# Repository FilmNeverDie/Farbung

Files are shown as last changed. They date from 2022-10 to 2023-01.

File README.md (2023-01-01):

# Farbung

Färbung means colouring in German, and all these effor are infact a way of colouring, thus Färbung. 
A open source project based on FilmNeverDie's CP800 film processing machine.

Project: CP800 

This project is initialized and managed by FIlmeNeverDie. Here, we introduce a rotating drum film developer. Film developing machines are getting outdated and they have run out of support, so the project aims to introduce a series of products that could replace old equipment that has no support and is hard to get replacement/maintenance services. This project provides the resources available for on-going maintenance and product support for film processing within an open-source community, so that anyone can pick up the role as a supplier and maker. We also welcome users to make their own adaptation since the need for each user might be different and the existing variation may not be ideal for each application. Please see CONTIRBUTION for how you can contribute to an existing project, or branch off to your own variant of the machine.  

## Project structure 
 
The project is separated into sections: hardware, firmware, and software 

Hardware includes a list of parts, the relevant CAD files, schematics, and respective documentation such as part lists (BOM), datasheet, user manual, maintenance manual, production manual, and certificates. 

Firmware includes the codes for programming the microcontroller, and its respective documentation such as change log, license, dependency. 

Software includes any software that enhance any parts of either the machines or film processing such as simulation, check system integrity and firmware auto-update, the processing programs generators, photo scanning and processing software and their respective documentation such as change log, license, dependency. 

Contributors will be expected writing and updating the manuals for their own variation.  

There will be a list of verified models and compatibility table that shows the combination of hardware/firmware/software compatible in the front page of each project.  

## Getting Started 

Installations 

### Firmware: 

Arduino IDE with libraries: 

- USB Host shield Library 2.0  

- DallasTemperautre + OneWire 

Get the newest stable version of source code and upload to the arduino, please check the hardware version of your machine if you purchased from FND, and download the respective firmware. 

### Hardware: 
Mechanical:
Fusion 360 
Electronics:
KiCAD5

### Software:

N/A 

## Getting Involved 

The following are areas where we are currently working on: 

Chemical tanks system: float sensors, heating 

Mechanically stronger developing tank (either stainless steel, or better printing) 

Firmware optimization to use dynamics memory less than 5kbB. 

Optional joystick modules (Arduino joystick shield), and USB/BT controller (see USB Host shield Library for the list) 

Onboard low noise low dropout voltage regulation instead of relying solely on the switching mode convertors with various quality depending on the source (see the BOM in hardware section) 

Areas that could be potential development: 

Miniature solenoid valves and poly manifolds fitting.  

Compatible microcontroller other than Arduino such as beaglebone, Rpi, Psoc, others 

Processing program generators (web base or standalone) 

A bigger and high-resolution screen, also new UI/UX, don't mind if you can fit a few “extra functions” in for bored operators to do while processing 

A computer application that searches for the newest firmware to download from GitHub for any verified hardware 

Any other suggestions 

## Documentation

This repo uses [mkdocs](https://www.mkdocs.org) to host online documentation. `mkdocs.yml` is its configuration file, and `docs/` is the directory containing the documentation pages.

## LICENSE: 

This work is licensed under a Creative Commons Attribution-ShareAlike 4.0 International License, except for source code which is licensed under the 3-Clause BSD License.

see LICENSE.md and LICENSE_CC-BY-SA.md for details

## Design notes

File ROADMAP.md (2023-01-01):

# CP800 issues:

1.	flow sensors are too troublesome to adjust, 
    -	need better models?
2.	Tanks need to be more rigid:
    -	Stainless steel casing with 
        -	non-conductive surface for sensor
        -	or a fuse in sensor
    -	Strong design of print 
3.	Solenoid valves rust even when expose to moisture. 
    -	Get a model that has no direction contact between the spring and the fluid
4.	New model of CP800
    -	New chassis design
    -	Smaller volume
5.	Photo flow, and demonetized water final wash. 
    -	Last step of the process

# Future project:
1.	CP800 features:
    -	Temperature control
    -	Full error reporting 
    -	Data logging for error
    -	Deep cycle
2.	Patterson auto-loader
3.	Processing movie films
    -	A list of requirements
4.	Roller transport / pull-thru
    -	Brand new model: (include this in github)
5.	Scanner (include this in github)
    -	Graphic card fails often
    -	AI assisted processing
6.	Dip and dunk (include this in github)
    -	Advantage: Minimal physical contact with film
    -	Challenges:
        -	Large clearance if the film is long
            1.	Could dip and dunk side way, so have a long machine instead of a tall machine
        -	Auto film loader in the machine (dark). 
            1.	Clip at one end
            2.	Pull the film out
            3.	Stop when sensed the end
            4.	Clip the canister end
            5.	Load the film carrier to a hanger for transport
            6.	Start dip and dunking
        -	Manually loading to a hanger
        -	Multiple film roll process
            1.	Allow new film to be auto loaded
            2.	Only engage the loader to hanger when film loading is ready
        -	Auto transfer to scanner via a belt drive system
            1.	Unload the film carrier from the dip and dunk’s transport
            2.	Roll into the scanner 
            3.	Warm air blower will dry the film as it roll into the scanner
            4.	Feed the scanned film into storage

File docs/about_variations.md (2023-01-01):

# Variations

> Note: this section is currently empty, but will contain variation-specific documentation.

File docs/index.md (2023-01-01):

# Welcome to the FilmNeverDie CP800 wiki

## Sample photos: C41 on ECN2

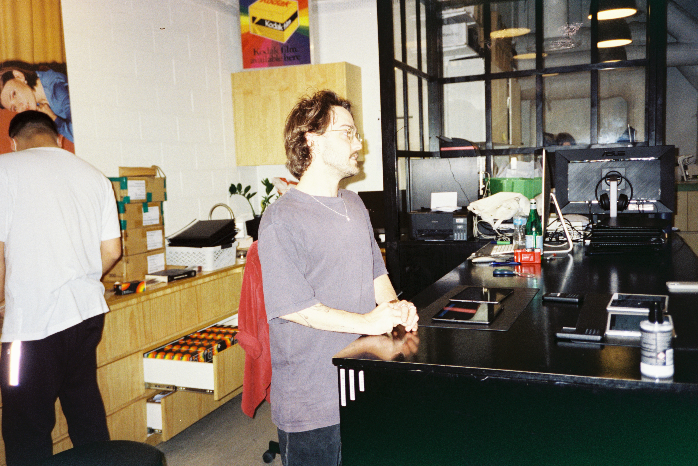
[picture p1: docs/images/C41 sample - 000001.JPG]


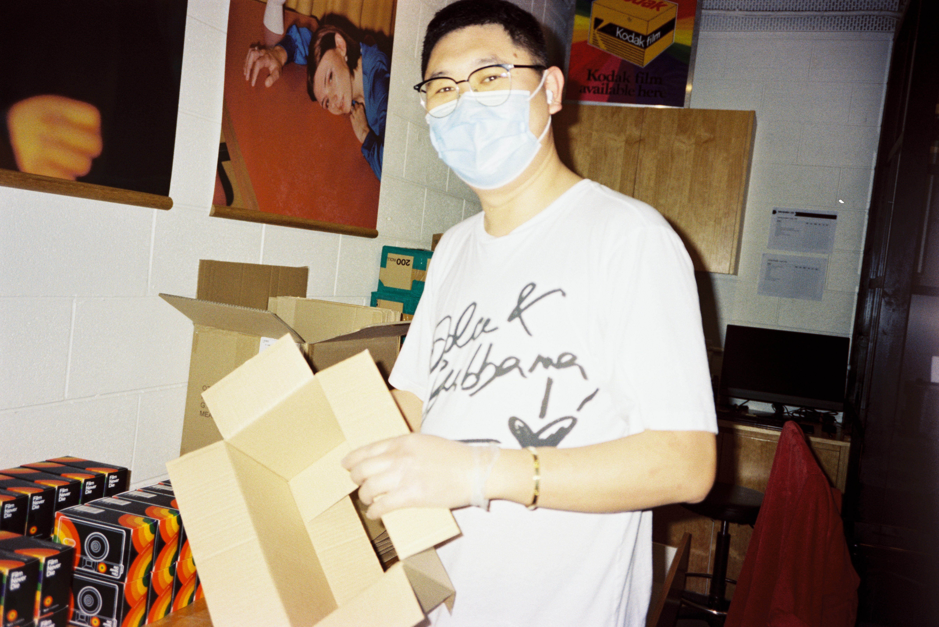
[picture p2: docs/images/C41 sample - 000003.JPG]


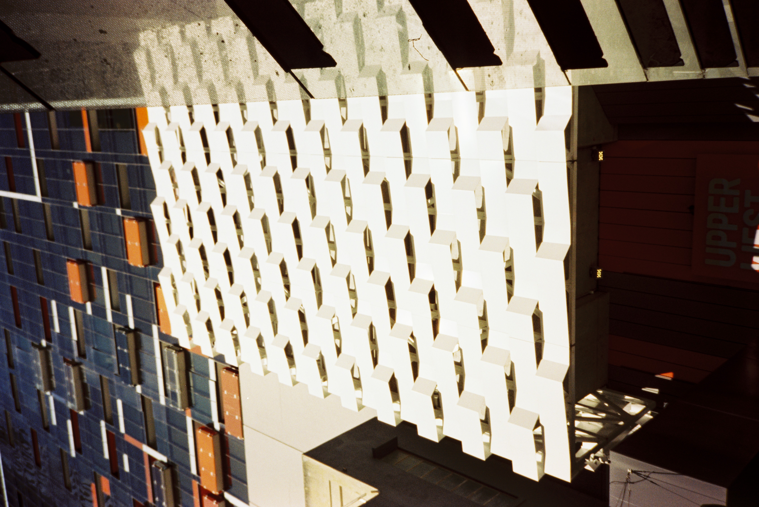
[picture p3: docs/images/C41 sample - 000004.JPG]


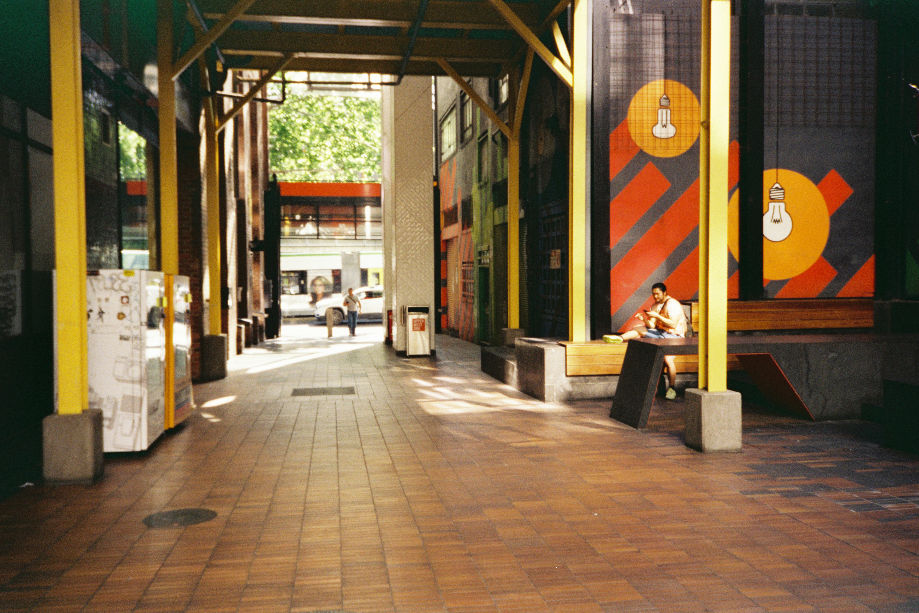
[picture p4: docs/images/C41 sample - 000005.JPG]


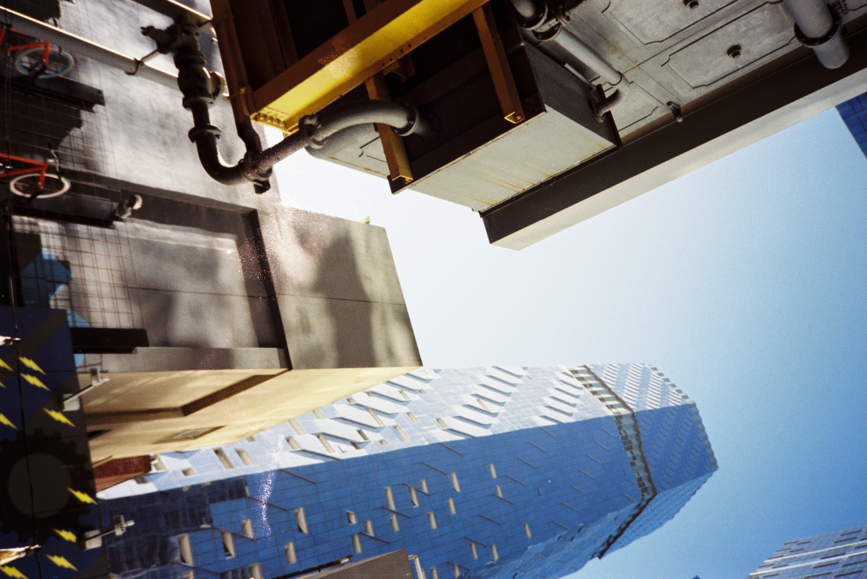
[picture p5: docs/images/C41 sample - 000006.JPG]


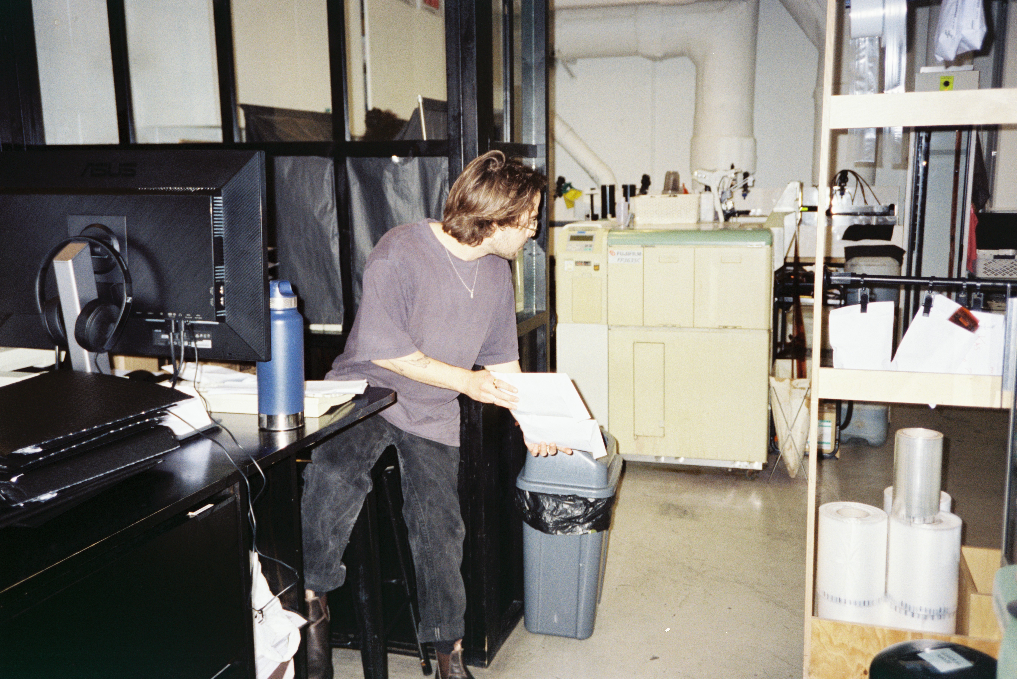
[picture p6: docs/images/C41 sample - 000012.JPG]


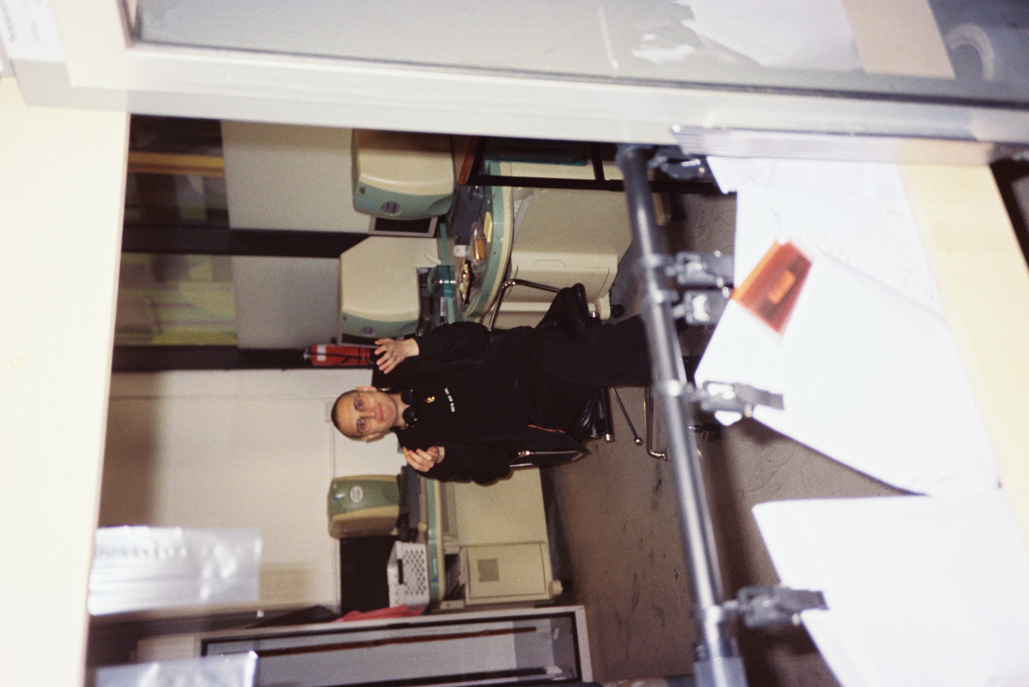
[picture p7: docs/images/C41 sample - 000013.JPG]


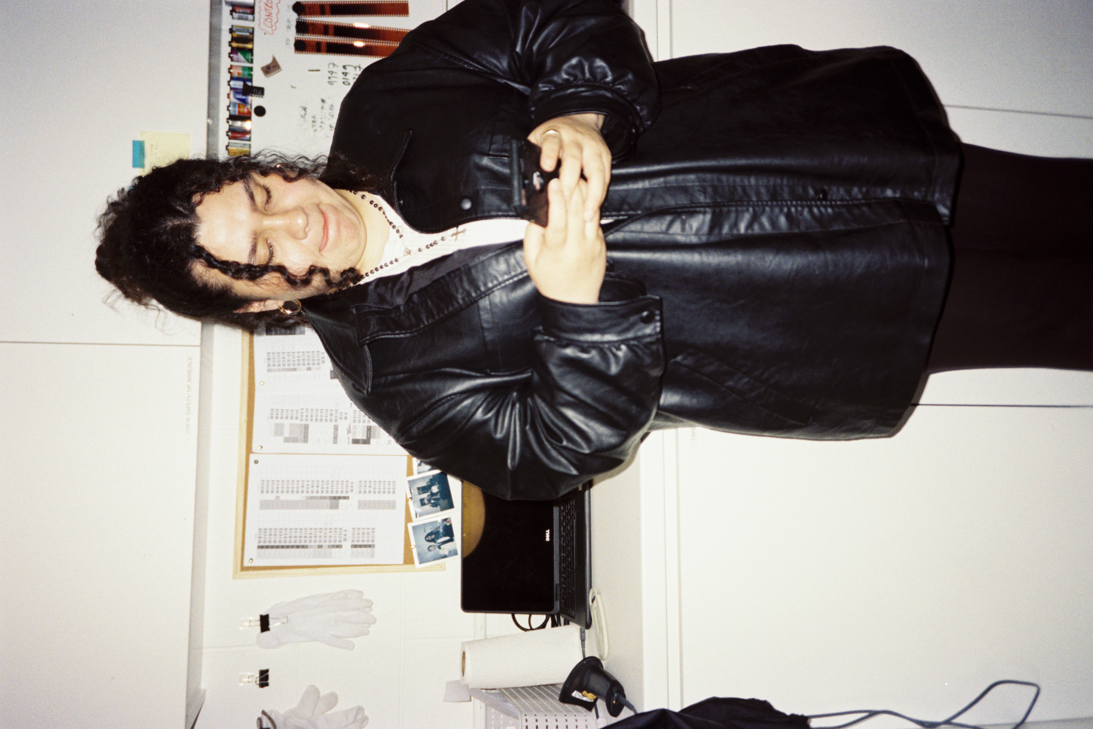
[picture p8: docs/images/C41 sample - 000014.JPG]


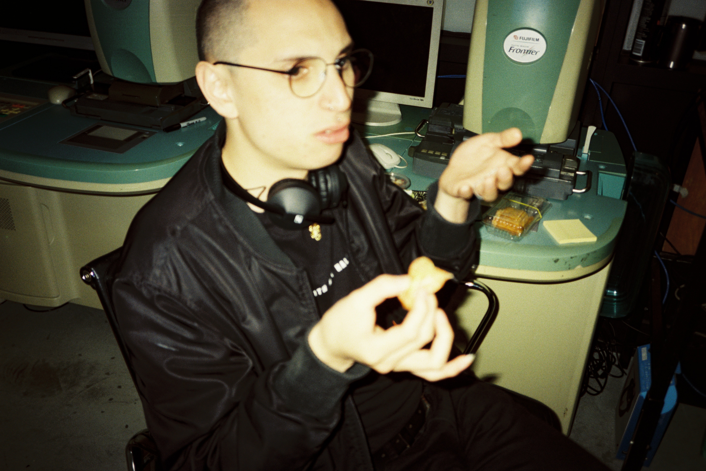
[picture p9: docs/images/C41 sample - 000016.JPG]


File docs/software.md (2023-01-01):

# Software
> NOTE: this section needs a major overhaul, to make it more developer friendly

The user manual has information regarding how to operate the machine. This document is for developers by explaining how the code functions and is structured.

There are a lot of iterations of firmware that are applicable to the microcontroller in CP800. Much of the code is shared between all iteration of the firmware. This document will break the firmware by its function and explain each part of it. There is a log of changes written inside the beginning of the main code so developers track when a feature/function was implemented. Of course, that is not the most comprehensive log, so there might be changes that happened between the recorded date. For the sake of documentation, we assume all data recorded on the log is the date of a committed version of the firmware and all changes to between the commits happen on the latest commit.

# Main Headers

```c
#define model "CP-806"
#define version "1.16.2"
#define PCBver 9
// sense =0 for NO sensor, and =1 for NC sensor
#define OUTsense 0// change this to 1 when use the new flow sensor with the metal band and cable tie
#define INsense 0
```

At the beginning of the code there is a section before the log. This section contains `#define` for the machine. “model” and “version” are not used functionally as of 8th June 2022. However, PCBver is used to define the pinout for the Dpad and user interface inputs. Since there are two functional PCB being used by CP800 as of 8th June 2022. OUTsense and INsense, is used to defined whether the tank level sensor and flow out sensor are normally open (NO), or normally closed (NC) signal. In the future, more metadata could be defined here so other supporting software could identify the machine and hardware associated with that specific model and version of machine.

```c
//#define DEBUG //enable/disable serial debug output
#ifdef DEBUG
#define DEBUG_PRINT(x) Serial.print(x)
#define DEBUG_PRINTDEC(x) Serial.print(x, DEC)
#define DEBUG_PRINTbin(x,y) Serial.print(x, y)
#define DEBUG_PRINTbinln(x,y) Serial.println(x, y)
#define DEBUG_PRINTln(x) Serial.println(x)
#else
#define DEBUG_PRINT(x)
#define DEBUG_PRINTDEC(x)
#define DEBUG_PRINTbin(x,y)
#define DEBUG_PRINTbinln(x,y)
#define DEBUG_PRINTln(x)
#endif
```

`#define DEBUG` serial print via Arduino COM. This allows a global disable on all serial print functions when we don’t want to be debugging. Note that there are still some `serial.print` functions not controlled by this declaration.

```c
void EditsParameters(int editIndex,int arrayIndex,int * Para,int push);
```

There is one function declaration before the main. This function is used to edit existing processing in the ROM. This function required the following dependencies:

- The data type of ROMProgram `struct`
- And Arduino basic library.

> :information_source: NOTE: it is planned to modularize the ROM processing code to have a separate file and header.

The section below the comment:

```c
// button assignment
```

is for the position of each button on the Dpad to the R-2R DAC.
Then the libraries are included below the line:

```c
// includes library
```

Four libraries are active as of 8th June 2022

```c
#include "classes.h"
#include "CP800.h"
#include <OneWire.h>
#include <DallasTemperature.h>
```

`CP800.h` and `classes.h` are defined within the Arduino script folder. LiquidCrystal , `OneWire.h` + `DallasTemperature.h` could be installed and updated with libraries manager on Arduino IDE.

Following the comment:

```c
//pin assignment
```

Are the pin assignments for most GPIO for joystick shield, SPI com, motor interface, valves interface, buzzer, fluid sensors.
For the button variables:

```c
byte UIcommend; // debounced byte commend to the system from UI inputs
byte UIinputs; // before debounced
int de_button;// debounced signal from the Dpad buttons
int editing = 0; // default program editing is off
int menu_skipupdate=0;
```

`UIcommned`, is the debounced 8 bits signal for the microcontroller, this includes the buttons digital inputs with the 6 MSBs. The 2nd LSB indicated whether the cursor can travel through the columns, whereas the LSB indicated whether the cursor can travel through the rows.

`UIinputs` are the raw signal from the 6 inputs from Dpad

`de_button` is the debounced signal for UIinputs

Editing is a flag to indicate whether the user is in editing mode or not, see “editing processing” in the user manual.

`menu_skipupdate` is a flag to control whether the menu is being updated or skipped. Might use a better name

These variables are mainly interfacing with the `UIcursor` and `UImap` classes which contain the information where the cursor is on the menu, and where in the mapping of the menu. The final inputs are input to the `buttonAction` subroutine, where the microcontroller reacts to the new inputs every program cycle.

```c
//LCD
#include <LiquidCrystal.h>
#define rs 42
#define ee 43
#define d4 44
#define d5 45
#define d6 46
#define d7 47 //LCD Pin
#define bl 36
LiquidCrystal lcd(rs, ee, d4, d5, d6, d7);
```

For the LCD, a new library is included, `LiquidCrystal.h`, and a set of pin assignment is `#define` correspondingly to the object imitation of the LCD, see LiquidCrystal object constructor for how to initiate a LCD object with the library.

```c
char lcdBuff0[21];
char lcdBuff1[21];
char lcdBuff2[21];
char lcdBuff3[21];
char lcdBuffPrevious0[21];
char lcdBuffPrevious1[21];
char lcdBuffPrevious2[21];
char lcdBuffPrevious3[21];
```

The LCD screen used has 4 rows of 20 characters. Four `lcdbuffer` are made to store each position of the LCD. Four more are made to store the previous screen which are currently not used.

```c
//menu
//menu structure see attached document
int menuRow = 0;
int menuColumn = 0;
int infopage = 0; //there will be multiple info page as we expand the complexity
const String menuTop[] = { //top tier menu text
...}
const String menuSetting[] = { //declear settings menu
...}
```

`menuRow` is the row number that the cursor/mapping is currently in
`menuColumn` is the column number that the cursor/mapping is currently in
Infopage is the page number that the user is currently viewing
`menuTop` is a character array with words that are shown on the top menu
`menuSetting` is a character array with words that are shown on the setting menu

```c
//edit menu
int editIndex = 0;
int editPara[19]; // edipara is a array, mostly will be only using the first entry
int arrayIndex = 0;
bool editmenuEnd=0;
```

Three variables are declared under editing menu. These variables are used when the user is in editing ROM program mode.

`editIndex` is the index that indicates the current variable the user is editing. Please see EditsParameters function to see how the entire processing program is flattened and how each data is indexed

`editPara` is the value which the index is referring to. There are several types of datatypes, depending on the indexing the data in the array interpreted as different data type, please refer to EditsParameters function for future information

`arrayIndex` is the index for the character array, processName[].

`editmenuEnd` is a flag for rather the edit menu reached the end or not

```c
//I/O Check
bool outputCheckAction = 0;
//Input/Output Check Mode
bool IOCheckMode = 0;
int IOIndex = 0;

```

Three variables are declared to be used when the user is in the IO check mode in the setting menu, see user manual for how to navigate to the IOcheck menu

`outputCheckAction` toggles the action state of each active element of the machine from the menu, typically the component is switched on when this value is 1, such as motor, pump, valve ...etc

`IOCheckMode` indicates if the program is in the IO check menu. This enables the IOIndex to be changed, because the program has entered IO check mode

`IOIndex` is the index that shows which input or output the user is currently checking. Refer to inputCheck() and outputCheck() to see how all inputs and outputs are arranged into an array.

```c
//declear process matrix
String processPara[8][20] = { //6 process + 2 clean process
  {}, {}, {}, {}, {}, {}, {}, {}
};
int processTemp[8] = {0, 0, 0, 0, 0, 0, 0, 0};
uint16_t processTime[8] = {0, 0, 0, 0, 0, 0, 0, 0};
uint8_t processTotalSteps[8] = {0, 0, 0, 0, 0, 0, 0, 0};
bool processParaSet[8] = {0, 0, 0, 0, 0, 0, 0, 0};
//process name
String processName[6] = {"---", "---", "---", "---", "---", "---"};
```

`processPara` is an array of 8 with 20 strings each. String is used here because it is made using the old data format where all parameters are compiled into a String datatype

`processTemp` is the temperature value for each process

`processTime` is the duration of each process

`processTotalSteps` is the number of steps in each process

`processParaSet` is the flag that say whether the process has be set (loaded from storage)

`processName` is the name of the process

```c
//processing data
//timer
unsigned long timer = 0; //system timer (mS)
long timeJump = 0; //jump forward time for testing (mS)
#define iniDelay 200 //delay in setup (mS)
```

Then we will introduce all the data use in processing

For timers:
Long timer is a system timer where it will update every loop

`timeJump` is an accumulated varaibles that will increase or decrease the timer values (currently unused)

`iniDelay` is the delay amount in ms introduce in the for several component when machine is booting up. These include loading processes from ROM, initiating LED, initiating motor.

```c
//refresh timer for lcd etc.
unsigned long refreshTimerA = 0; //timer for less frequent refresh (ms)
unsigned long refreshTimerB = 0; //timer for frequent refresh (ms)
#define refreshInterval 500 //time for lcd refresh (ms)
```

`refreshTimerA` regulate what get update, currently it is at 4 times of `refreshInterval` which is 2s. These processes are LED, LCD, read temperature
`refreshTimerB` regulates what get updated, currently it is at refresh interval rate which is 0.5s. These processes are controlling the motor, controlling the processing, or the cleaning process.

```c
//agitation
byte agitationSpeed = 0; //0: ~20RMP 1: ~18RMP 2: ~16RPM
unsigned long agitationTimer = 0; // S
const int agitationTime1 = 10; // S
const int agitationTime2 = 2; // S
```

`agitationSpeed` determines the speed setting of the motor, this could be expanded to the values of a byte

`agitationTimer` is not used

`agitationTime1` and `agitationTime2` are used to create the pattern of motion during processing. The pattern is forward, stop, backward and stop, then repeat.

```c
//parameter of process
bool processState; //process runing state (0:not running 1:running)
int processNo; //runing process (0-7)
bool steppingmode=0; //default =0 : sensor mode, 1= fixed timer
unsigned long processStartTime = 0; //start time of current process
```

`processState` is the flag showing whether the machine is running a processing or not

`processNo` shows which process from the menu is selected to be processing

`steppingmode` shows how the steps in a process are going to progress. Sensor mode means the step progress to the next step depending on the feedback sensor, fixed timer means the step progress to the next only depending on a fixed amount of time.

`processStartTime` marks the timer instance where a new processing has begun.

```c
//parameter of clean process
byte processStateClean; //process runing state for clean process (0: not runing 1: clean 1 process 2: clean 2 process)
byte processCleanCycles;
```

There are supposed to be two cleaning processes, they are both currently not programmed. From the order of adding and removing fluid. Clean 1 is having the both add and remove are active depending on a processing array.

```c
//parameters for current step
bool stepState = 0; //step state (0: processing of this step is not done 1: processing of this step is done, ready to drain tank)
String stepName[20] = {"----"};
uint8_t stepNo = 0;
uint8_t stepIn[20]; //which port to add chem
uint16_t stepTime[20]; //time for processing (S)
uint8_t stepOut[20]; //which port to dump chem
bool stepPush[20]; //if this step is subject to push/pull 0:no 1:yes
bool flowin=0;
bool flowout=0;
int stepout = 0; // use to record what stepOut[stepNo] is, unused
unsigned int stepTimer1 = 0; // begining of adding chem
unsigned int stepTimer2 = 0; // beigning of process the drum, stopped adding chem
unsigned int stepTimer3 = 0; // begining of removing chem, stpped the drum
bool stepParaSet=0; //flag of step paratmeter are set, and ready to go
//push/pull
int push = 0; // the value of push/pull selected on the menu (this is loaded into the processing later)
```

Within the processing, each step has timing and parameters that define their actions.

`stepState` shows whether the processing of the film in this step is done, if done start draining tank fluid and prepare for the next step

`stepNo` shows sequential order the step is in the processing

StepName shows the name for a step

`stepIn` and `stepOut` shows which valve port which are used in the step

`stepTime` is the duration of the step

`stepPush` enable/disable the step to be pushed/pulled. Push: increase time of processing of this step, pull: reduce time of processing of this step

`flowin` is a flag made to force the chemical to flow in by the user at any time during the step which the processing is currently in

`flowout` is a flag to force the chemical to flow out of port 6 during the process, this is used for emergency flow out in case the other valves are somehow blocked during the processing. Please refer to the user manual.

Stepout is supposed to record the value of stepOut the processing was, so that an interrupted operation could be done and yet the processing could continue by pushing this variable back into stepOut (currently unused)

`stepTimer1` is use to time the adding chemical stage of the step

`stepTimer2` is use to time the rolling processing stage of the step

`stepTimer3` is use to time the removing chemical stage of the step

`stepParaSet` shows whether the step parameters are loaded and ready to go

`push` is the value of how much time are increase/decrease (push or pull) for all the pushable steps in the current processing

```c
//error Message
String errorMessage = "";
unsigned long int popuptimer=0;
```

`errorMessage` is a String for displaying the message when an error incurred

`popuptimer` is a time variable for displaying a message on LCD, this is updated to the newest time, so the popup message will display for a duration of time after this variable is updated

```c
#include <EEPROM.h>
int strByteLen = 200; //String Length limit in bytes
int addrShift = 0; //to shift byte for wear leveling
```

EEPROM is one of the options to store and recall processing, all parameters are stored as a byte array.

`strByteLen` is currently defined as 200 bytes. Detailed structure of the stored array is in the comment section of the CP800.h tab.

`addrShift` is supposed to be a random 8 bits value that shifts the ROM address, in order to achieve wear leveling. The array will have a wrapping order from 256 back to 0. However, the wrapping is not yet programmed. Currently not use.

```c
#include <SD.h>
#include <SPI.h>
#include <stdlib.h>
int SD_err =0; // 0: no err, 1: SD.begin error, 2: file load err, 3: step data load err
int program_no = 0; // count the number of program stored in the SD card file
int loadtype=0; // 1 is SD, and 0 is ROM, default from ROM
int validROMprogram[6] = {1,1,1,1,1,1}; //0: invalid, 1:valid
```

Load all libraries required to use SD module on Arduino

`SD_err` is the value that returns from attempt to initiate the SD module

`program_no` is the number of processing program stored on the SD card; the program indicator is located at the beginning of each processing program. More details for the data structured store on SD card are described in “process_data” tab

`loadtype` determines how processing program is loaded, either from SD card or EEPROM

`validROMprogram` is an array of flags to indicate which programs stored in the EEMPROM have a valid data structure. If there is no legit program header found in each memory slot, the function will change this array of the corresponding index to 0, so loading on those program entries will be skipped.

```c
//digital Temperature Sensor
#define tempPin 27 //DS18B20 signal bus
OneWire oneWire(tempPin); //Temperature chip i/o
DallasTemperature sensors(&oneWire);
//Temperature Control
float tempCurrent = -10.0;
float tempTarget = 22.0;
```

Currently temperature is not use in anyway. This is merely a template for future expansion for now.

#define pin 27 to be the onewire bus

Instantiation of the onewire object to be the define above

Instantiation of the dallas temperature sensor to be the one wire bus device

`tempCurrent` and `tempTarget` are the current and target temperature of the sensor. `tempCurrent` actually doesn’t need initialization.

```c
//instanstation of object
Led Led(LED_woke);
Buzzer buzz(buzz_pin,volume_pin);
SixWay_valve addChem(add_s0,add_s1,add_s2,add_pump);
SixWay_valve removeChem(remove_s0,remove_s1,remove_s2,remove_pump);
agitationMotor agitationMotor(motor_on, motor_dir, motor_PWM);
bathPump bathPump(soak_pump);
//tankLevel tankLevel;
//soakLevel soakLevel;
digilevel drumHI(drum_high,LEVEL_SAMPLE_SIZE, INsense );
digilevel drumempty(drum_empty,LEVEL_SAMPLE_SIZE, OUTsense);
//analoglevel chemtanks_full();
//analoglevel chemtanks_half();
//analoglevel chemtanks_low();
analoglevel soakLevel(tanks_full,LEVEL_SAMPLE_SIZE);
AC_heater heater(heat_PWM);
joystick joystick(KEYA,KEYB,KEYC,KEYD, KEYK, JOYX, JOYY);
Dpad_analog panel_UI(Dpad_in_pin, Dpad_refH_pin, Dpad_refL_pin);
UIcursor user_navi(&UIcommend);
UImap menu_navi(&UIcommend);
```

Now we instantiate all objects needed to operate the machine with the variable we declared previously:

1. LED
2. Buzzer
3. 6ways valve for both inlet and outlet
4. Motor
5. Bathpump, currently no corresponding hardware
6. Digital level sensor for inside the tank and along the outlet tube
7. Analog level sensors are not used
8. The heating element using AC power
9. Joystick shield
10. Dpad interface as the UI
11. The cursor location on the screen is the user
12. The location displayed on the screen is the menu

# CP800.h

This header tab is made to contains classes and global variable for those classes in the CP800 series

```c
#include "pitches.h"
#define arrayLength(array) (sizeof((array))/sizeof((array)[0]))
#include <LiquidCrystal.h>
#include <EEPROM.h>
```

Libraries used in the classes : `pitches.h`, `EEPROM.h`, `LiquidCrystal.h`

`pitches.h`: has the buzzer value to make different notes and function to generate pre-defined tune

LiquidCrystal is the library for display on the LCD

EEPROM is the library for accessing the EEPROM on Arduino

`arrayLength` is to calculate the size of an array using sizeof()

```c
bool zero_crossed=0;
int maxcol=3; //maximum number of col to be display (shift colume by left and right)
int rowstack[8][2];//a matrix that stored the row value for both the user cursor and the menu map
int colstack[8][2]; //a matrix that stored the col value for both the user cursor and the menu map
int actionstack; // the variable to restore which action the menu is selected
String lcdStr[4] = {"", "", "", ""};
int ispageEnd = 0; //flag indicaitng the end of the menu page
int pagerow = 4; //default is four
```

`zero_crossed` is the flag to indicate whether the AC input of the heating has crossed zero. This allows a fixed energy cycle for the PWM cycle within a certain time error

`maxcol` is the variable that allows users to shift left and right in the menu to see different information

`rowstack` is the data matrix that stored the row coordinate of both the user cursor and menu map

`colstack` is the data matrix that stored the column coordinate of both the user cursor and menu map

`actionstack` is the value for the action that the machine is taking, this is normally on the last page in the menu, where the user has to pick a function or run a program. The previously two stacks are for the location of the menu through each layer of the selection on the menu.

`lcdStr` is the array of 4 strings to be displayed on the LCD

`ispageEnd` is the flag for indicating the menu had reached an end page, a page where you have to select an action and no more option to be select after that

`pagerow` is the number of rows on the current menu page. Usually 4 rows, given the screen has 4 rows, but main menu and program selection has more, and allow scrolling down

```c
//this is the view in which the LCD is looking at
struct camera{
  int col;
  int row;
  int row_size;
  int col_size;
};
```

The `camera` struct contain the coordinate of the camera and the size in each dimension to be seen by the camera. Imagine it to be the view range of a person on the map.

# Class UIcursor

```c
class UIcursor {
  private:
    byte* _inputsRef;
    byte _inputs;
    byte _Previnputs;
    int _rowlimit=3;
```

Private variables include:

`_inputsRef` is the pointer to the input variable

`_inputs` is the variable that take the new inputs

`_previnputs` is the variable that stored the previous inputs

`_rowlimit` is restricted to row 3 (4th row) , because cursor cannot move out of the screen

```c
    void limit(int *row, int *col){
      if (*row>_rowlimit) *row=_rowlimit;
      if (*row<0) *row=0;
      if (*col<0) *col=0;
    }
```

The private function `limit()` restricts the value of row and column between 0 to the `upperlimit`, so far only row has an upper limit for the cursor

```c
public:
    int row=0;
    int col=0;
    int layer=0;
```

`row`, `col`, `layer` fully describe the location of the cursor on the map

```c
    //pass the input pointer to the private variable
    UIcursor (byte* inputs){
      _inputsRef = inputs;
    }
```

Instantiate the class by passing a pointer of a byte

```c
    void begin(){
      //initiate inputs
      _inputs = *_inputsRef; //when begin, load the value of the input pointer to _inputs
      _Previnputs = _inputs; // initailise the previous as current inputs
```

Initialize the class by taking the input from the pointer and make previous input the same

```c
// can overwrite the current location of the cursor to any positon on the map
    void wrappoint (int wraprow, int wrapcol, int wraplayer){
      row=wraprow;
      col=wrapcol;
      layer=wraplayer;
    }
```

Public function to edit the current location of the cursor to any value

```c
// update cursor from the inputs given the number of row to be displayed and wehter it is a end page
    void Update(int isEnd, int displayrow){
      _inputs = *_inputsRef;
      _rowlimit = displayrow-1;
      // shift between menu layr with A and B
      // ULRDAB
      bool A = (_Previnputs>>A_shift & 1) & ~(_inputs>>A_shift & 1);
      bool B = (_Previnputs>>B_shift & 1) & ~(_inputs>>B_shift & 1);
      if (A){
        rowstack[layer][2] =row;
        colstack[layer][2] =col;
        //stop incrementing if page is an end page
        if (isEnd!=1){
          rowstack[layer][2] =row;
          layer +=1;
          // new coordinate for new layer
        }else{
          actionstack = row; // which row is pressed on the action page/end page
        }
        // return row and col anyway after pressing A, too hard to see respawn without changes, updated 202011130
        row = 0;
        col = 0;
        if(layer>3)layer=3;
      }else if (B){
        //use 0 to destroy the layer for returning operation
        rowstack[layer][2] = 0;
        colstack[layer][2] = 0;
        layer -=1;
        if(layer<0)layer=0;
        row = rowstack[layer][2];
        col = colstack[layer][2];
        //clear after unloading into the cursor positoin
        rowstack[layer][2] = 0;
        colstack[layer][2] = 0;
      }else{
```

The update function is the core function of the class. It updates the position of the cursor by reading and interpreting the buttons inputs, when the update is called.

The button shift defined in header will now be used to isolate the A and B button, these buttons confirm or cancel an action.

When press A:

1. Stored the current row and column position to the stack
2. If this is the end page, row value is the action option, if not, we increment the layer
3. Then reset row and column position to 0 as we are either doing a new action,
4. Since no page is beyond layer 3, restrict layer increment when reached end, this could be redundant if mapping and tracking is done better
   When press B:
5. Reset current position to zero in stack
6. Decrement layer
7. Load previous layer position
8. Clear the previous location from stack

```c
 }else{
        /*
         * row increment when the down button signal transit from 1 to 0
         * row decrement when the up button signal transite from 1 to 0
         *
         * commend switch to col if the menu allow colum
         *
         * non blocking operation for all direction (could be using in game mode)
         * ULRDAB
         */
        row += (_Previnputs>>Down_shift & 1) & ~(_inputs>>Down_shift & 1) & _inputs& 1;
        row -= (_Previnputs>>Up_shift & 1) & ~(_inputs>>Up_shift & 1) & _inputs& 1;
        // we may not need col position for the cursor
        col += (_Previnputs>>Right_shift & 1) & ~(_inputs>>Right_shift & 1) & (_inputs>>1 & 1);
        col -= (_Previnputs>>Left_shift & 1) & ~(_inputs>>Left_shift & 1) & (_inputs>>1 & 1);
        limit(&row,&col);
      }
      // restore previous inputs
      _Previnputs = _inputs;
    }
};
```

When press other buttons

1. Increment or decrement row value if press up and down while row shift bit is enabled (`_inputs&1`)
2. Increment or decrement column value if press left and right while row shift bit is enabled (`_inputs>>1&1`)
3. Check and limit row and column according to the boundary of the menu page
   Always, update input to previous input at the end

# Class UImap

This class is very similar to `UIcursor`, in fact, it could be position to generalise both `UImap` and `UIcursor` class into one class.

```c
class UImap{
  private:
    //map has a camera datatype to contain the dispaly size and location of the menu
    camera _mapCam;

    byte* _inputsRef;
    byte _inputs;
    byte _Previnputs;
    int _rowlimit=3; //default typical 4 row, 0-3

    void limit(int *row, int *col){
      if (*row>_rowlimit) *row=_rowlimit;
      if (*row<0) *row=0;
      if (*col<0) *col=0;
```

All except the inclusion of camera struct is the same as `UIcursor`. Camera structs allow `UImap` not only the position but the range of location that is visible

```c
    void begin(){
      _mapCam.row=0; //start at the top
      _mapCam.col=0; //start at the left
      _mapCam.row_size = 4; //default dispalying 4 row of character
      _mapCam.col_size = 19;//default dispalying 19 character
      //initiate inputs
      _inputs = *_inputsRef;
      _Previnputs = _inputs;
    }
```

Initialize class with camera values, and camera sizes are fixed

```c
void wrappoint (int wraprow, int wrapcol, int wraplayer)
```

Exact same function as `UIcursor`

```c
    void Update(int isEnd, int displayrow){
      _inputs = *_inputsRef;
      _rowlimit = displayrow-1;
      // shift between menu layr with A and B
      bool A = (_Previnputs>>A_shift & 1) & ~(_inputs>>A_shift & 1);
      bool B = (_Previnputs>>B_shift & 1) & ~(_inputs>>B_shift & 1);
      if (A){
        colstack[layer][1] =col;
        if (isEnd!=1){
          rowstack[layer][1] =row;
          layer +=1;
          // new coordinate for new layer
          row = 0;
          col = 0;
        }else{
          actionstack = row;
        }
        if(layer>3)layer=3;
```

Update mirror the `UIcursor`

```c
      }else{
      /*
        row += (_Previnputs>>Down_shift & 1) & ~(_inputs>>Down_shift & 1) & _inputs& 1;
        row -= (_Previnputs>>Up_shift & 1) & ~(_inputs>>Up_shift & 1) & _inputs& 1;
        // we may not need col position for the cursor
        col += (_Previnputs>>Right_shift & 1) & ~(_inputs>>Right_shift & 1) & (_inputs>>1 & 1);
        col -= (_Previnputs>>Left_shift & 1) & ~(_inputs>>Left_shift & 1) & (_inputs>>1 & 1);
        limit(&row,&col);
      }
      _mapCam.row = row;
      _mapCam.col = col;
      // restore previous inputs
      _Previnputs = _inputs;
    }
};
```

The camera will also be updated.

# Class Buzzer

This class required the `pitches.h` header

```c
  private:
    uint8_t _in_pin,_rh_pin,_rl_pin;//inputs, reference high, reference low
    int _init_volt,_init_rh,_init_rl; //initial reading of each pin
    int _new_volt,_new_rh,_new_rl,_dVolt; // new input of each pin, and a change of voltage value
    int _old_volt=0; //old voltage value
    int _threshold = 15;//default threshold to ignore noise is 9 over 1024 volt
    float _shift_ratio=0; //the rati of voltage shift over the refrence voltage range as a linear scale from initial volts to new volts
    int _ref_range;// range of reference voltage , reference high - reference low
    bool _button_reg_set=0; //default assume release
    bool _edgetrigger=0; //edge trigger flag
    long _edgetiming=0; //edge trigger timing
```

`_in_pin`, `_rh_pin`, `_rl_pin`, are the Dpad input pin, high voltage reference pin, low voltage reference pin respectively

`_init_volt`, `_init_rh`, `_init_rl`, are the initialise reading, in `Begin()` from the input pin, high voltage reference pin, and low voltage reference pin respectively

`_new_volt`, `_new_rh`, `_new_rl` are the new reading from the input pin, high voltage reference pin, and low voltage reference pin respectively

`_dVolt` is a variable to calcualte the difference between two votlage reading

`_old_volt`, is the `_new_volt` in the previous update

`_threshold` define the deadband in which the program ignore the fluctuation of the voltage reading in the input pin

`_shift_ratio` is a ratio to represent relative voltage change, the full equation wil be defined in `Update()`

`_ref_range` is the variable used to store the value between the high and low reference voltage

`_button_reg_set` is a flag is indicate whether a button is pressed, 0 is pressed, given input are pulled up

`_edgetrigger` is the flag for an edge has been triggered

`_edgetiming` is the timing when the edge triggered.

> :information_source: NOTE: might be neater to compress these pin reading into a data array, and the update operate could iterate through the variable instead of calling each variable individually.

```c
class Buzzer {
  private:
    uint8_t _buzz_pin; //which pin is the buzzer
    uint8_t _vol_pin; //the voltage of the buzzer (1 of two preset value)
    uint8_t _welcomeMelody[2] = {NOTE_B5,NOTE_A5}; // welcome tones
    uint8_t _welcomeMelodyDuration[2] = {250,250}; //duration for welcome tones
```

Buzzer has 4 private variables;
`_buzz_pin` contain the pin number for the buzzer
`_vol_pin`, controls the MOSFET that boost the current to the buzzer
`_welcomeMelody` is a two notes array that make noise when bootup,
`_welcomeMelodyDuration` is the timer period for each note in the welcome tune

```c
  public:
  //Constructor
    //constructor without volume pin
    Buzzer(uint8_t buzz_pin){
      _buzz_pin = buzz_pin;
    }
    //constructor with both pin and volume
    Buzzer(uint8_t buzz_pin,uint8_t vol_pin){
      _buzz_pin = buzz_pin;
      _vol_pin = vol_pin;
    }
```

Two constructors

1. Without volume control
2. With volume control

```c
// play any single note
    void play_Note(int Note, int duration){
      tone(_buzz_pin,Note,duration);
    }
    // play an array of notes
    int play_array(uint8_t Note_ary[], int note_len,uint8_t duration_ary[], int dura_len){
      //check either of them are empty
      if(note_len==0||dura_len==0){
        return 2; //type 2 error: empty inputs
      }
      // check if the duration matches the Note in size
      if (note_len != dura_len){
        return 1; //type 1: error array doesn't matches
      }
      for (int playnote=0; playnote<note_len; playnote++){
        //cychle thru each note in array with cooresponding duration
        tone(_buzz_pin,Note_ary[playnote],duration_ary[playnote]);
      }
      return 0;
    }
```

Play note function only play one note with one duration

Play array function cycle thru all the note in array and match the duration

```c
// rountine to play welcome tune
    void welcome(){
      play_array(_welcomeMelody,2,_welcomeMelodyDuration,2);
    }
    // routine to play nothing
    void no_note(){
      noTone(_buzz_pin);
    }
```

The `welcome()` subroutine plays the welcome tune using `play_array()`

There is a subroutine that play nothing

```c
    // inistilising the buzzer pins
    void begin(){
      pinMode(_buzz_pin, OUTPUT);
      pinMode(_vol_pin, OUTPUT);
    }
```

Initialize class by setup buzz and volume pin as output in Arduino

```c
    //write high
    void vol_HI(){
      digitalWrite(_vol_pin, HIGH);
    }
    //write low
    void vol_LO(){
      digitalWrite(_vol_pin, LOW);
    }
};
```

`vol_hi` function connects the buzzer ground with a low resistor value using MOSFET, low resistor more current thus louder

`vol_lo` function cut off the buzzer ground with a low resistor value using MOSFET

# Class Dpad_analog

```c
class Dpad_analog{
  //digital Dpad would be separate to avoid excessive memory allocation
  public:
    byte status_reg = 0b11111100; //button inputs are pulled high
    //status reg that show which button is being pressed
    //NOTE: the full voltage of the DAC is about 82.6% of the uC HIGH output

    //constructor
    // 10 bits analog input version , CP-800 use this
    Dpad_analog(uint8_t input_pin, uint8_t ref_high_pin, uint8_t ref_low_pin){
      _in_pin = input_pin;
      _rh_pin = ref_high_pin;
      _rl_pin = ref_low_pin;
    }
```

Dpad `status_reg` records the status of the Dpad which are the 6 buttons inputs plus row and column shift enable bit at the end

Constructor with inputs to `_in_pins`, two analog pin for the high logics voltage and low logics voltage

```c
    void begin(){
      pinMode(_in_pin, INPUT);
      pinMode(_rh_pin, INPUT_PULLUP);
      pinMode(_rl_pin, INPUT);
      _init_volt = analogRead(_in_pin);
      _init_rh = analogRead(_rh_pin);
      _init_rl = analogRead(_rl_pin);
     // _old_volt = _init_volt; //record init voltage input as previous voltage input
    }
```

Initialisation routine define

1. `_in_pin` as input, output from DAC IC
2. `_rh_pin` as input pulled up, for high voltage
3. `_rl_pin` as input, externally pulled down, for low voltage
4. Read all inputs pin to initialize values

```c
    // check if there is a update on Dpad inputs
    int checkupdate(){
       return(_old_volt>_new_volt+_threshold || _old_volt<_new_volt-_threshold);
    }
    int Ispressed(){
      return 1-_button_reg_set; //return 0 if pressed
    }
```

The `checkupdate()` routine return 1 when new value is `_threshold` difference from the old values

`Ispressed()` returns 0 when a button is pressed

# Future development

- Optimization of RAM usage
  - Remove global variables that are not used
  - More modularized code and use local variable.
  - Better way to store tune and menu option (mainly const chr/int)
- More buttons and better structure button classes
  - Currently the respond is are only 6 buttons, directions + AB, this should be expanded to respond to a more complex controller and allow more action from the user
  - Allow a more efficient way to quick travel to another location or return to previous location, A systematic set of coordinates in the mapping might help.
  - The structure for the mapping on the menu and cursor should remain separated, imagine the cursor is the user’s character, and it is navigating the menu as if it is an RPG. Both the POV of the environment and the chr have to react to the user’s inputs.
- Better ROM read/write addressing. Currently the ROM programs are referring to a set of fixed addresses. This could result in an imbalance number of read/write for some memory unit, and thus worn out those units quicker than others.
  - New writing methods should consider the health of each ROM unit and maximize their life by using dynamic indexing, to avoid overwriting existing ROM units.
  - The new method should also repeat old information in a new region. It would be ideal to reuse a step from another processing cycle than write a new step, since many step between different processing can be shared, such as rinse with water.
  - maybe using wear leveling technique to use each ROM cell evenly. However, this might nullify the ROM.update() function where data is only update when there is a change to it
  - Better still, to use a data compressing method that maximised reusing existing variables and trimmed data to be stored.
- Better code organization
  - Tabs can be combined/separated according to their function/hardware/other arrangement
  - There could be a classification of different header for different purpose, to further modalized the codes, this might allow an entire feature to be reuse in another project.
- UI
  - Generise `UIcursor` and `UImap` with a navigation class that has position value

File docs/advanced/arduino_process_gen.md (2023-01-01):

# Instruction: writing program with Arduino script

This is for developers and makers only; the SD card should be programmed
with a more user-friendly method such as web apps. this Arduino script
used to program the SD card is for generating examples for testing the
functionality of loading programs from Sd card, as the name suggests, it
is made to test to store program on SD cards.

Please locate the arduino code: `test_storeProgams.ino`, and make a copy
for you to change the programs. Keep the original file, so it is a
backup.

Please follow the hookup guide to setup the hardware and Arduino before
you make a change to the script. We are using the big SD module, but
they all work in the same way as long as they are hooked up correctly
for the SPI communication.

<https://randomnerdtutorials.com/guide-to-sd-card-module-with-arduino/>

<https://create.arduino.cc/projecthub/electropeak/sd-card-module-with-arduino-how-to-read-write-data-37f390>

## Step 1: Setup the constants

There are three sections of constants you need to define just after the
headers



The first set is the pin assignment for the SD card port, please refer
to the Arduino board for the pin number of the SPI communication

The second section only has one constant that is the name of the file
where you stored the programs, on default it should be a misspelt
document called "progroms.txt", this file could also be renamed later
use a PC by editing the filename.



The last section is the file specific constant, these describe the
general configuration for all the programs hold in this file

The constant of numberofprogram indicates the number of programs you
wish to store in the fie. The constant array of stepName is a lookup
table for the stepCode to indicate what each step is in each process,
please expand the list of stepName with as many variations of step you
have on your machine.

## Step 2: filling in the parameters

There are two set of parameters that need to be filled out, one set is
for each processprogram on the programlist. These parameters describe
the processes of all programs in the files.

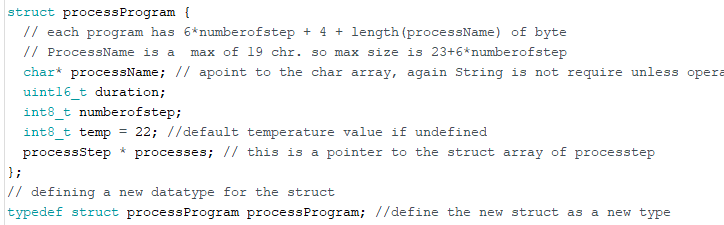
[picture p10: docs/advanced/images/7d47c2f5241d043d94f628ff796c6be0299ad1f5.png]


The structure of `processProgram` contain a
`processName`, the duration of the entire process, the number of steps in
the process, and the temperature of the entire process, following by the
pointer to an array of process steps that contain the parameters of each
step.

Change these parameter is the `setup()` section of the code.
`ProcessProgram` should be right after `Serial.begin(115200)`;

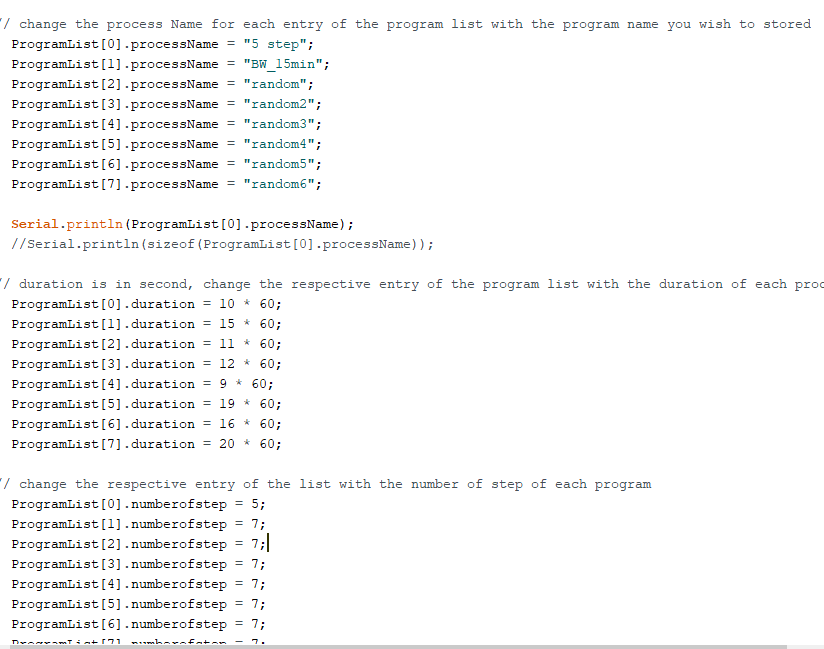
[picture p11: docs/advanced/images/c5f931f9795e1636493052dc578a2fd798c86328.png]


1.  Name your program within the ProgramList array for each processName
    variable. This could be any name as long as it is below 20
    characters long

    > NOTE: due to the constraint of the memory on the Arduino, it could only
    > load up to 6 different programs, so `ProgramList[6]` and
    > `ProgramList[7]` will never get use.

2.  for each program, type the duration in second to the duration
    variable in each `ProgramList`. Min value: 0, max value: 65,535

3.  type the number of step for each program on `ProgramList` array.
    Min value: 1, max value: 255

4.  type the temp for each program on `ProgramList` array. Min value:
    1, max value: 255

There is no need to define the processes now, we will do it in the next
section.

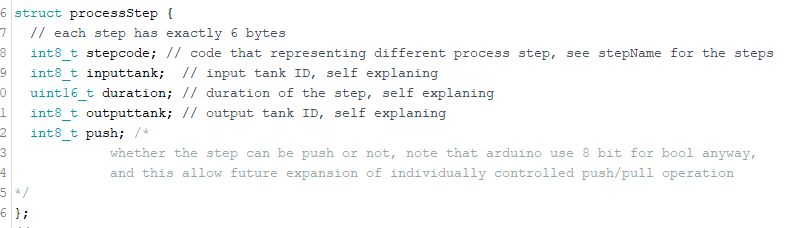
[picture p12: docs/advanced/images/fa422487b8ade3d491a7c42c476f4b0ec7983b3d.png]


The other set is for each step within each
program on the program list.

In each step of the process, the step contains the stepcode where
`stepName[stepcode]` return the name of the step, the input tank number,
the duration of the step where the film is bath in the chemical, and the
output tank number, and a flag to indicate whether the step can be
push/pull.

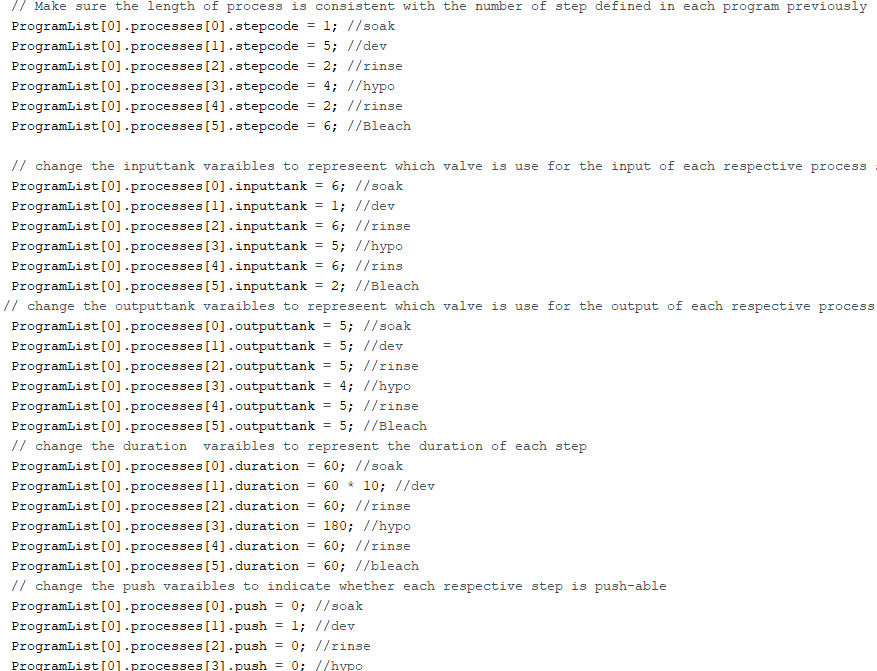
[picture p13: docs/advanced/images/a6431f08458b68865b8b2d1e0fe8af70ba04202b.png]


Please copy and paste each line for the variables: `stepcode`, `inputtank`,
`outputtank`, `duration`, `push` to the number of steps you define in the
program section. And then change the value of each variable within the
structure.

The default code contains 8 different programs and the value for the
parameters are placeholder values. Please add more by copy and pasting
the entire list of steps for each program to the number of programs you
defined in Step 1. Please remember to change the index of `ProgramList` so
you are writing a new program in the list not overwrite the old one you
copied the list of steps from.

For each step, the 5 variables of each step have to be filled within
each program. The index should be consistent with the number of steps
you defined in the respective index of program on the ProgramList. The
default should be a long list of placeholder values. Please edit the
code so that the index of process is consistent with the numberofstep
variable defined. None of the step should be skipped or left blank.
These steps should be repeated for each program on the ProgramList.

1)  Step code is the code representing the name of the step from the
    `stepName[]` array defined in Step 1. min value: 0, max value: 255

2)  `inputtank` is the solenoid valve you want your step to use for the
    input chemical, CP800 only has 6 input port, so the valid range of
    value is 1-6 inclusive, any other number will cause error. min
    value: 1, max value: 6

3)  `outputtank` is the solenoid valve you want your step to use for the
    output chemical, CP800 only has 6 input port, so the valid range of
    value is 1-6 inclusive, any other number will cause error. min
    value: 1, max value: 6

4)  Duration is the duration for the step, do not confuse it with the
    duration for the program you defined for the program. Min value: 0,
    max value: 65,535

5)  Push indicate whether the step is pushable, 0 mean no, and 1 is yes.
    If the step is pushable, the push and pull value given before the
    start of the processing will affect the duration of this step, only
    accept 0 or 1 value, anything bigger than 1 is equal to 1. min
    value:0, max value:1

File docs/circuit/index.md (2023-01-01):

# Description
The CP800 circuit is designed to fulfil the function of developing films
with drum rolling and it consists of the following requirements

1)  Control the fluid flow of developing film

2)  Control the temperature of the fluid

3)  Control the motor for the rolling action

4)  User interface

## List of features in planning

Please read this in conjunction with the software plan, since back-end
development of the software will be highly tied with the hardware
development.

-   Multiple heating element array control, if each storage chemical
    needs to be kept at a different temperature

-   Temperature PID controller (software)

-   Allow the use of 100VAC, there will be a transformer to step down
    higher AC voltage to 100VAC, this allows the machine to work in
    country with a different phase voltage, by converting them all to
    100VAC.

-   Program the microcontroller to control the backlight of the LCD
    screen if required. (software)

-   Program that allows a selection to read from the digital input of
    the Dpad via the serial output from the shift register. (software)

-   Implement an on and off software button using the LED button mounted
    on the Dpad. (software)

-   Earth all solenoid to a common point.

-   Overvoltage and undervoltage protection

-   Quick self-diagnosis button or additional debugging display (led on
    communication\...etc)

-   Float sensor feedback for each storage tank

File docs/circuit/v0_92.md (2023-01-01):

# V0.92 (in machine after )

Changes:

1)  Removed pull up resistor for direction pin of the motor

2)  Number of extra pins reduced

3)  One additional IDC socket for joystick shield

4)  Pin out header socket for USB host shield, required one additional
    stacking pins

5)  Removed the extra ICSP pins, it is now used by the USB host shield

6)  Use one 5V LDO (AMS1117) onboard required low voltage input of at
    least 6.5V

7)  Arduino mage gets power from Vin around 6.5V and signals powered
    from onboard 5V LDO (AMS1117)

8)  One PISO shift registers for Dpad buttons input are available
    instead of the R-2R ladder analog output to buttons

9)  Red onboard LED for reverse voltage input for both 12V and low
    voltage terminals

10) Green onboard LED for forward voltage input for both 12V and low
    voltage terminals

11) Mounting holes increase from M3 to M4, holes position remains the
    same

12) Size of board increase in the X-axis

## Power circuit

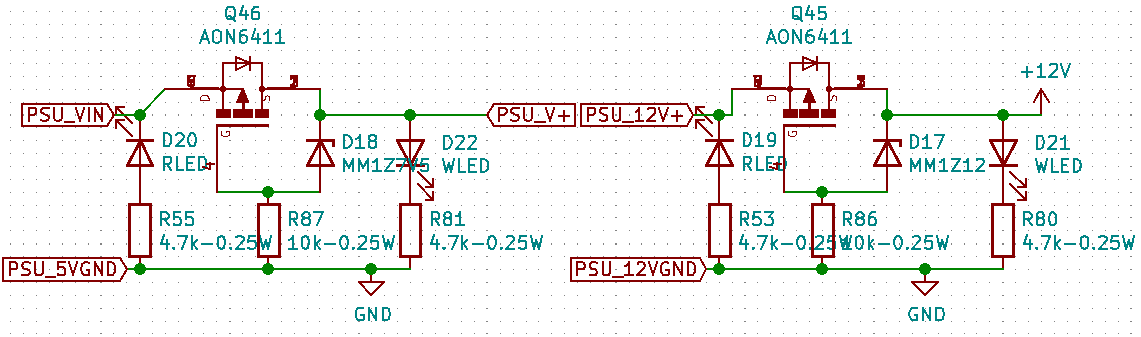
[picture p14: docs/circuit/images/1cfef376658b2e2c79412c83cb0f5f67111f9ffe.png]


Both 12V and low voltage (6.5V) from the external switch converter are
reverse polarity protected with low on resistance p-channel MOSFET and
Zener diode.

When reverse polarity occurred, the pMOSFET will shut down the main
circuit from the high voltage side, but the red SMD LED will turn on as
an indication for the user that they had reversed the input leads

When the correct polarity is inserted, the pMOSFET will shunt the high
voltage side leads, and activate the green SMD LED.

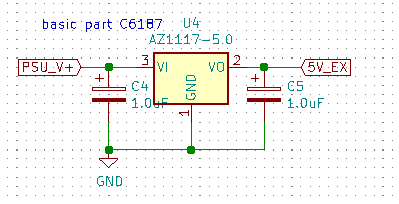
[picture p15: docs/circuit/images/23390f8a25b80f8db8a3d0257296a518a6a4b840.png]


One additional 5V regulator is implemented to share the loads required
by the 5V sources. This is the same chip as the 5V LDO on the Arduino
mega pro mini

In the schematics diagram, 5V is the one powered by the Arduino, while
all 5V_EX connection is powered by this additional chip.



There are four power connectors, one is the input from the 12V PSU, one
is the 12V output after the reverse polarity protection, one is low
voltage input from the buck converter, and the last one is an extra
header for a 5V reference.

## Pumps control

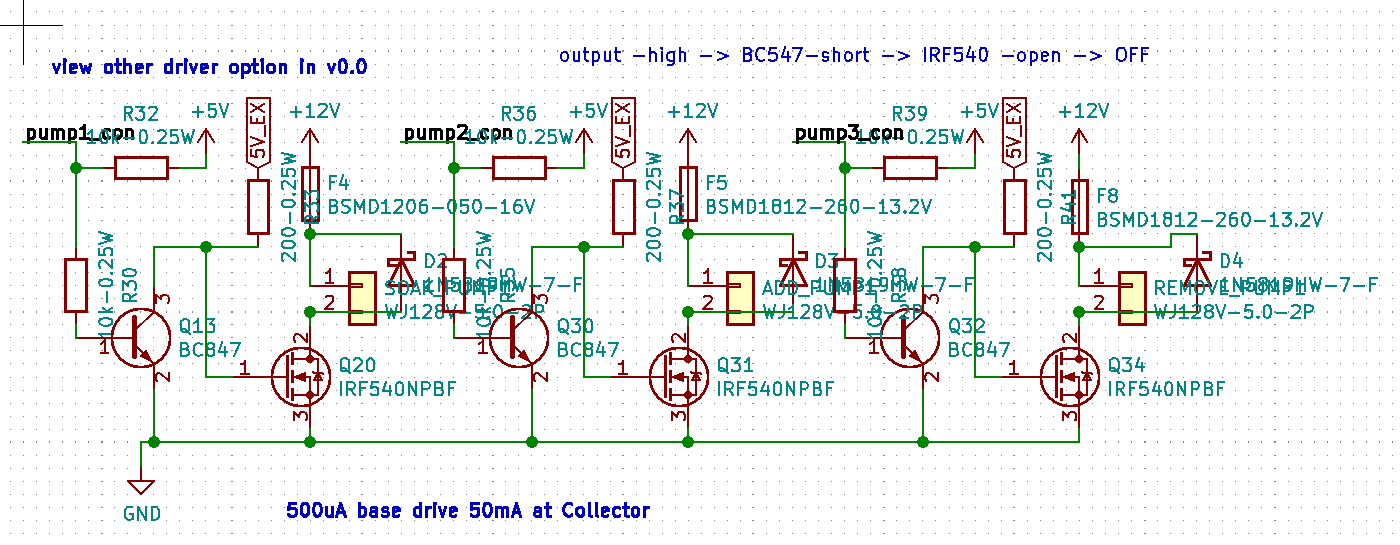
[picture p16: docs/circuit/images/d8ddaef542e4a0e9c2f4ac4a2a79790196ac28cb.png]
Remain unchanged

## Motor control

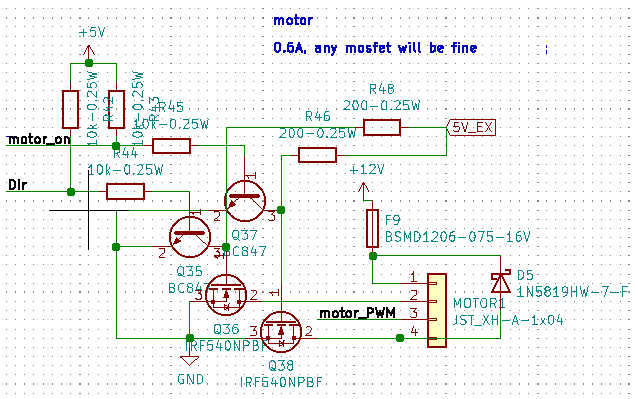
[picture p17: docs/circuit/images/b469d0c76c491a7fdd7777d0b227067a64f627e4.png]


The only changes made are the direction pin of the motor. Now the pin is
left floating/disconnected if it is not shorted to GND for backward
direction

The change is made because the motor we used is not a raw motor, it is a
DIR and PWM controlled motor. Therefore, there is a controller board
inside the motor assembly. Depending on the quality of the motor, if
there is a current path inside the motor assembly, the additional pull
up resistor outside the assembly will affect the voltage level on that
pin.

Also, according to the product datasheet, the DIR pin could be left
disconnected for forward direction, thus proving there is an internal
pull up inside the motor assembly.

The rest is the same as the previous version.

## Solenoid valves control

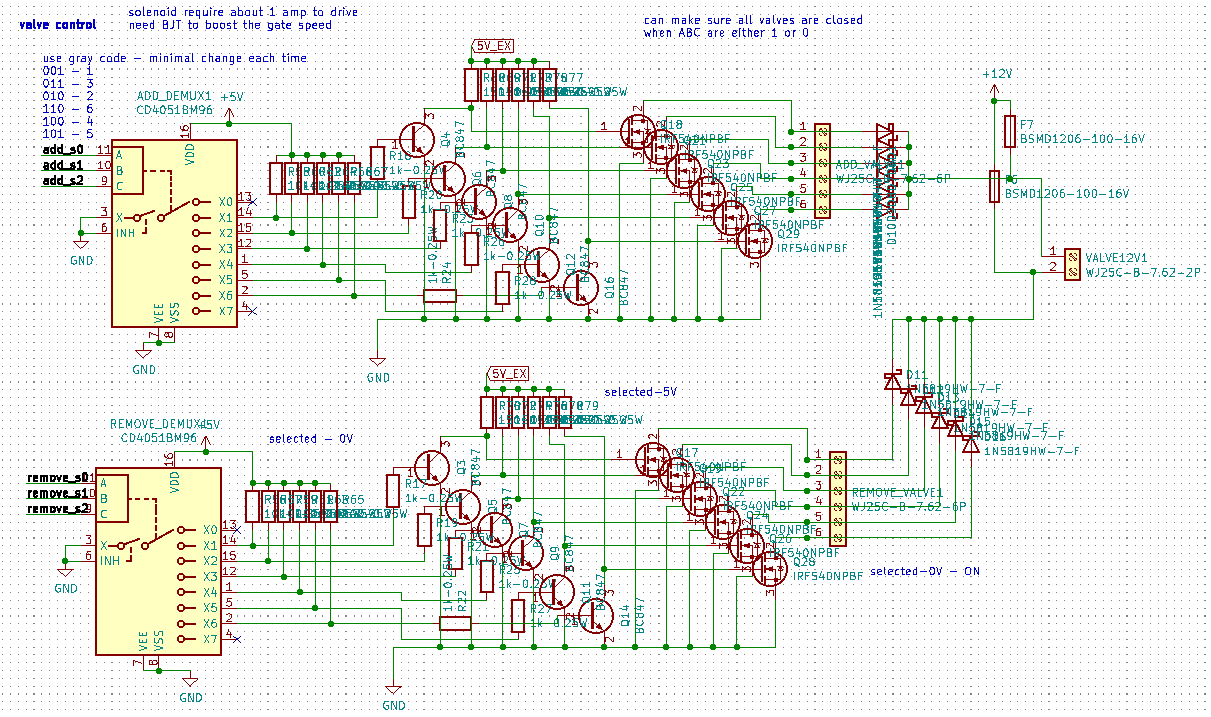
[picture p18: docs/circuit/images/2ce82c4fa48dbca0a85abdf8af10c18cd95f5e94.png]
Same as previously

## User interface

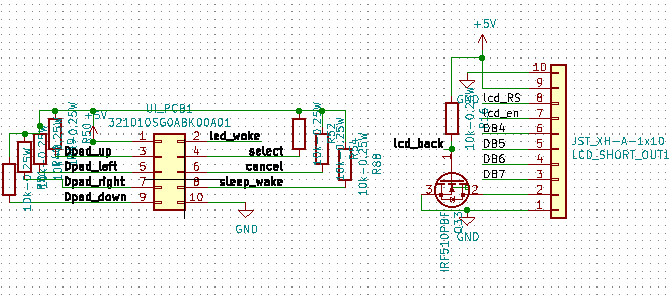
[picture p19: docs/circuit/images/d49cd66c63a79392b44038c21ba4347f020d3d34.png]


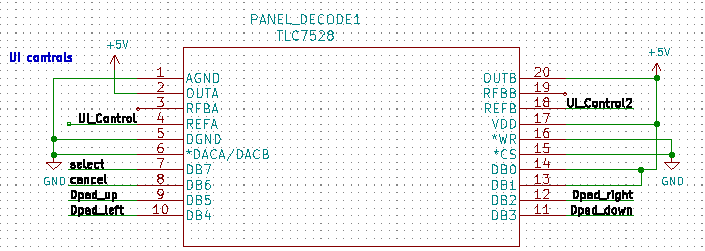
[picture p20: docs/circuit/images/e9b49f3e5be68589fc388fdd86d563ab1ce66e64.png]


The Dpad function works as previously

In v0.92, there are two additional components added for the user
interface

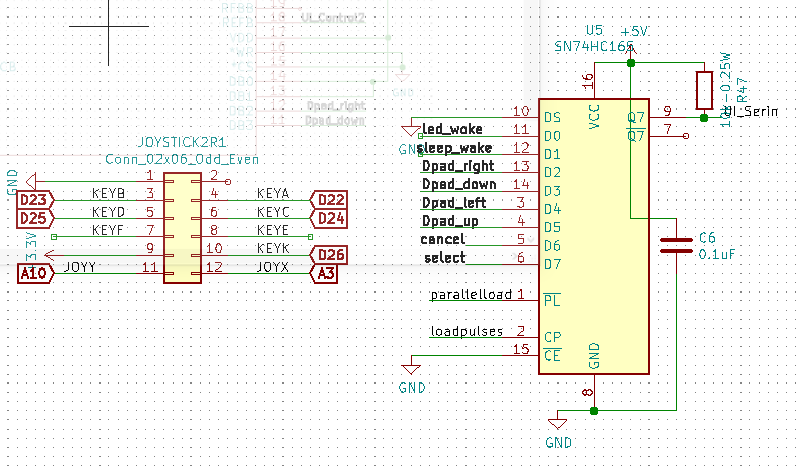
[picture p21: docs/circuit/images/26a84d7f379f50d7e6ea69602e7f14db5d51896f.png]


Firstly, the 12ways IDC connector allows the microcontroller to
interface with Arduino joystick shield. Since we don't plan to use key E
and F, they are left disconnected with the microcontroller here. This is
a optional addon, the Dpad functions as usual without the connection
with joystick shield, and the joystick shield will work simultaneously
with the Dpad.

The addition of a parallel in and series out shift register allows pure
digital signal to be transmitted to the microcontroller for all the Dpad
buttons. This required additional programming that allowed the signal to
be read via the UI_Serin input for all 8 buttons.

## Heating element

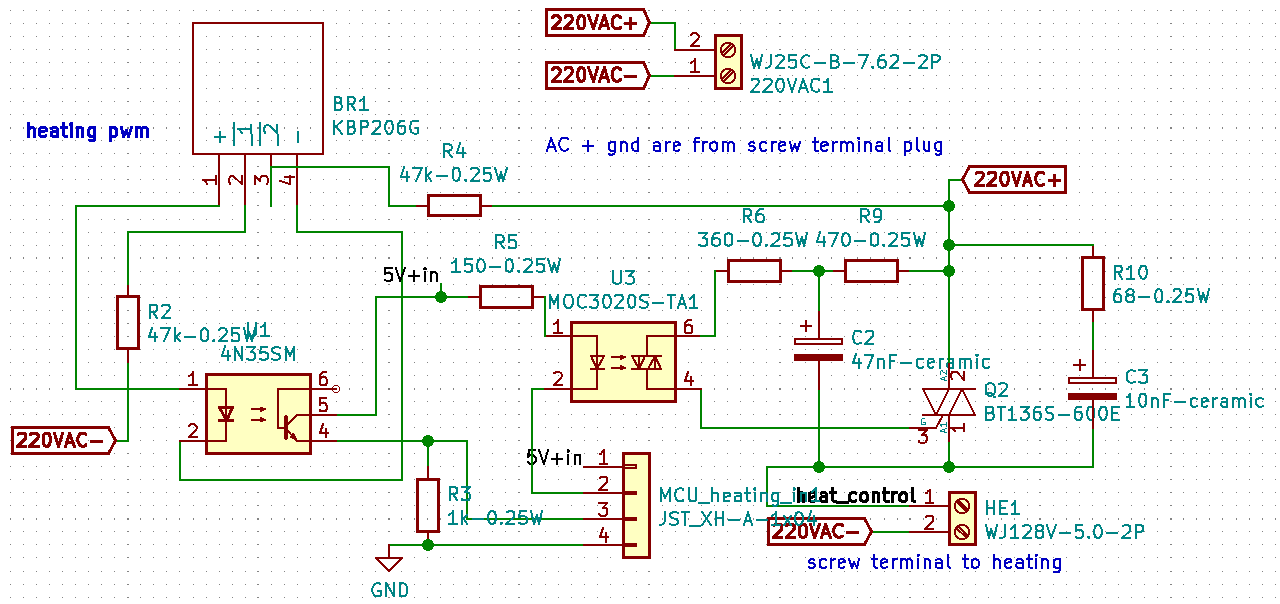
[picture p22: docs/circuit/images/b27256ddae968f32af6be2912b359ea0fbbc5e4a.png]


Same as previously

But, DO note that MOC3020, and 4Nm5 might need to be changed to other
equivalent components due to availability.

## Arduino USB Host shield dock

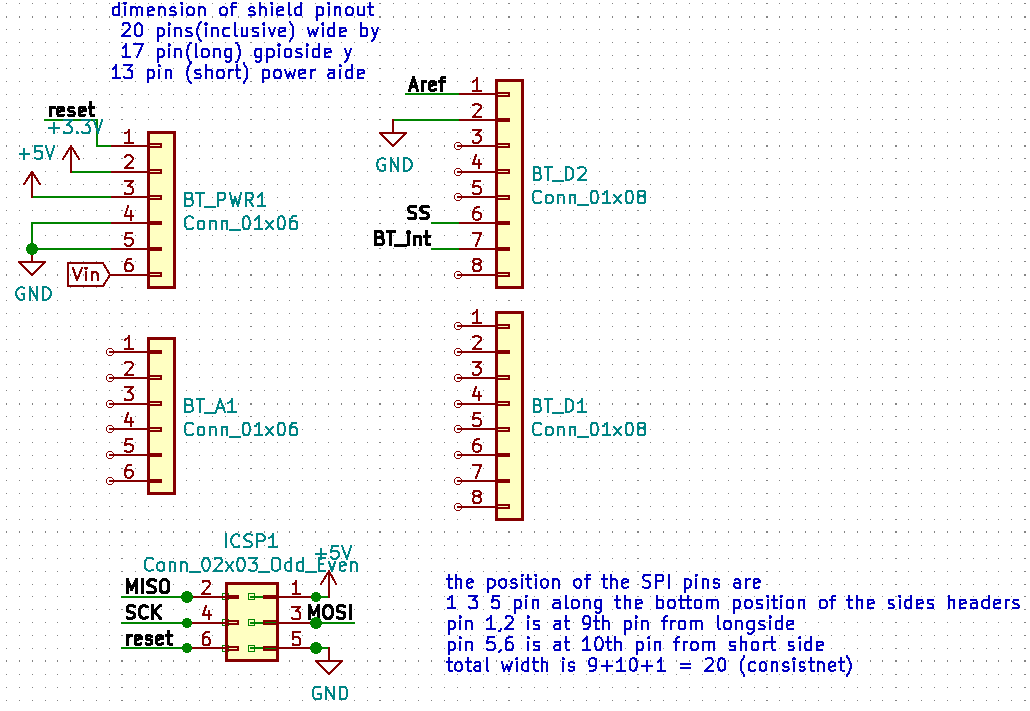
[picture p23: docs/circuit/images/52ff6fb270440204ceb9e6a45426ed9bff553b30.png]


This layout allows the Arduino USB Host shield to be connected simply by
docking it over these docking headers. Most of the bypassing digital and
analog pins from the shield are unuse. They are included for structural
reasons.

The USB host shield converts the USB signal into SPI interface to the
microcontroller.

This has been tested and used with a Bluetooth USB dongle, and
communicates with a PS5 controller to act as the user interface to
navigate the menu.

## Sensors

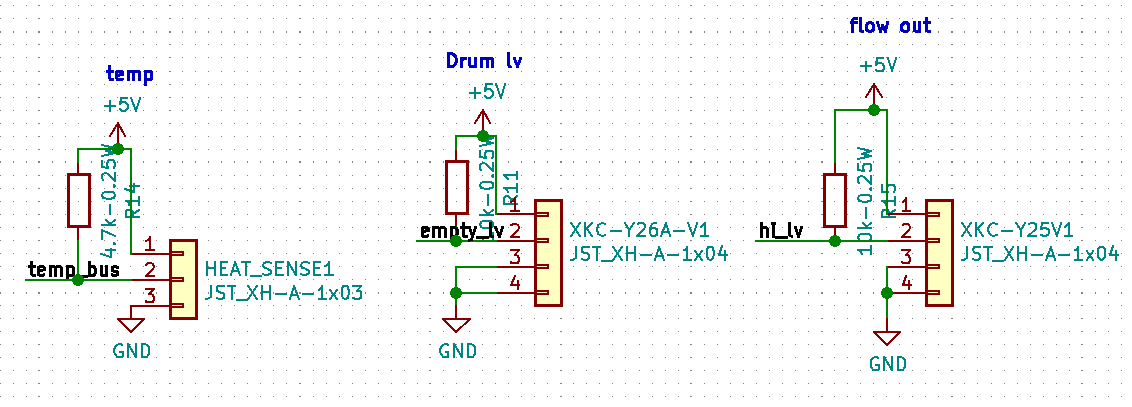
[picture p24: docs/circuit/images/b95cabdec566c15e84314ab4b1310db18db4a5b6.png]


Same as previously

## Buzzer



Same as previously

## Communication Ports



Same as previously

## Microcontroller pinout

The left side of the picture is the header arrangement
on the board for docking the arduino board. The right is the labeled
pinout of the Arduino.

A additional fuse is added to the Vin to the Arduino board, since in
v0.9, power is feed via the 5Vport of the Arduino bypassing the 5V LDO
onboard.



Extra pin unused pin is group to an extra IDC header for future
expansion. This has been significantly reduced due to the module
expansion and component compatibility from v0.9 to v0.92.

The firmware is made backward compatible, so the program being uploaded
to this board that processes all the added component to this iteration
of PCB can also be uploaded to v0.9 without causing a bug. However, all
new features in v0.92 will not reflect on v0.9 unless the corresponding
extra pins are wired externally.

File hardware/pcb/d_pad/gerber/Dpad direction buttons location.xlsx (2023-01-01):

 | nx | ny
up | 98.425 | 60.833
down | 98.425 | 85.979
lef | 85.852 | 73.406
right | 110.998 | 73.406
A | 138.938 | 68.453
B | 126.238 | 84.963

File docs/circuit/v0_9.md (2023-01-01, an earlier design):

# V0.9

The original working prototype for CP800

The function of the board is broken down into the following sections:

1)  The power transfer to each of the components below

2)  The pumps

3)  The motor

4)  The fluid sensors feedback

5)  The solenoid valves for flow control

6)  The user interface

7)  The heating element

## Power circuit



Both 12V and 5V comes from the external switch converter and are reverse
polarity protected with low on resistance p-channel MOSFET and Zener
diode.

The Arduino is powered via the 5V pin bypassing the LDO that required a
higher voltage to power. And all 12V and 5V components will be supplied
by these two voltage sources.



There are four power connectors, one is the input from the 12V PSU, one
is the 12V output after the reverse polarity protection, one is 5V
voltage input from the buck converter, and the last one is an extra
header for a 5V reference.

## Pumps control



There are three output ports for pumps. They are 2pin output.

Each pump is driven by a power MOSFET to switch them on and off with a
low side BJT transistor as the gate driver.

A high output in the microcontroller will allow gate to discharge thru
the BJT quickly, and achieve a faster turn off of the pumps. Meanwhile,
a low output on the microcontroller will turn the BJT off, and the
MOSFET gate is charged thru the low resistance pull up resistor, to
achieve a regulated turn on time.

The pull up resistor in the microcontroller signal pin is implemented in
the case where these pins are not programmed. The pull up resistors will
ensure the pump is off when these pins are not programmed.

Fuses are installed to prevent over current, and a flyback Schottky
diode is used to limit voltage surge by the induction load from the
pumps.

## Motor Control



The motor control is very similar to the pump control as they are both
inductions loading presumably.

The motor we are using has 5 pins control: PWR, DIR, PWN, FB, GND. We
don't use the current feedback wire, so it is left out of the port
output intentionally.

The motor is then connected to the 4 pins JST XH output on the board.

In order to turn on the motor, we need the PWE pin to be 12V, and the
GND pin to be 0V. There is a fuse of the appropriate current to limit
over current, and there is a flyback Schottky diode to limit voltage
surge.

Both DIR and GND pins are controlled by power MOSFETs to switch between
12V and 0V. A pulled up resistor of 12V is in place for the DIR pin, so
there is a default DIR of rotation for the motor, if the pin is left
hanging.

The low side BJT allows a quick discharge of gate, and the low
resistance pull up allows a fixed time fast charging up to the gate.

The pulled up in the microcontroller pins are to make sure the DIR and
0V pin are forced to 12V and keep the motor off, if these pins are not
programmed by the microcontroller.

## Solenoid valves control

Both add and remove valves are controlled in the same
way. Since solenoid is a highly inductive load, we have to apply a
voltage of 12V across each pair of contact on the solenoid block.
Similar to motor and pumps, a fuse to protect from over current and
flyback Schottky diode for voltage surge.

Each solenoid is switched on and off by a MOSFET with a low side BJT
driver for fast drain in gate and a pulled-up resistor in case of
unprogrammed microcontroller pins to the demultiplexer, CD4051.

## User interface



There are two connectors between the motherboard and the Dpad board.
These control the user interface. The 10ways IDC connector is the
connection with each button and LED on the Dpad. The 10ways JST XH
header is the signal going to the LCD screen.

The screen is turned on and off by MOSFET, the program is currently
locked to stay on. Future programming is required to control the
backlight.



The signal from the Dpad will be processed by a DAC with a R-2R
structure, to convert the 6 inputs from the Dpad to a binary coded 8bit
voltage. Note that only UIcontrol analog signal is used, the second
output is left connected. Now.

## Heating element



The heating element chosen is one that is powered by AC 240V input, at
the connector, HE1.

KBP206G is the rectifier to convert AD into DC voltage.

The 4N35SM photocoupler will convert the rectified wave and generate an
on and off 5V signal to the microcontroller to locate the zero-crossing
point of the input wave. This will allow the microcontroller to align
the output from this zero-crossing moment if necessary.

MOC3020 is the photocoupler, between DC to AC using a triac. This
component allows the microcontroller to sink the current at the cathode
(the negative, pin 2) of the MOC3020 diode. Allowing the microcontroller
to control the pulse powering the heating element by driving the BT1365
triac.

R6, R9 and C2, are there to protect the MOC3020 from load, and R10 and
C3 form the snubber to protect the triac.



Additional cutout on PCB to increase the effective isolation between the
240V on each contact of the rectifier.



The AC circuit is located at a different part of the PCB, and the pinout
for controlling the heating element is done by a 4ways connector as
shown above. A jumper cable will be required to connect this connector,
MUC_HEAT_OUT1, with the one input 4ways connector, MCU_heating_IN1,
connection the MOC3020 and 4N35 IC.

## Sensors



There are three main sensors: temperature, tank high level, and flow out
sensor

Temperature sensor is currently unuse, it is supposed to serve as the
feedback to control the heating element. It is using a one-wire bus to
transmit its digital data. The sensor used here is DS18B20.

The tank high level sensor is a 4 pins socket connecting to a
capacitance sensor mounted to the tank and will trigger a on signal when
the water level is raised.

The flow out sensor is a 4 pins socket connecting to two capacitance
sensors clipped to the outlet tubbing from the tank to the solenoid
valve, and will trigger a signal when they sense the tube has fluid
inside.

## Buzzer



A buzzer is integrated to the board, this allows the program to give out
audio clues to the user/operator when things happen. See software
documentation to see the list of audio clues.

## Communication Ports



There are two types of communication port accessible from the boards via
three ports:

There are two I2C ports, 4 ways, with one of the port has an extra set
of pulled up resistor for a new additional device

There is a 16way IDC SPI communication port. This is currently used for
the SD card module. The hardware is suitable for any SPI device. The
parallel pin socket allow another device to be piggy-back to the same
port.

## Microcontroller pinout



A pinout diagram of the microcontroller to all the other components on
the board. Some basic components such as transistor and resistor are
added depending on the signal the pin is interfacing with. This would
change depending on the programs being uploaded to the microcontroller.



All the extra pins are tentatively grouped to an IDC header for future
development and expansion.

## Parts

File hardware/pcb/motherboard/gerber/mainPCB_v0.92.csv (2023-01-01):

Comment | Designator | Footprint | LCSC
WJ25C-B-7.62-6P | REMOVE_VALVE1,ADD_VALVE1 | TerminalBlock:WJ25C-B-7.62-6P | C14864
321016SG0ABK00A01 | SD_LOGGER1 | Connector_IDC:IDC-Header_2x08_P2.54mm_Latch_Vertical | C429960
4N35SM | U1 | Package_DIP:DIP-6_W8.89mm_SMDSocket_LongPads | C433446
MOC3020S-TA1 | U3 | Package_DIP:DIP-6_W8.89mm_SMDSocket_LongPads | C115464
AZ1117-5.0 | U4 | Package_TO_SOT_SMD:SOT-223 | C92105
SN74HC165 | U5 | Package_SO:SOIC-16_3.9x9.9mm_P1.27mm | C61060
321010SG0ABK00A01 | UI_PCB1 | Connector_IDC:IDC-Header_2x05_P2.54mm_Vertical | C429962
WJ25C-B-7.62-2P | VALVE12V1,220VAC1 | TerminalBlock:WJ25C-B-7.62-2P | C8422
KBP206G | BR1 | footprints:KBP206G | C244328
Conn_01x08 | BT_D1,BT_D2 | Connector_PinHeader_2.54mm:PinHeader_1x08_P2.54mm_Vertical | C27438
Conn_01x06 | BT_PWR1,BT_A1 | Connector_PinHeader_2.54mm:PinHeader_1x06_P2.54mm_Vertical | C40877
SFN-1207PA7.6 | BZ1 | Buzzer_Beeper:Buzzer_12.6x7.0P7.5 | C360605
100nF-ceramics | C1 | Capacitor_SMD:C_0402_1005Metric | C1525
47nF-ceramic | C2 | Capacitor_SMD:C_1206_3216Metric | C106083
10nF-ceramic | C3 | Capacitor_SMD:C_1206_3216Metric | C107201
1.0uF | C4,C5 | Capacitor_SMD:C_0402_1005Metric | C52923
0.1uF | C6 | Capacitor_SMD:C_0402_1005Metric | C1525
MM1Z12 | D17 | Diode_SMD:D_SOD-123 | C86234
MM1Z7V5 | D18 | Diode_SMD:D_SOD-123 | C87634
RLED | D19,D20 | LED_SMD:LED_0603_1608Metric_Pad1.05x0.95mm_HandSolder | C2286
WLED | D21,D22 | LED_SMD:LED_0603_1608Metric_Pad1.05x0.95mm_HandSolder | C2290
1N5819HW-7-F | D1,D2,D3,D4,D5,D6,D7,D8,D9,D10,D11,D12,D13,D14,D15,D16 | Diode_SMD:D_SOD-123 | C2891704
321024RG0ABK00A06 | EXTRA1 | Connector_IDC:IDC-Header_2x12_P2.54mm_Horizontal | C601956
BSMD1206-050-13.2V | F3 | Fuse:Fuse_1206_3216Metric | C883123
BSMD1206-050-16V | F4 | Fuse:Fuse_1206_3216Metric | C883124
BSMD1206-100-16V | F6,F7 | Fuse:Fuse_1206_3216Metric | C883131
BSMD1812-260-13.2V | F5,F8 | Fuse:Fuse_1812_4532Metric | C883159
BSMD1206-075-16V | F9 | Fuse:Fuse_1206_3216Metric | C883128
WJ128V-5.0-2P | HE1,ADD_PUMP1,SOAK_PUMP1,REMOVE_PUMP1,7V-PSU-IN1,PSU_12VOUT1,PSU_12V1 | TerminalBlock_Phoenix:TerminalBlock_Phoenix_MKDS-1,5-2_1x02_P5.00mm_Horizontal | C8269
JST_XH-A-1x03 | HEAT_SENSE1 | Connector_JST:JST_XH_B3B-XH-A_1x03_P2.50mm_Vertical | C144394
Conn_01x04 | I2C_TANK1,I2C_CP8000 | Connector_PinSocket_2.54mm:PinSocket_1x04_P2.54mm_Vertical | C2718488
Conn_02x20_Odd_Even | J1 | Connector_PinSocket_2.54mm:PinSocket_2x20_P2.54mm_Vertical | C50982
Conn_02x03_Odd_Even | ICSP1,J2,J3 | Connector_PinSocket_2.54mm:PinSocket_2x03_P2.54mm_Vertical | C2897404
Conn_02x16_Odd_Even | J4 | Connector_PinSocket_2.54mm:PinSocket_2x16_P2.54mm_Vertical | C24778
Conn_02x06_Odd_Even | JOYSTICK2R1 | Connector_PinHeader_2.54mm:PinHeader_2x06_P2.54mm_Vertical | C36191
JST_XH-A-1x10 | LCD_SHORT_OUT1 | Connector_JST:JST_XH_B10B-XH-A_1x10_P2.50mm_Vertical | C144400
JST_XH-A-1x04 | MOTOR1,MCU_heating_in1,MCU_HEAT_OUT1,XKC-Y25V1,XKC-Y26A-V1 | Connector_JST:JST_XH_B4B-XH-AM_1x04_P2.50mm_Vertical | C144395
TLC7528 | PANEL_DECODE1 | footprints:TLC7528CDW | C11359
Conn_01x02 | MEGA22,MEGA25,PSU_5V1,PSU_5V2 | Connector_PinSocket_2.54mm:PinSocket_1x02_P2.54mm_Vertical | C49661
IRF510PBF | Q1,Q15,Q33 | Package_TO_SOT_THT:TO-220-3_Vertical | C727603
BT136S-600E | Q2 | Package_TO_SOT_SMD:TO-252-2 | C581425
BC847 | Q3,Q4,Q5,Q6,Q7,Q8,Q9,Q10,Q11,Q12,Q13,Q14,Q16,Q30,Q32,Q35,Q37 | Package_TO_SOT_SMD:SOT-23 | C391423
IRF540NPBF | Q17,Q18,Q19,Q20,Q21,Q22,Q23,Q24,Q25,Q26,Q27,Q28,Q29,Q31,Q34,Q36,Q38 | Package_TO_SOT_THT:TO-220-3_Vertical | C2566
AON6411 | Q45,Q46 | ALOM_DFN5X6_8L_EP1_P | C81007
68-0.25W | R10 | Resistor_SMD:R_1206_3216Metric | C17976
10k-0.25W | R1,R7,R8,R11,R12,R13,R15,R16,R29,R30,R32,R35,R36,R38,R39,R40,R42,R43,R44,R45,R47,R49,R50,R51,R52,R54,R56,R57,R58,R59,R60,R61,R62,R63,R64,R65,R66,R67,R86,R87,R88 | Resistor_SMD:R_1206_3216Metric | C17902
4.7k-0.25W | R14,R53,R55,R80,R81 | Resistor_SMD:R_1206_3216Metric | C17936
1k-0.25W | R3,R17,R18,R19,R20,R21,R22,R23,R24,R25,R26,R27,R28,R34 | Resistor_SMD:R_1206_3216Metric | C4410
220-0.25W | R31 | Resistor_SMD:R_1206_3216Metric | C17957
47k-0.25W | R2,R4 | Resistor_SMD:R_1206_3216Metric | C25833
200-0.25W | R33,R37,R41,R46,R48 | Resistor_SMD:R_1206_3216Metric | C18002
150-0.25W | R5,R68,R69,R70,R71,R72,R73,R74,R75,R76,R77,R78,R79 | Resistor_SMD:R_1206_3216Metric | C17917
360-0.25W | R6 | Resistor_SMD:R_1206_3216Metric | C17932
470-0.25W | R9 | Resistor_SMD:R_1206_3216Metric | C4502
CD4051BM96 | REMOVE_DEMUX1,ADD_DEMUX1 | Package_SO:SOIC-16_3.9x9.9mm_P1.27mm | C21379

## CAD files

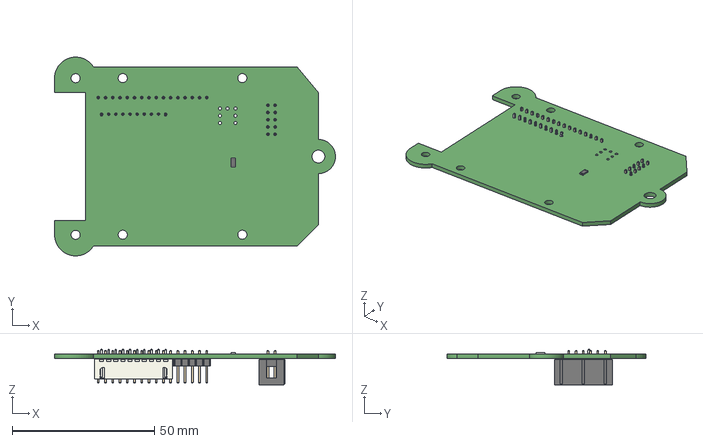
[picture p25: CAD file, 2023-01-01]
hardware/pcb/d_pad/circuit/mainPCB_v0.9-br2.step
98.7 x 69.8 x 12.5 mm

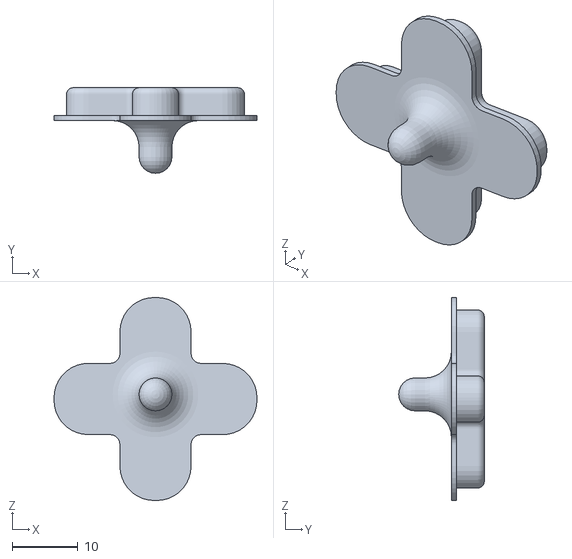
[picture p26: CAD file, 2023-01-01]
hardware/stls/joystick - Gary Wong.stl
30.8 x 13.0 x 30.8

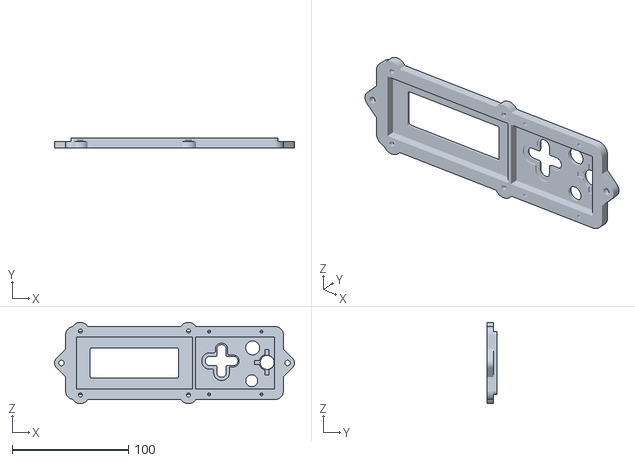
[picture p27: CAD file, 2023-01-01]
hardware/stls/Screen Panel D-Pad Version v33 - Gary Wong.stl
206.5 x 9.00 x 70.0

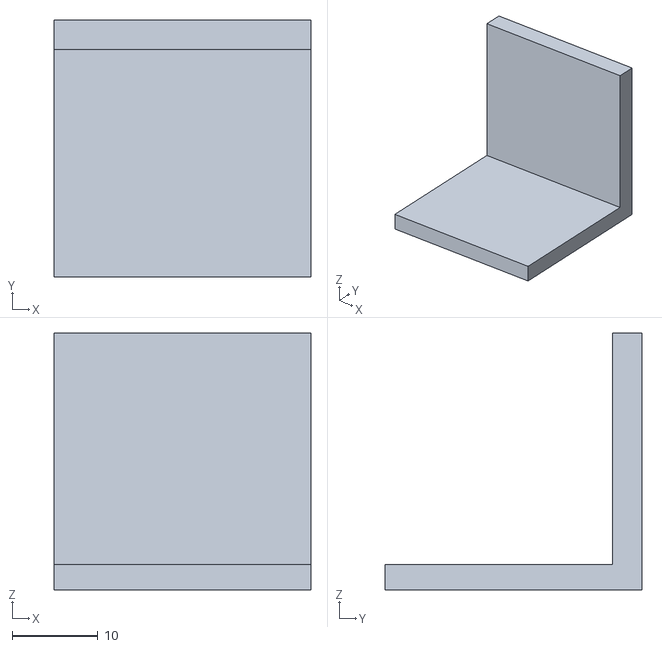
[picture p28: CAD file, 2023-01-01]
hardware/stls/sd card bracket v2 - Gary Wong.stl
30.0 x 30.0 x 30.0

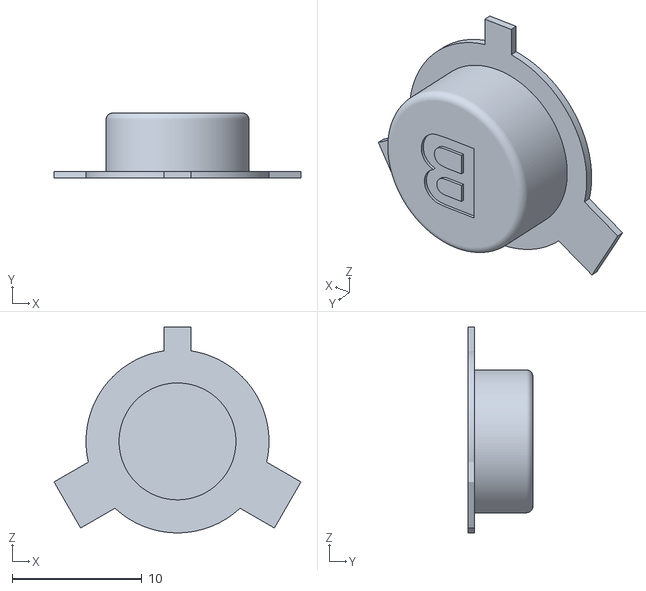
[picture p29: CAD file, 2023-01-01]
hardware/stls/D-Pad B Button - Gary Wong.stl
19.0 x 5.00 x 15.8

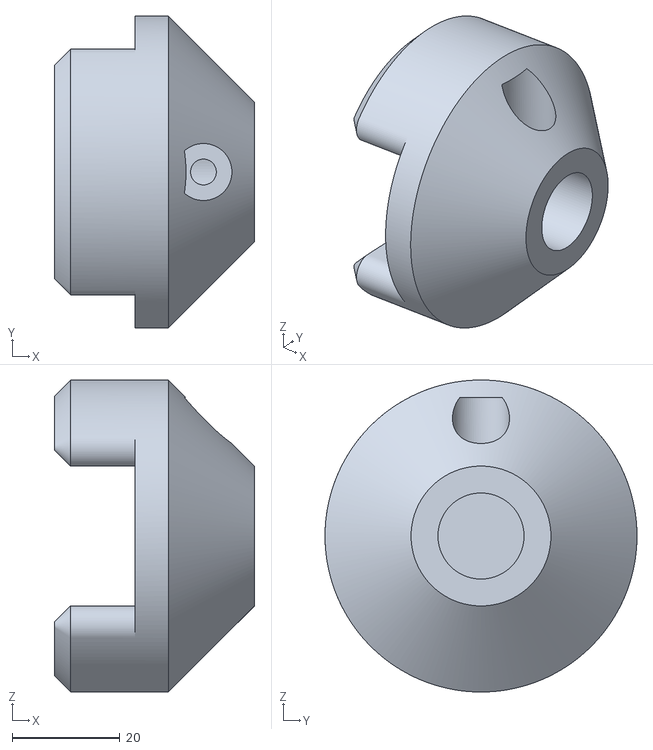
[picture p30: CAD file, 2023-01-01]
hardware/stls/ClutchHeadModified 220817.stl
37.2 x 58.0 x 58.0

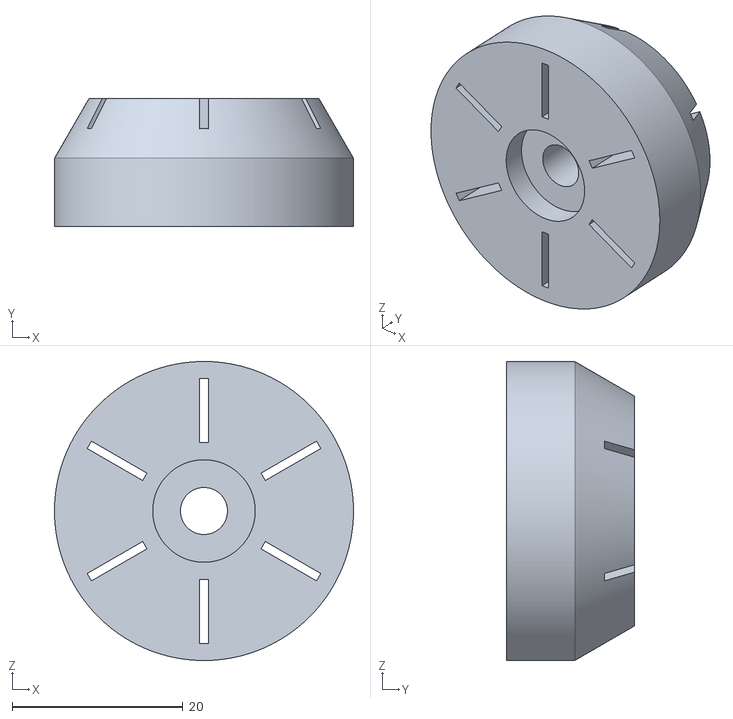
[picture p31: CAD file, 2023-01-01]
hardware/stls/Feet - Gary Wong (1).stl
35.0 x 15.0 x 35.0

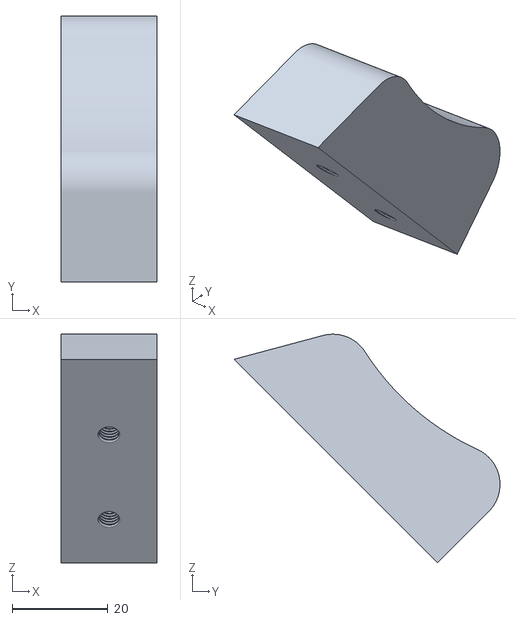
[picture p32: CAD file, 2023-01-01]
hardware/stls/Sleeper - Gary Wong.stl
20.0 x 55.5 x 47.7

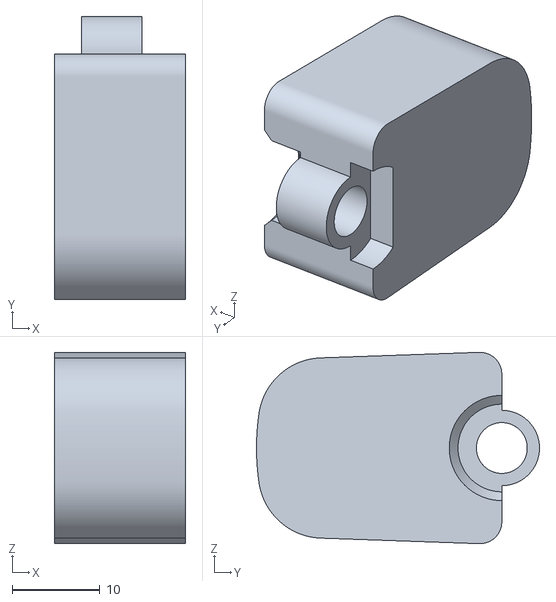
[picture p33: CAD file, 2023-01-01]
hardware/stls/knnob of deep cytcle.stl
15.0 x 32.3 x 21.8

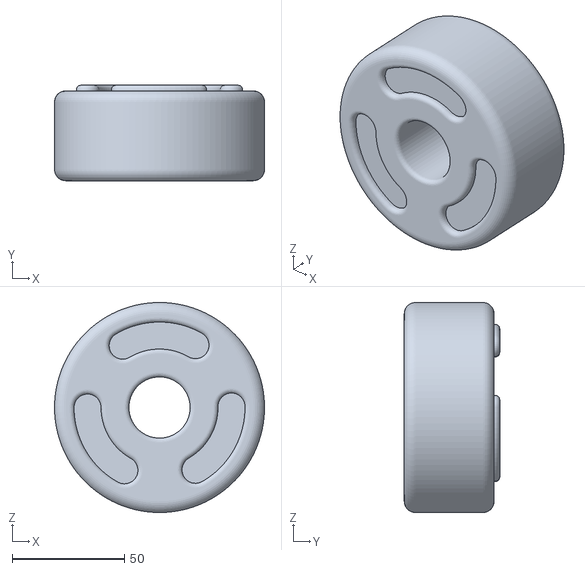
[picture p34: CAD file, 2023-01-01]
hardware/stls/Soaking Tank Spacer v1 - Gary Wong.stl
93.4 x 42.5 x 93.4

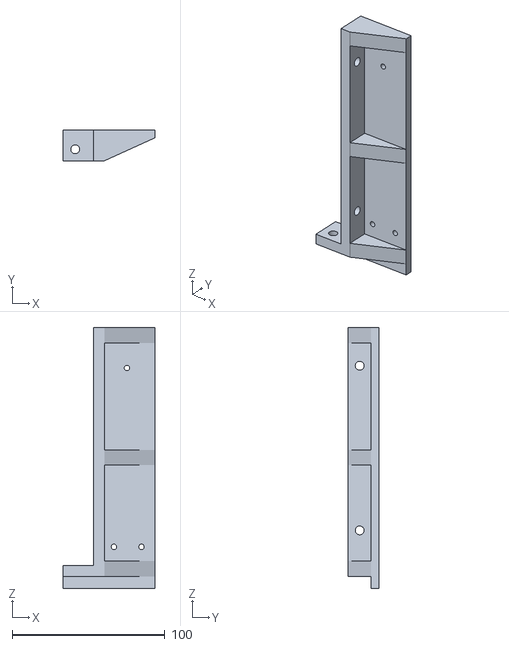
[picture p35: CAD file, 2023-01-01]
hardware/stls/PSU rack - Gary Wong.stl
60.0 x 20.0 x 170.8

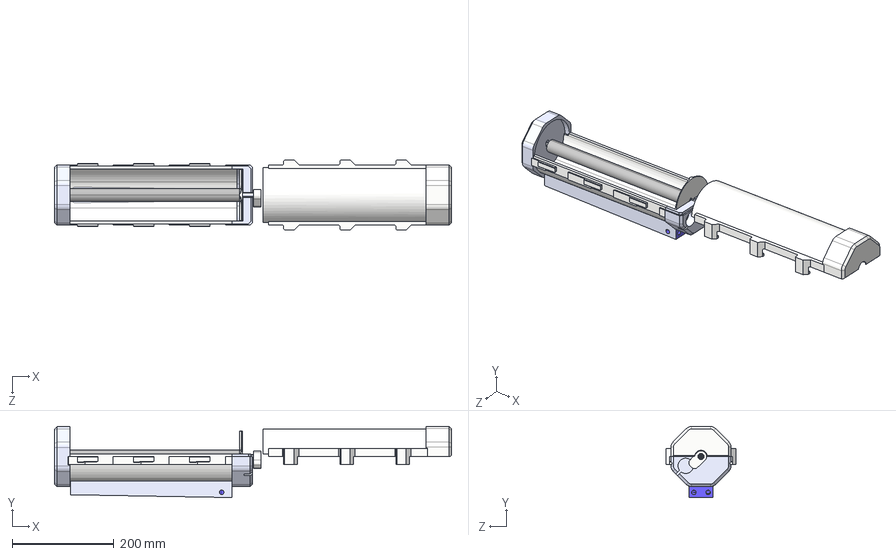
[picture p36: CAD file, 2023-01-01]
hardware/stls/DrumRoll 22019.STEP
778.6 x 139.5 x 137.9 mm
TankBaseMSF2
Tank Base Front Cap
DrumRod 221020
Light Guard
Light Shaft Shaft Connector
Rod Head
TankLid
TankLidTop
BackCap

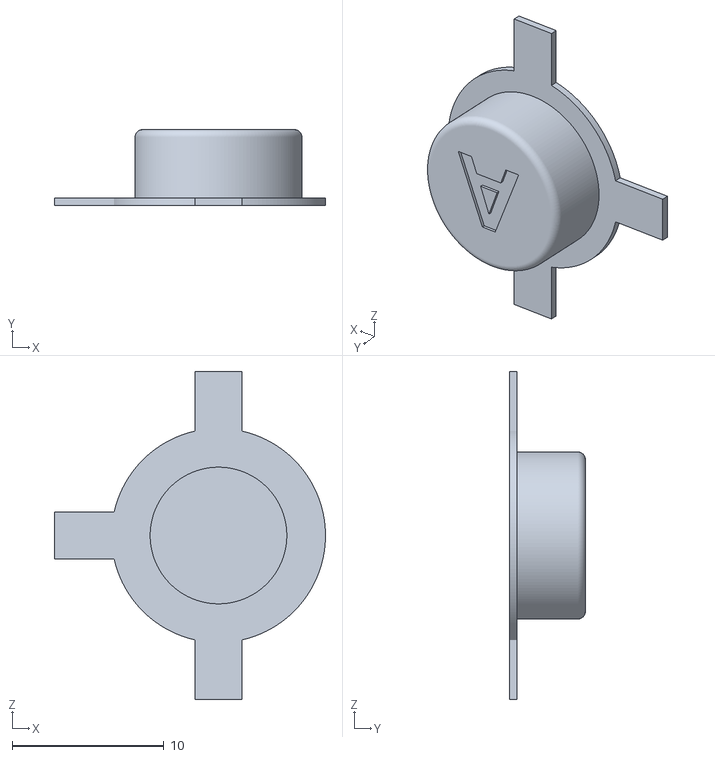
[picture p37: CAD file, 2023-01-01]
hardware/stls/D-Pad A Button - Gary Wong.stl
17.8 x 5.00 x 21.6

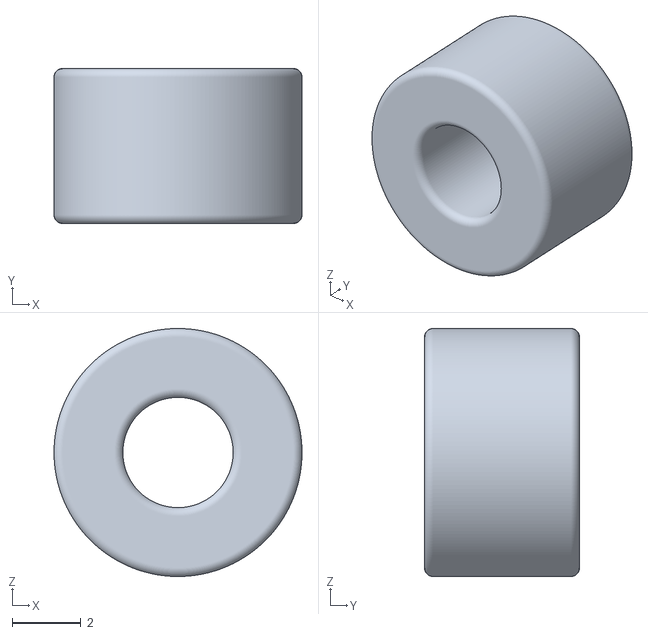
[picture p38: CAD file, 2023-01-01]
hardware/stls/PCB standoff m3x3 - Gary Wong.stl
7.20 x 4.50 x 7.20

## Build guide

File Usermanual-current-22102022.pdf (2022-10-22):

# CP800 User Manual

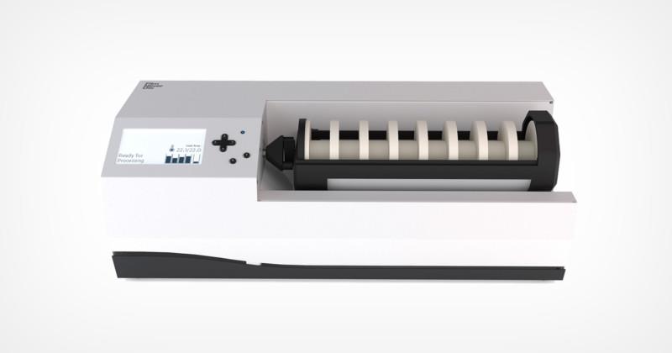
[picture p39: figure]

# FND

Contact:

Last Updated: 22/10/2022

This work is licensed under the Creative Commons Attribution-ShareAlike 4.0 International License. To view a copy of this license, visit http://creativecommons.org/licenses/by-sa/4.0/ or send a letter to Creative Commons, PO Box 1866, Mountain View, CA 94042, USA.

## Installation

Pre-setup:

Please check your package for parts/components against the following checklist, please refer to the “Part list” section for the components part code and names with a picture.

Checklist:

Received parts in package

Part code | Name | Condition | Qty | Check?
CP800-FULL | CP-800 Semi-automatic drum processor | | 1
CPB00-TANK | Full dev tank | | 1

The below list is the parts that are not provided in the package and the user is required to source themselves from local hardware shop

Sourcing list;

Part code | Name | Qty | Check?
| Local IEC Power cable | 1
| Sous Vide machine | 1
| 10mm tubes – 10 meters | 1
| 3mm Philips head screw driver | 1
| 1mm Flat head screw driver | 1

Adjusting Screen contrast
Once the machines all check and setup, and all parts and assembly are checked please use the 1mm Flat head screw driver to adjust the screen contrast if the contrast is out.

** insert photo**

## Setting up

Connecting the plumbing loop:
The processing tank has to be connected before any plumbing can take place. The connectors between the valves and the processing tank only open when connected. Trying to pump without connecting the tank will result in pressure building up in the connector end, and the plumbing tube will likely to burst out.

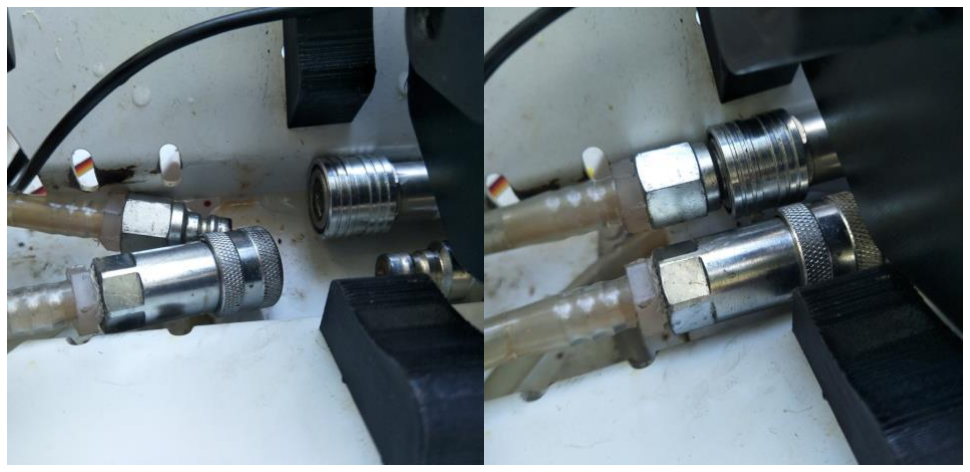
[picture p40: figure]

The left picture shows the processing tank not connected; the right shows the tank is connected.

** update photo with nylon quick coupler**

Tank leveling:
The user is required to adjust the level of the fluid inside the processing tank. The fluid level inside the tank should reach the middle of the rotating shaft along its entire length. Leveling the required to ensure all film along the rotating shaft is developed uniformly.

It is known that the current design of the machine assembly doesn't guarantee rigidity to ensure the tank is installed horizontally, since the tank is simply resting on sleepers and the metal casing underneath has an incline to drain any leaks.

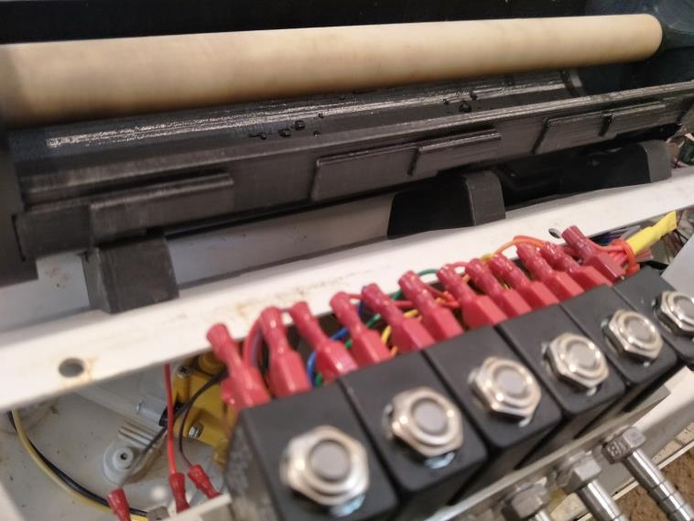
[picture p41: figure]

The following procedure is recommended to level the fluid in the tank:

1. Keep the tank open and rest it on the stands
2. Fill the tank with water manually, the unpowered (turn off) machine should keep the water from draining
3. Place a spirit level meter on the casing of the processing tank
4. Adjust the spirit level to the center as much as possible by padding the height of legs on the left side of the machine as you are facing it (we been using plastic canister caps which works fine).
5. Double check the water level with dummy rolls to see that the water level covers the bottom half of all rolls along the rotating shaft, repeat from step 2 to 4 until all rolls are submerged properly at rest.
6. Keep the water in the tank, if you wish calibrate the full tank sensor, see section “Calibration of full tank sensor”

It is also important to place the machine on a flat surface, since the rotating shaft is only functional within a small angle from the shaft axis of the DC motor.

Calibration of full tank sensor:
Full level sensor is sensing the capacitive of the material against its sensing surface. Capacitive sensing is dependent on the temperature, moisture content, the density of the material and the humidity of the air.

It is recommended to calibrate the sensor at the beginning of each day after the chemicals have been heated up to the desired temperature for the processing. If the ambient temperature has changed significantly during the day or a process operating with chemical at a different than previous processing, it is highly recommended to re-calibrate the full level sensor.

Consider calibrating the sensor in the following situation:

1. Before the first processing on a new day
2. If the operating ambient temperature change dramatically more than 5 o C (degrees Celsius)
3. If you are swapping over to use different processing chem (from BW 20 o C to C41 38 o C, or vice versa).
NOTE: when tuning the sensor, clockwise turning decreases the sensitivity of the sensor, and counter clockwise increases it.

The following procedure is recommended to calibrate the sensor:

1. Fill and level the fluid level of the tank, see section “Tank leveling”
2. Remove the cap of the sensor and have the nod exposed, you can remove by pitching the top bit of the sensor or use a flat head screw driver to rub it repeatably until the lid come off

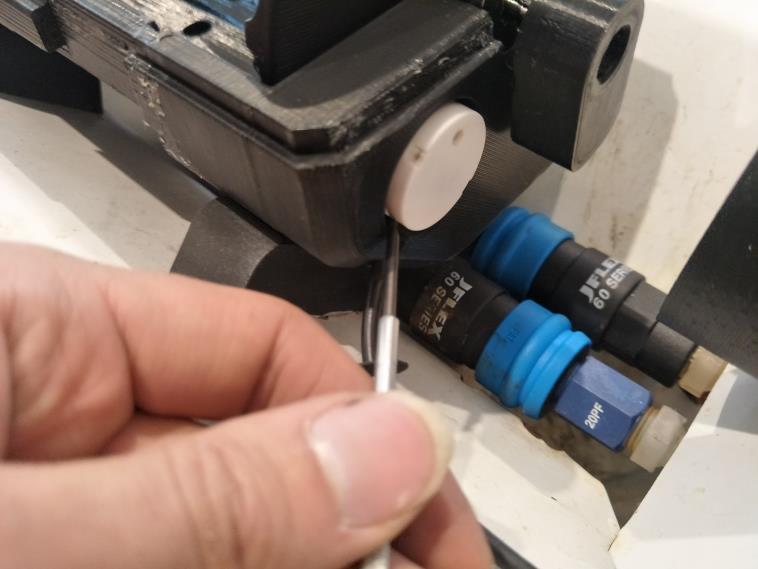
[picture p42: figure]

3. Connect the sensor and power on the machine.
4. Turn the nod using a flat head screw driver (circled red in the picture below), so the LED is just turned on at the desired water levels.

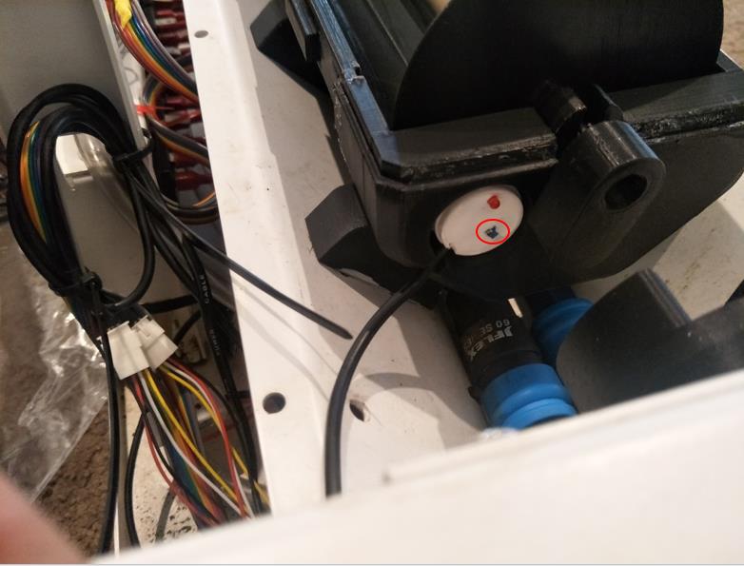
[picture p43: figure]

5. Remove the water content so the tank is empty, and the sensor should be off
6. Place the tank at the horizontal position on the sleeper and keep the machine powered
7. Refill the tank until you see the water level raised high enough to trigger the sensor’s light
8. If the sensor turned on at the desired level, the calibration is now completed, if not, repeat step 5 to 7 until the sensor's light turned on at the desired level.
Calibration of flow out sensors:
There are two outlets flow out sensors. They are to detect water flowing through the tube when the process is emptying the tank. The signal of both sensors is joint electrically to one port on the motherboard, so both sensors have to switch off together to indicate the entire flow out tube is empty thus the tank is empty. This arrangement is made to reduce the chance that a false positive for empty tank when there are air bubbles in the tube. The reason for that is the situation toward the end of the emptying the tank, the water level in the tank will be low enough that the pump will suck air in before the fluid is drained down by gravity on the other side of the tank.

These sensors sense the capacitance within the clip. Thus, consider calibrating the sensor in the same situation as the full tank sensor, which are:

1. When you are about to operate CP800 in a different temperature
2. Before the first processing on a new day
3. In the morning, afternoon and night without air-conditioning and operating in a climate where the temperature changes vastly during the day

The following procedure is recommended to calibrate each sensor:

1. Ensure all plugs are secured, the socket on the PCB for flow out sensor is connected to the splitter wires with two inline sockets and one inline plug

2. The splitter wires should act as AND gate for the pull-down signal of the sensor.
3. Check the signal is working properly by holding the sensor bare handed on the metal clip, the LED on the sensor should turned on
4. On the LCD Navigate to the output check menu: Main menu > (down button X 6) > setting > (down button once) > Output check
5. Pump in fluid to the tank from any input , using any addChem valve.
6. Pump out some fluid (using removeChem valve) and stop while the tube has water content in it.
7. Turn the nod on the sensor with a small flat head screw driver to adjust the sensitivity, make sure section with actual water content should trigger the sensor, the nod is circled in red in the picture below

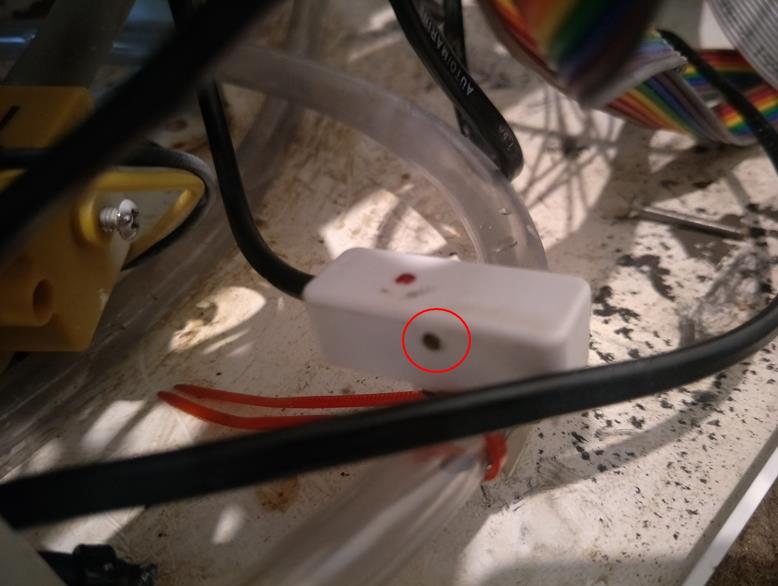
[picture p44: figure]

8. Pump the rest to check if the sensor light turned off too quickly before the tank is low in level
9. Test trial a processing cycle with water to see if the tuning allows a good drainage of the water content inside the tank.
10. Repeat step 5 to 9 if tank not drained, given the tank is physically leveled, else FINISH

Rotating clutch and rod:
Just need to make sure the clutch is not loose and it's connected to the motor properly by clamping on to the D-shaft with a bolt/grubscrew, the 3D printing hole of that could be a bit big, so might need to glue or put some paper to increase the friction.

## Main Menu (on LCD screen):

Navigate the menu using the instructions below:

- Up button: to move cursor upward
- Down button: to move the cursor downward
- B button: return to previous page
- A button: confirm or to go into the next page based on the option where the cursor is

There are 6 rows to select:

1. Info Screen: display information of processing or not processing
2. Start Processing: display option for starting a process
3. Stop/Clean Process: to stop a current process or conduct a cleaning process (cleaning process NOT implemented yet)
4. Last Processing: to recall and rerun the previous processing (NOT implemented)
5. Edit Processing: to select and edit processing saved in the ROM
6. Setting: to select and inspect the input and output of the machine

## Loading Processing:

There are three ways to start film processing:

1. Load from sketch (there could be typo), max up to 6 programs
2. Load from SD, due to the limitation of dynamics memory, max up to 12 programs
3. Load from ROM, max up to 6 programs

After selecting the method of loading, there should be a list of programs on display:

Load from sketch
There is a default of 6 programs loaded to the script of the machine from FND. This is the easiest way to start processing, since these programs are stored together with the firmware and can be read many times. Programs from sketch can be reused multiple times without rebooting machine. However, these programs cannot be edited, so the configuration of the machine has to follow the standard FilmNeverDie setup for those processes. Eg, Kodak D76 1+1 dilution at 20oC for BW and C41 with Fujifilm / Champion C41- N1, N2 , N3 + Stabiliser at 38oC set up.

Load from SD
Users can upload their own program via the SD card module. However, Reboot is required to refresh the SD files to rerun any further program from the SD card.

NOTE that the SD card has to be FAT32 format.

Issues and Errors of SD loads:
Known Issue 1:
The machine froze after selecting “load from SD” in the menu after it has been loaded from SD card once before.

Cause:

The firmware doesn’t allow the SD card module to be reloaded, when there is already an existing module.

Solution:

Reboot the machine before starting a new process from SD card after a previous load

If a user is trying to “load from SD”, there are 5 types of error when the operation is unsuccessful.

Errors:
1. Card failed, or not present
2. Program file has an unmatched number of programs
3. Process step has unmatched size with program header
4. Program file missing
5. Can't open program file from SD card

Possible solution to solve each error:
Error 1:
1. Make sure the SD card is inserted properly, you should hear a ‘click’ when you push the SD card, and the SD card is not bouncing back.
2. Make sure the format of the SD is FAT32

Error 2:

1. Make sure the number of programs within the file matches the actual number of programs stored in the file
2. It is recommended to regenerate the Programs.txt again with the official version of the generator from FilmNeverDie.
3. Users could also contact FilmNeverDie with their custom programs to get a properly generated file

Error 3:

1. Make sure the number of steps within the program matches the actual number of steps stored in the program
2. It is recommended to regenerate the Programs.txt again with the official version of the generator from FilmNeverDie.

Commented [GW1]: add trouble shooting at the end.

3. Users could also contact FilmNeverDie with their custom programs to get a properly generated file

Error 4:

1. Make sure there is a file named “programs.txt” (none case sensitive) in the SD card

Error 5:

1. Make sure the file named “programs.txt” is not opened by another software
2. Make sure the file named “programs.txt” is not corrupted

Load from ROM
Selected load from ROM will allow users to choose the program they had edited and saved to the EEPROM.

NOTE that the ROM processing is only loaded upon startup of the firmware, and any changes to the
ROM programs could only be reflected in the Load from ROM menu after restarting the machine.

There is the possibility that extra characters in the process name are accidentally saved to the ROM from the editing menu. This is caused by the dynamical memory used in the editing menu, and extra char might be present when saving the data array with undefined characters. This WILL NOT cause any operation issue to the processing itself.

## Processing Sequence:

After selecting processing from the menu, you will have to confirm and start the processing

- Confirmation page:
- Up button: +1 for pushing (increase dev time for 20%)
- Down button: -1 for pushing (increase dev time for 20%)
- Left button: +1 for dummy rolls in processing
- Right button: -1 for dummy rolls in processing
- B button: return to previous menu
- A button: confirm and start

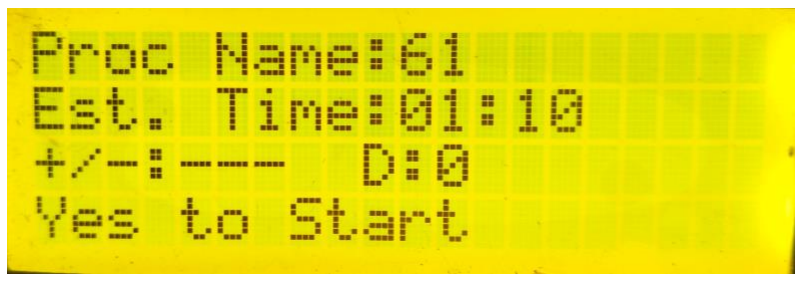
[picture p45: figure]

Info page shows:

Line 1: Process Name (Proc Name: ----)

Line 2: Estimated Time of the processing (Est. Time: --: --)

Line 3: Push or pull value (+/-: ---) followed by Dummy rolls numbers (D: -)

Line 4: message to inform user to press A (yes) to start

Dummy rolls have greater water displacement than regular rolls, and will reduce chemical usage. More on this later.

After starting the process there are option to further control and assist the machine to ensure the processing is up to standard.

- Info page during processing
- Up button: flow IN : this is an overwrite toggle to continue pumping in (same input valve as the current step)
- Down button: SKIP: skip from add to remove / skip remove to next step
- Left button: change to alternative info page (whilee in changing processing mode page, up / down will change from Sensor-based to Time-based processing based on Dummy rolls) More on this later.
- B button: return to previous menu
- A button: emergency flow OUT toggle ( it will use removeChem 6 / output valve 6 only)
- Others: does nothing

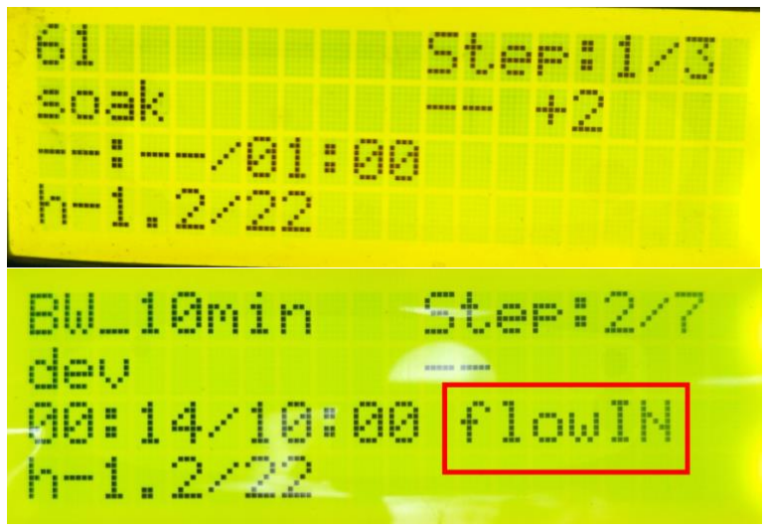
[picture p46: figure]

Info page shows:

Line 1: the processing selected, and the step progress

Line 2: The step name on the left, and the push/pull value and number of dummy rolls for the process on the right

Line 3: The time eclipsed out of the time in the step, and the flowIN/flowOUT msg

Line 4: heater temperature out of the target temperature (temperature function is not implemented)

The Red box highlights the location on the display where “flowIN”, “flowOUT” is visible when flow in and flow out toggle is active, respectively. “flowIN” has a high priority and will be on display when both toggles are active.

FlowIN and flowOUT toggle allows user to manually control the fluid level manually. Flow In adds the current chemical of the step into the tank, whereas the flow out will pump the fluid inside the tank via removeChem 6 or 6th out valve..

TRY NOT to use flowOUT if not necessary, it is designed as a backup flow out port in case the original port is blocked for some reason, also ensure removeChem 6 is always a back up , if possible.

- Alternative Info page during processing – when left is press to change processing mode.
- Up button: switch between sensor-based or fixed timer-based mode
- Left button: return to original info page
- Others: does nothing

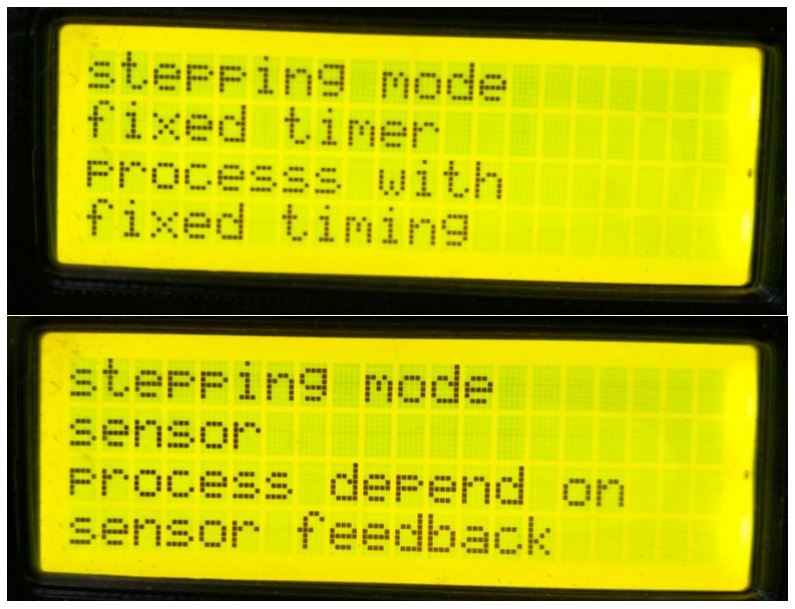
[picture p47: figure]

In sensor-based mode, the processing of adding and or removing the chemical depends on the signal from the sensors with basic hold-on and hold-off timing

In fixed timer-based mode, each stage of a processing step is based purely on timer, the adding and removing chemical stage is only dependent on the time. During this step is very important to ensure there is always liquid to pump in (chem tank is full) and also out valve is not obstructed to ensure the timer mode works perfectly. (From time to time you might also need to adjust the time for each dummy roll, please contact us so can assist you in doing that).

- Stop process
- Navigate to Stop processing from the main menu
- Select Stop Processing
- Press A to confirm Stopping

## Editing ROM Processing:

Entering the selection menu of edit processing would show the list of ROM programs that the user could edit, max of programs is 6.

NOTE that the editing is done in a buffer on the menu, and the changes reflected on the menu do not mean it is saved to the EEPROM.

After selecting a program to edit you can browse the parameters of the process using the general control. Saving is done automatically when you make a change in any parameter and return back to the editing selection menu.

Line 1 shows you are editing and the step number you are viewing/editing, process header also displayed as step 1.

Line 2 shows the name of the process you are viewing /editing

Line 3 shows the parameter you are viewing /editing

Line 4 shows the value of the parameter you are viewing /editing

General control:
- Left button: go to the previous parameters
- Right button: go to the next parameters
- B button: return to previous menu and save to ROM if changes had been made
- A button: toggle viewing/editing mode for the current parameters

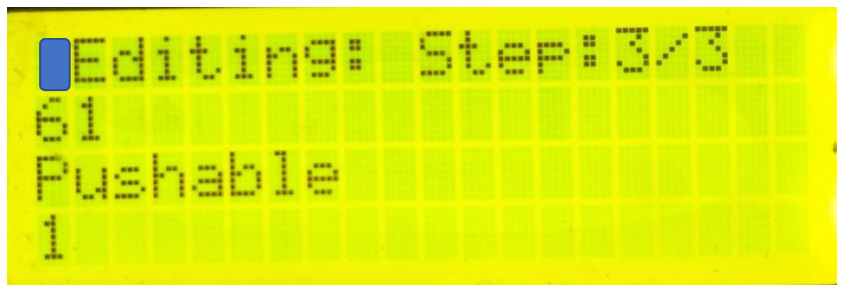
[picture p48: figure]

If editing mode is active, the top left corner of the screen will have a flashing black block, where the blue square is in the picture above
Editing mode control:
- Up button: increase the value of parameter by 1
- Down button: decrease the value of parameter by 1
- Left button: select the previous character (for process Name only), or decrease the value of parameter by 10 (for all other parameters)
- Right button: select the next character (for process Name only), or increase the value of parameter by 10 (for all other parameters)
- B button: exit editing mode without changes
- A button: exit editing mode with changes made on the editing menu

*NOTE: if you select 5 steps for your program, then you need make sure you edit all 5 steps before you can save it properly on the rom.

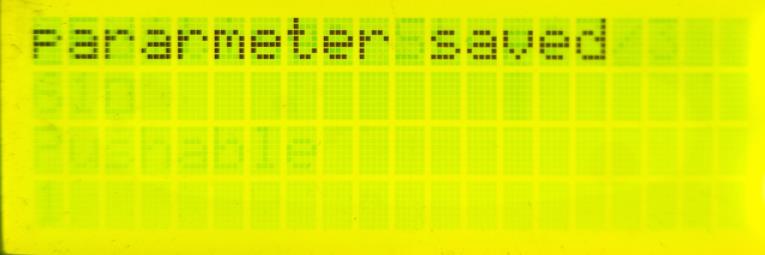
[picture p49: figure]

A saved message is displayed for 1 second when A is pressed to confirm the changes made and exist editing mode for the parameter

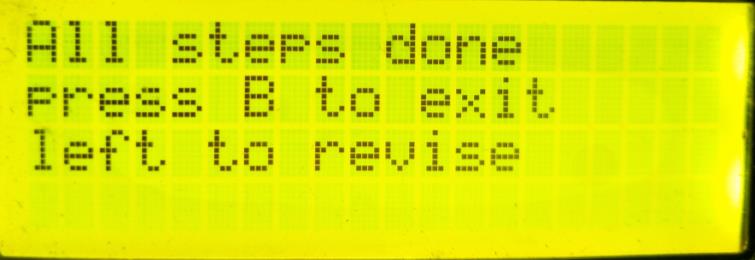
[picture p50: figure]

After you programmed the last step parameter, "Pushable” for the last step, a message will inform you that you had programed the last parameter, and this message stay on screen for 5 seconds. This message also occur when you press the right button, because there are no more parameters to edit. Saving ROM Processing:
Saving is done automatically when you make a change in the parameters and return back to the editing selection menu.

## Cleaning up

It is recommended to perform a cleanup at the end of the day, and after a long time without running it. The cleanup procedure is using clear water and relying on the pump to rinse inside the machine. All outlet water should be discarded as waste.

1. Go to “output check” menu: Main > Setting > Output Check

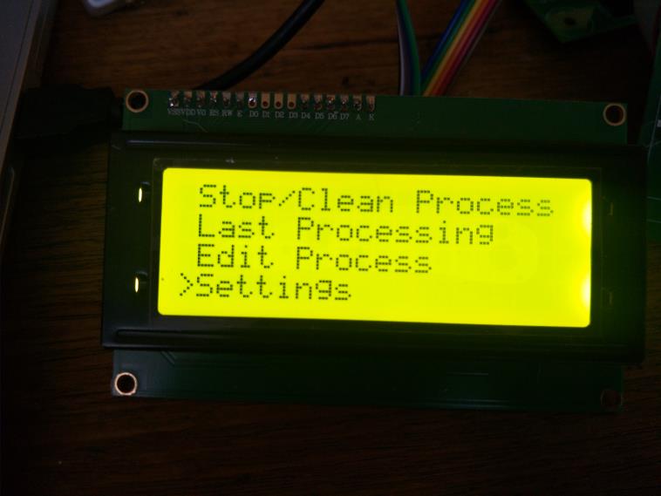
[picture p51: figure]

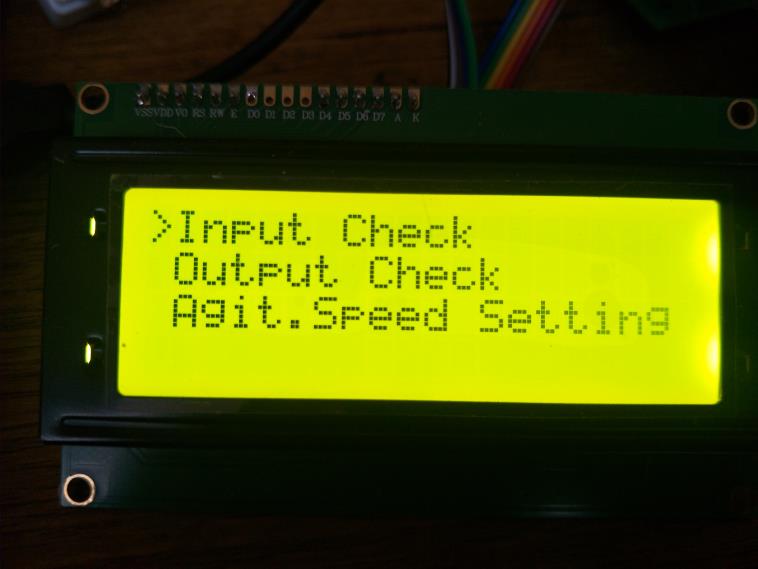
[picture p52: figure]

2. Press right to reach the first input tanks, addChem 1

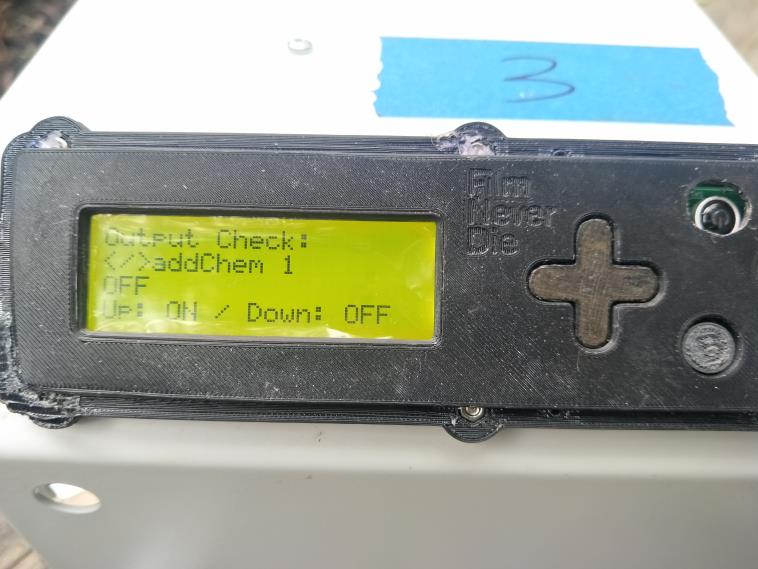
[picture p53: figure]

3. Prepare a container fille with water
4. Put one end of both tubes into the container filled with water if you intend to reuse the water, if not, put one output tube in another container which will be discarded as waste later
5. Prepare two pumping tubes and connect one on the first input valve (addChem 1) and the other on the first output valve (removeChem 1)
6. Using the menu to turn on the input by pressing the “Up” button and start filling the processing tanks

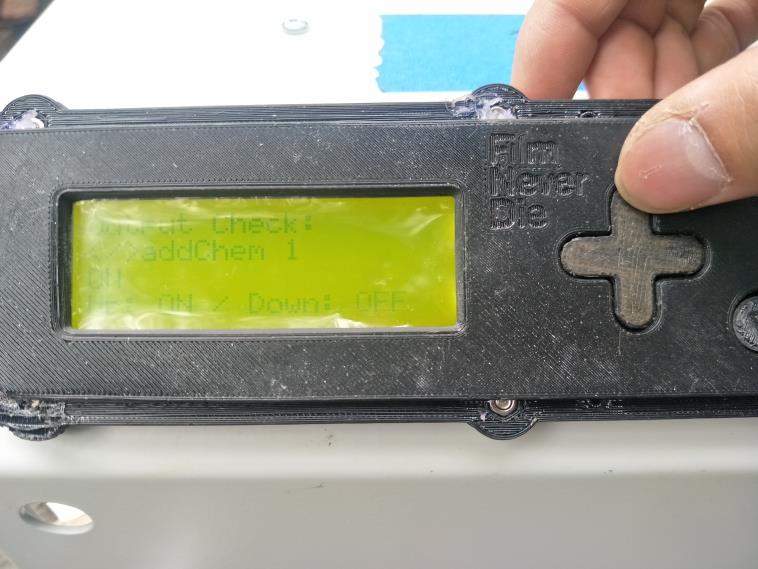
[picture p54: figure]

7. Once water is checked to be pumping in properly at the desired flow rate, skip to the first output valve, remove chem 1, on the menu
8. Turn on the output using the menu by pressing the “Up” button and let all the water drain
9. Detach both tubes on the valves and attach them to the next input/output valves
10. Repeat step 5 to step 9 for all the other valves until no more valves are untested, and refill the input container if needed
11. To clear the inside of the valve from water as much as possible, go back to addChem1 from the menu
12. Turn on the input valve in order and let it pump in air for around 5-10 seconds each valve, WD40 can be sprayed into the valve to repent the water out of it
13. Repeat step 12 for all the inputs and outputs
14. Finally, also please use WD40 to repent water in the Male and Female Nylon Quick Connector as there are metal ball bearing there which would rust and cause the connection to be not as smooth and need a 'pull up’ to connect them properly.

If any valve has a significant difference in flow rate, and the water has become dirty from flowing through it. It could indicate there is a blockage or corrosion inside the valve. It is recommended to take the valve apart and clean it thoroughly.

## Maintenance

Flows Sensors:
The full and empty flow sensor should be tested regularly. Full level sensor on the processing tank should be calibrated so the LED on the sensor is turned on at the desired level by the user. Similarly, the flow out sensors should be tested during a manual pump cycle so that the operation would guarantee proper pumping for each process. Due to the moisture and chemicals of film processing, the contact of the sensor may be affected over time. Please do keep the contact clean when the machine is not being used and apply WD40 regularly to keep moisture out of the contact.

Plumbing :
The machine should be pumping the hose and the valves dry before the machine is switched off overnight. Emptying the inlet can be done by manually actuator each valve into the processing tank, as for the full tanks. It shouldn't be too much fluid inside the pumping. It could also be empty by manually actuate the pump with each valve from the processing tank. WD40 should be applied to keep moisture from building up inside the solenoid valves.

Procedure:

1. Disconnected all the tubes from the both 6-ways solenoid stainless steel valve manifold blocks in for the input and output tanks
2. Navigate the menu -> settings -> output check referring to the “Main menu” Section of this document, if not sure how to navigate the menu.
3. Navitgate to addChem 1
4. Press the Up button to activate the pump with the valve

5. Wait a few seconds to ensure air is sucked into the processing tanks
6. Press down to stop the pumping
7. Press right to select the next valve
8. Repeat step 4 to 7 for all inputs and outputs (addChem 1 to removeChem 6)

6-ways solenoid stainless steel valve manifold block
We recommended at least open up and clean the solenoid valves ONCE a month. The springs inside the valve can easily trap aggregate in the chemical and other impurity, and this would accelerate the rusting or just simple accumulate the aggregate inside the solenoid, which will eventually hinder the solenoid ability to retract thus blocking the valve and the port. Recommended use WD40 to repent and clean up the accumulated gung and rust.

You will need an adjustable spanner/wrench, a cleaning brush, a thread seal/plumber tape.

Procedure:

1. Ensure the power to the machine is disconnected, and there is no electricity nearby, in case the fluid in the valve spilled out unintentionally during the dis-assembly process.
2. Disconnected all the tubing to the manifolds
3. Unscrew the top nut of each solenoid from one side to the other, there is only enough room for the spanner to turn from the side. The spanner may not fit into the middle ones.

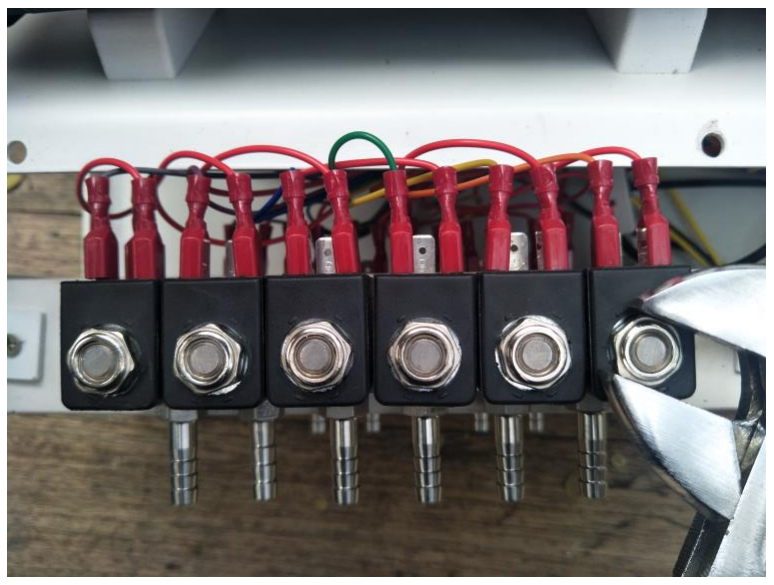
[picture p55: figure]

4. Before lift off the solenoid block, please label them 1 –6 so you will remember the sequence to reassemble them. Once you lift off the block you should see core inside now. You can leave the blocks, which are connected to the wires, inside the machine. If you want to keep them stored, you should disconnect the spade connectors.

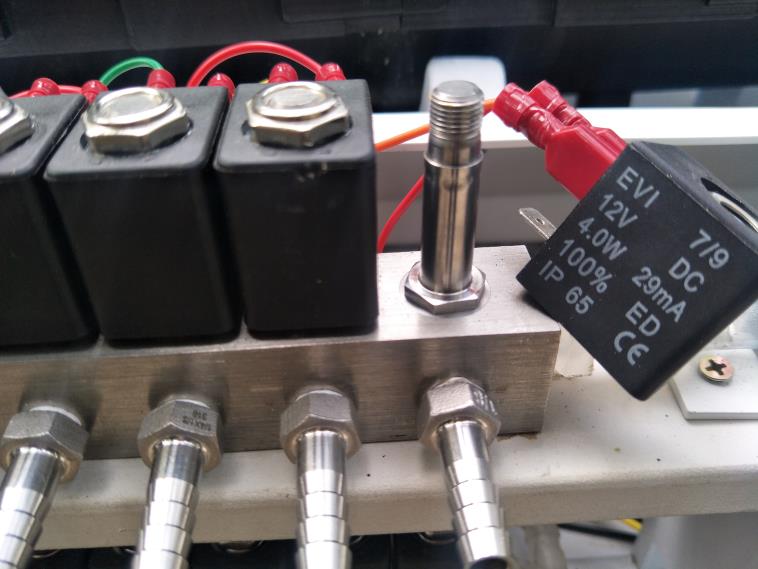
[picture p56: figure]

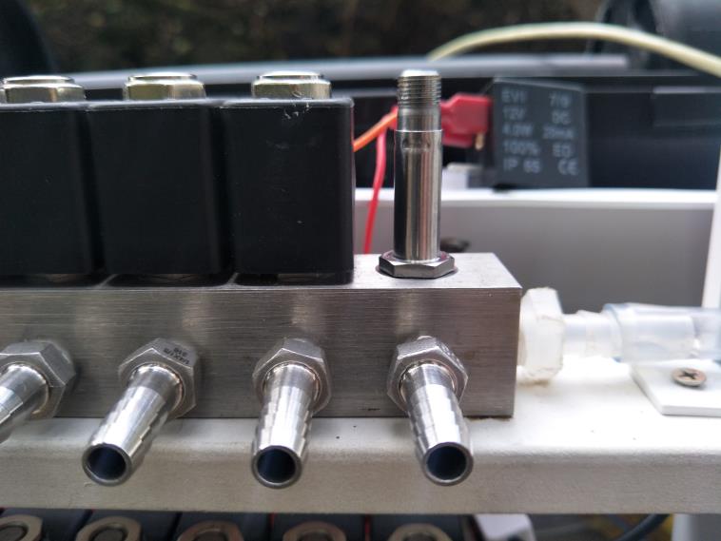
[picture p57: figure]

5. Unscrew core from one side to the other, again, there may not be enough room for turning for the middle ones.

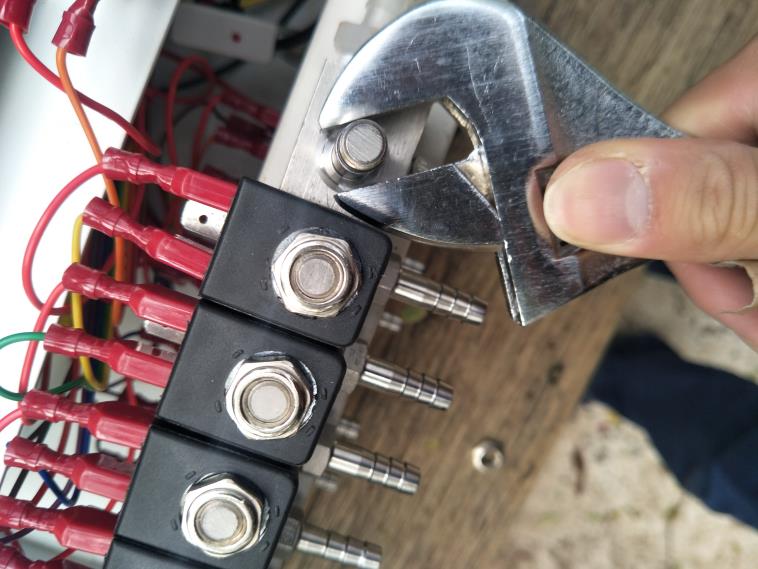
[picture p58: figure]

6. As you unscrew the core, the spring inside should push the core out, if not, lift the core out. It should reveal the piston/plunger and the spring around it.

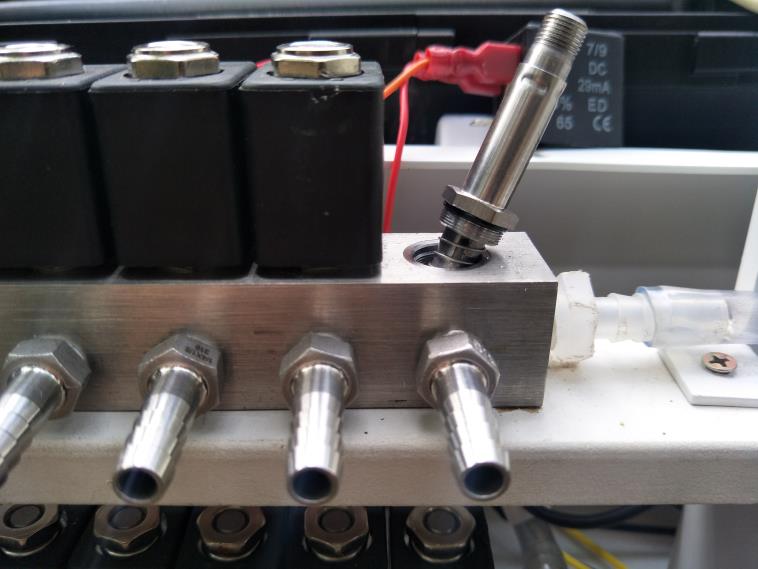
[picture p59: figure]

7. Remove the piston and the spring, keep them secured with the rest of the piece before, so you don’t lose them. The small stainless-steel solenoid has the spring round the piston at the bottom, see picture below

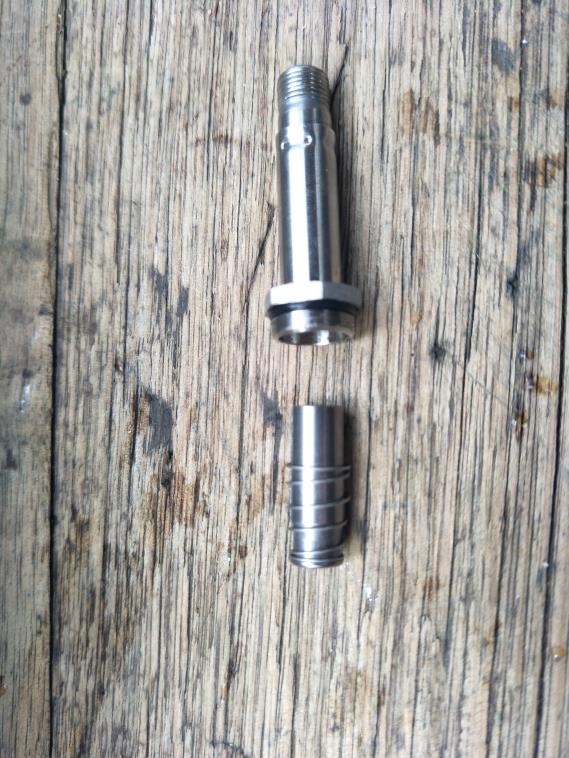
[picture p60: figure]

8. Next remove the all the threaded male barbs from each of the port and the common port on the side, you should have the manifold on its own.
9. Remove all the used/damaged thread seal tapes on the components
10. Give all barbs, spring, piston, core tube, and manifold a good cleaning with the brush and/or with water
a. apply rust removal if need, please follow the instruction on your rust removal agent/product
b. Replace components if they are worn out or badly damaged
11. Let the parts dry if needed, and blow off any dust remaining on the surface and apply a layer of WD40 for protection.
12. Assembly the valves in this order, and apply thread seal tape on the threaded parts: bards on manifolds -> piston + spring in core tube, and fit onto manifold all together-> solenoid block on core tube -> secured solenoid with top nuts.
13. If you want to reconnect the wires to the blocks from one side to the other, please do it in order that it is connected to the motherboard from top to bottom. The top terminal is the inputs, and the bottom one is the outputs. Port / Valve 1 is the top position of each terminal. Picture 1 below shows the wire colors from grey to orange on the board, matching the order from left to right on the solenoids (pay attention to the rainbow color wire)

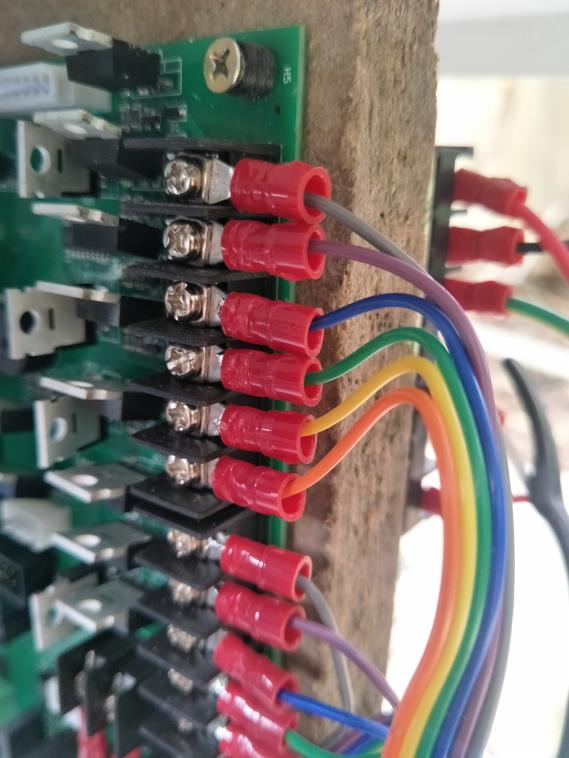
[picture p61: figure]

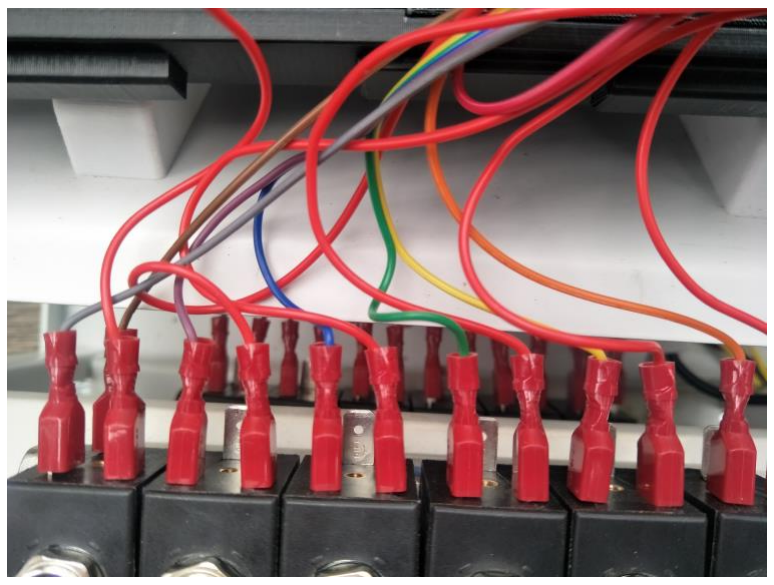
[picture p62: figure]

NOTE: if the wires are swapped, the port / valve number will be swapped in the programs, it could allow further customization in your programs and your setup but generally it causes more confusion between processes.

NOTE: inputs and outputs can be swapped if the pumped terminals on the other side of the motherboard are also swapped

NOTE: the most important thing is to keep the electrical terminal consistency between the inputs and output for the pump and the valves.

## Part Lists:

This section lets you check all the parts required to build the machine and it allows the user to learn the naming of each part, so that the readers would understand which parts are being referred to in the instructions of this document hereafter.

This section is now in a separate document.

Commented [GW2]: lets put the part list at the back

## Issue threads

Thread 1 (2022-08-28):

Will the tank parts open source?

anhtuannd, 2022-08-28:
Hello,
This is the great project and I'm happy to open first issue :)
I'm trying to build my own system but from the part list, the tank is yet to be available. Will it be open source?

FilmNeverDie, 2022-08-30:
Yes it will be ! We are putting all the 3D models on soon! just organizing them now.  so good to hear you are building one, where are you building from?

anhtuannd, 2022-09-01:
At the moment I just try to understand project structure. When the code is available, I will try to compile myself and may write unit test for it.

FilmNeverDie, 2022-10-29:
The tank is now available in the 3D files if you got any question please let us know

r-tae, 2022-12-20:
@anhtuannd I've just made a PR where I've added the source code to this repo (I'm not affiliated with FND, I just moved it from the SharePoint with their permission).

I have a pipe dream of setting up something like:
- Unit tests, probably using https://github.com/Arduino-CI/arduino_ci
- Doxygen (plus https://github.com/pieterdavid/mkdocs-doxygen-plugin) to generate documentation from source comments. This might be a bit of a boring job, but I think we just need to move the information from https://r-tae.github.io/Farbung/software/ into Javadoc-style comments

Just pinging you in case you were interested

anhtuannd, 2022-12-20:
@r-tae
I can help part of them. Doxygen I haven't used yet but it seems to be not far from Javadoc/Kdoc.

r-tae, 2022-12-20:
Great! I've never actually used Doxygen either, so I'm not sure if its a good idea yet but at least Javadoc comments would be beneficial either way

Closed 2022-10-29.

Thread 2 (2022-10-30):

Sources for parts?

gabecamp, 2022-10-30:
Planning on building one of these but struggling to find some parts( mostly the solenoid/manifold assembly) is it possible to include links to sources for parts ?

cychu18, 2023-01-01:
hi, the solenoid manifold in the current models are made by Ningbo Xinyi Sunshine Pneumat Science Tech. A lot of the parts are generic such as Arduino, capacitive sensors, DC motors, if you can find a local suppliers it would be better for you since the price with shipping varies a lot depending where you are. Let me know if you have any trouble in sourcing the parts.

mpiraux, 2023-04-23:
Hi, the X2V030-08-6F-DC12V model number that can be read on the solenoid pic gives no results today, so more information on this part would be helpful. Thank you

cychu18, 2023-04-24:
> Hi, the X2V030-08-6F-DC12V model number that can be read on the solenoid valve pic gives no results today, so more information on this part would be helpful. Thank you

they don't have standard parts for sale, you will have to specify your manifold requirement. CP800 uses 6 channels but you may want to have less or more of different materials depending on your chemicals.
https://xysunpc.en.alibaba.com/productgrouplist-801761158/valve_manifold.html?spm=a2700.shop_plgr.88.42

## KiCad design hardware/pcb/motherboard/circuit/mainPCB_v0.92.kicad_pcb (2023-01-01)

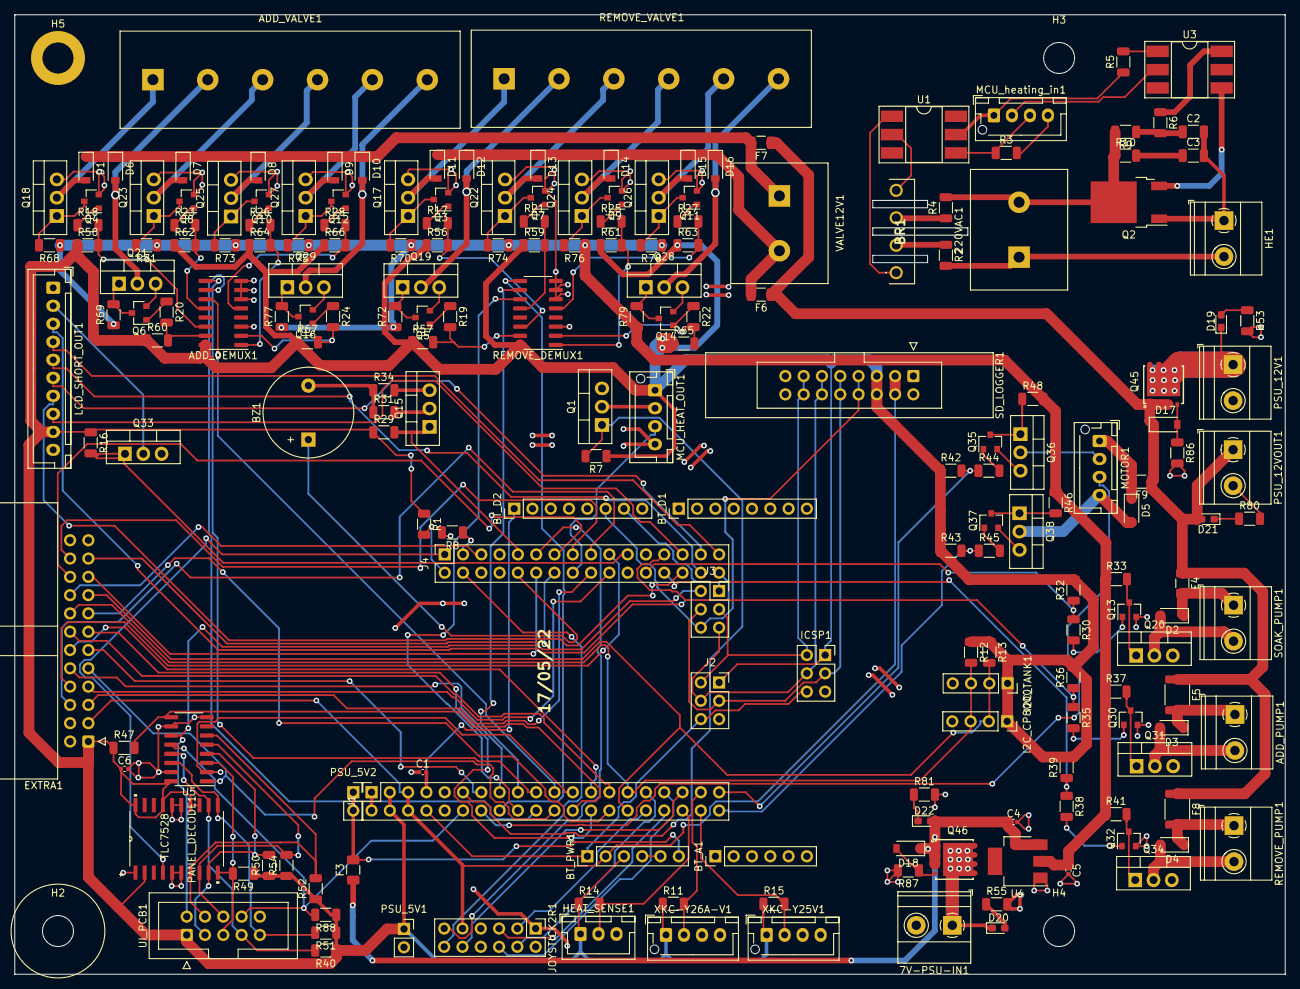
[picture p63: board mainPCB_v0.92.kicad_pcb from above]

Board: 2 copper layers, 176.4 x 133.2 mm, 207 parts (0 on the bottom side), 174 nets.

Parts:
7V-PSU-IN1: WJ128V-5.0-2P; TerminalBlock_Phoenix_MKDS-1,5-2_1x02_P5.00mm_Horizontal
220VAC1: WJ25C-B-7.62-2P
ADD_DEMUX1: CD4051BM96; SOIC-16_3.9x9.9mm_P1.27mm
ADD_PUMP1: WJ128V-5.0-2P; TerminalBlock_Phoenix_MKDS-1,5-2_1x02_P5.00mm_Horizontal
ADD_VALVE1: WJ25C-B-7.62-6P
BR1: KBP206G
BT_A1: Conn_01x06; PinHeader_1x06_P2.54mm_Vertical
BT_D1, BT_D2: Conn_01x08; PinHeader_1x08_P2.54mm_Vertical
BT_PWR1: Conn_01x06; PinHeader_1x06_P2.54mm_Vertical
BZ1: SFN-1207PA7.6; Buzzer_12.6x7.0P7.5
C1: 100nF-ceramics; C_0402_1005Metric
C2: 47nF-ceramic; C_1206_3216Metric
C3: 10nF-ceramic; C_1206_3216Metric
C4, C5: 1.0uF; C_0402_1005Metric
C6: 0.1uF; C_0402_1005Metric
D1, D2, D3, D4, D5, D6, D7, D8, D9, D10, D11, D12, D13, D14, D15, D16: 1N5819HW-7-F; D_SOD-123
D17: MM1Z12; D_SOD-123
D18: MM1Z7V5; D_SOD-123
D19, D20: RLED; LED_0603_1608Metric_Pad1.05x0.95mm_HandSolder
D21, D22: WLED; LED_0603_1608Metric_Pad1.05x0.95mm_HandSolder
EXTRA1: 321024RG0ABK00A06; IDC-Header_2x12_P2.54mm_Horizontal
F3: BSMD1206-050-13.2V; Fuse_1206_3216Metric
F4: BSMD1206-050-16V; Fuse_1206_3216Metric
F5, F8: BSMD1812-260-13.2V; Fuse_1812_4532Metric
F6, F7: BSMD1206-100-16V; Fuse_1206_3216Metric
F9: BSMD1206-075-16V; Fuse_1206_3216Metric
H2, H3, H4: MountingHole; MountingHole_4.3mm_M4
H5: MountingHole; MountingHole_4.3mm_M4_DIN965_Pad
HE1: WJ128V-5.0-2P; TerminalBlock_Phoenix_MKDS-1,5-2_1x02_P5.00mm_Horizontal
HEAT_SENSE1: JST_XH-A-1x03; JST_XH_B3B-XH-A_1x03_P2.50mm_Vertical
I2C_CP8000, I2C_TANK1: Conn_01x04; PinSocket_1x04_P2.54mm_Vertical
ICSP1: Conn_02x03_Odd_Even; PinSocket_2x03_P2.54mm_Vertical
J1: Conn_02x20_Odd_Even; PinSocket_2x20_P2.54mm_Vertical
J2, J3: Conn_02x03_Odd_Even; PinSocket_2x03_P2.54mm_Vertical
J4: Conn_02x16_Odd_Even; PinSocket_2x16_P2.54mm_Vertical
JOYSTICK2R1: Conn_02x06_Odd_Even; PinHeader_2x06_P2.54mm_Vertical
LCD_SHORT_OUT1: JST_XH-A-1x10; JST_XH_B10B-XH-A_1x10_P2.50mm_Vertical
MCU_HEAT_OUT1: JST_XH-A-1x04; JST_XH_B4B-XH-AM_1x04_P2.50mm_Vertical
MCU_heating_in1: JST_XH-A-1x04; JST_XH_B4B-XH-AM_1x04_P2.50mm_Vertical
MOTOR1: JST_XH-A-1x04; JST_XH_B4B-XH-AM_1x04_P2.50mm_Vertical
PANEL_DECODE1: TLC7528; TLC7528CDW
PSU_5V1, PSU_5V2: Conn_01x02; PinSocket_1x02_P2.54mm_Vertical
PSU_12V1, PSU_12VOUT1: WJ128V-5.0-2P; TerminalBlock_Phoenix_MKDS-1,5-2_1x02_P5.00mm_Horizontal
Q1, Q15, Q33: IRF510PBF; TO-220-3_Vertical
Q2: BT136S-600E; TO-252-2
Q3, Q4, Q5, Q6, Q7, Q8, Q9, Q10, Q11, Q12, Q13, Q14, Q16, Q30, Q32, Q35, Q37: BC847; SOT-23
Q17, Q18, Q19, Q20, Q21, Q22, Q23, Q24, Q25, Q26, Q27, Q28, Q29, Q31, Q34, Q36, Q38: IRF540NPBF; TO-220-3_Vertical
Q45, Q46: AON6411; ALOM_DFN5X6_8L_EP1_P
R1, R7, R8, R11, R12, R13, R15, R16, R29, R30, R32, R35, R36, R38, R39, R40, R42, R43, R44, R45, R47, R49, R50, R51, R52, R54, R56, R57, R58, R59, R60, R61, R62, R63, R64, R65, R66, R67, R86, R87, R88: 10k-0.25W; R_1206_3216Metric
R2, R4: 47k-0.25W; R_1206_3216Metric
R3, R17, R18, R19, R20, R21, R22, R23, R24, R25, R26, R27, R28, R34: 1k-0.25W; R_1206_3216Metric
R5, R68, R69, R70, R71, R72, R73, R74, R75, R76, R77, R78, R79: 150-0.25W; R_1206_3216Metric
R6: 360-0.25W; R_1206_3216Metric
R9: 470-0.25W; R_1206_3216Metric
R10: 68-0.25W; R_1206_3216Metric
R14, R53, R55, R80, R81: 4.7k-0.25W; R_1206_3216Metric
R31: 220-0.25W; R_1206_3216Metric
R33, R37, R41, R46, R48: 200-0.25W; R_1206_3216Metric
REMOVE_DEMUX1: CD4051BM96; SOIC-16_3.9x9.9mm_P1.27mm
REMOVE_PUMP1: WJ128V-5.0-2P; TerminalBlock_Phoenix_MKDS-1,5-2_1x02_P5.00mm_Horizontal
REMOVE_VALVE1: WJ25C-B-7.62-6P
SD_LOGGER1: 321016SG0ABK00A01; IDC-Header_2x08_P2.54mm_Latch_Vertical
SOAK_PUMP1: WJ128V-5.0-2P; TerminalBlock_Phoenix_MKDS-1,5-2_1x02_P5.00mm_Horizontal
U1: 4N35SM; DIP-6_W8.89mm_SMDSocket_LongPads
U3: MOC3020S-TA1; DIP-6_W8.89mm_SMDSocket_LongPads
U4: AZ1117-5.0; SOT-223
U5: SN74HC165; SOIC-16_3.9x9.9mm_P1.27mm
UI_PCB1: 321010SG0ABK00A01; IDC-Header_2x05_P2.54mm_Vertical
VALVE12V1: WJ25C-B-7.62-2P
XKC-Y25V1, XKC-Y26A-V1: JST_XH-A-1x04; JST_XH_B4B-XH-AM_1x04_P2.50mm_Vertical

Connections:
5V_EX: C5.1, R33.1, R37.1, R41.1, R46.1, R48.2, R68.1, R69.1, R70.1, R71.1, R72.1, R73.1, R74.1, R75.1, R76.1, R77.1, R78.1, R79.1, U4.2
220VAC+: 220VAC1.2, Q2.2, R4.2, R9.2, R10.1
220VAC-: 220VAC1.1, HE1.2, R2.2
+3V3: BT_PWR1.2, EXTRA1.3, J1.5, J1.6, JOYSTICK2R1.9, SD_LOGGER1.3, SD_LOGGER1.4
+5V: ADD_DEMUX1.16, BT_PWR1.3, C6.1, EXTRA1.1, HEAT_SENSE1.1, I2C_CP8000.1, I2C_TANK1.1, ICSP1.1, J1.3, J1.4, J2.1, LCD_SHORT_OUT1.9, MCU_HEAT_OUT1.1, PANEL_DECODE1.2, PANEL_DECODE1.13, PANEL_DECODE1.14, PANEL_DECODE1.17, PANEL_DECODE1.20, PSU_5V1.1, R1.1, R7.1, R11.1, R12.1, R13.1, R14.1, R15.1, R16.1, R29.1, R32.2, R36.2, R39.2, R40.1, R42.1, R43.1, R47.1, R49.1, R50.1, R51.1, R52.1, R54.1, R56.1, R57.1, R58.1, R59.1, R60.1, R61.1, R62.1, R63.1, R64.1, R65.1, R66.1, R67.1, R88.1, REMOVE_DEMUX1.16, SD_LOGGER1.5, SD_LOGGER1.6, U5.16, UI_PCB1.1, XKC-Y25V1.1, XKC-Y26A-V1.1
+12V: D17.1, D21.2, F4.1, F5.1, F6.1, F7.1, F8.1, F9.1, PSU_12VOUT1.1, Q45.1, Q45.2, Q45.3
/5V+in: MCU_heating_in1.1, R5.1, U1.5
/Aref: BT_D2.1, C1.2, J1.7
/Dpad_down: PANEL_DECODE1.11, R51.2, U5.14, UI_PCB1.9
/Dpad_left: PANEL_DECODE1.10, R49.2, U5.3, UI_PCB1.5
/Dpad_right: PANEL_DECODE1.12, R40.2, U5.13, UI_PCB1.7
/Dpad_up: PANEL_DECODE1.9, R50.2, U5.4, UI_PCB1.3
/cancel: PANEL_DECODE1.8, R54.2, U5.5, UI_PCB1.6
/heat_PWMo: MCU_HEAT_OUT1.2, Q1.2
/heat_control: C2.2, C3.2, HE1.1, Q2.1
/reset: BT_PWR1.1, ICSP1.6, J1.8, J2.6
/select: PANEL_DECODE1.7, R52.2, U5.6, UI_PCB1.4
A0: J4.1, PANEL_DECODE1.4
A1: J4.2, R1.2
A2: J4.3, R8.1
A3: J4.4, JOYSTICK2R1.12
A4: EXTRA1.18, J4.5
A8: J4.9, Q15.1, R29.2
A9: BZ1.1, J4.10
A10: J4.11, JOYSTICK2R1.11
A11: EXTRA1.19, J4.12
A12: EXTRA1.20, J4.13
A13: EXTRA1.21, J4.14
A14: EXTRA1.22, J4.15
A15: J4.16, MCU_HEAT_OUT1.3
D2: J1.11, Q1.1, R7.2
D3: J1.12, R88.2, U5.12, UI_PCB1.8
D4: EXTRA1.11, J1.13
D5: J1.14, MOTOR1.3
D6: EXTRA1.10, J1.15
D7: J1.16, REMOVE_DEMUX1.9
D8: J1.17, REMOVE_DEMUX1.10
D9: J1.18, REMOVE_DEMUX1.11
D10: ADD_DEMUX1.9, J1.19
D11: ADD_DEMUX1.10, J1.20
D12: ADD_DEMUX1.11, J1.21
D13: EXTRA1.9, J1.22, U5.1
D14: J1.23, U5.2
D15: J1.24, R47.2, U5.9
D16: EXTRA1.12, J1.25
D17: EXTRA1.13, J1.26
D18: EXTRA1.14, J1.27
D19: EXTRA1.15, J1.28
D20: EXTRA1.16, I2C_CP8000.3, I2C_TANK1.3, J1.29, R12.2
D21: EXTRA1.17, I2C_CP8000.2, I2C_TANK1.2, J1.30, R13.2
D22: J1.31, JOYSTICK2R1.4
D23: J1.32, JOYSTICK2R1.3
D24: J1.33, JOYSTICK2R1.6
D25: J1.34, JOYSTICK2R1.5
D26: J1.35, JOYSTICK2R1.10
D27: HEAT_SENSE1.2, J1.36, R14.2
D28: J1.37, R11.2, XKC-Y26A-V1.2
D29: J1.38, R15.2, XKC-Y25V1.2
D30: J1.39, R42.2, R44.1
D31: J1.40, R43.2, R45.1
D32: EXTRA1.6, J4.17
D33: EXTRA1.5, J4.18
D34: EXTRA1.8, J4.19
D35: EXTRA1.7, J4.20
D36: J4.21, Q33.1, R16.2
D39: J4.24, R30.1, R32.1
D40: J4.25, R35.1, R36.1
D41: J4.26, R38.1, R39.1
D42: J4.27, LCD_SHORT_OUT1.8
D43: J4.28, LCD_SHORT_OUT1.7
D44: J4.29, LCD_SHORT_OUT1.6
D45: J4.30, LCD_SHORT_OUT1.5
D46: J4.31, LCD_SHORT_OUT1.4
D47: J4.32, LCD_SHORT_OUT1.3
D48: BT_D2.7, J3.1
D49: J3.2, U5.11, UI_PCB1.2
D50: ICSP1.2, J2.2, J3.3, SD_LOGGER1.13, SD_LOGGER1.14
D51: ICSP1.3, J2.3, J3.4, SD_LOGGER1.9, SD_LOGGER1.10
D52: ICSP1.4, J2.4, J3.5, SD_LOGGER1.11, SD_LOGGER1.12
D53: BT_D2.6, J3.6, SD_LOGGER1.7, SD_LOGGER1.8
unnamed: ADD_DEMUX1.1, R26.2, R64.2
unnamed: ADD_DEMUX1.2, R24.2, R67.2
unnamed: ADD_DEMUX1.5, R28.2, R66.2
unnamed: ADD_DEMUX1.12, R23.2, R62.2
unnamed: ADD_DEMUX1.14, R18.2, R58.2
unnamed: ADD_DEMUX1.15, R20.2, R60.2
unnamed: ADD_PUMP1.1, D3.1, F5.2
unnamed: ADD_PUMP1.2, D3.2, Q31.2
unnamed: ADD_VALVE1.1, D1.2, Q18.2
unnamed: ADD_VALVE1.2, D6.2, Q21.2
unnamed: ADD_VALVE1.3, D7.2, Q23.2
unnamed: ADD_VALVE1.4, D8.2, Q25.2
unnamed: ADD_VALVE1.5, D9.2, Q27.2
unnamed: ADD_VALVE1.6, D10.2, Q29.2
unnamed: BR1.1, U1.1
unnamed: BR1.2, R2.1
unnamed: BR1.3, R4.1
unnamed: BR1.4, U1.2
unnamed: BZ1.2, R31.1, R34.1
unnamed: C2.1, R6.2, R9.1
unnamed: C3.1, R10.2
unnamed: D1.1, D6.1, D7.1, D8.1, D9.1, D10.1, F7.2, VALVE12V1.1
unnamed: D2.1, F4.2, SOAK_PUMP1.1
unnamed: D2.2, Q20.2, SOAK_PUMP1.2
unnamed: D4.1, F8.2, REMOVE_PUMP1.1
unnamed: D4.2, Q34.2, REMOVE_PUMP1.2
unnamed: D5.1, F9.2, MOTOR1.1
unnamed: D5.2, MOTOR1.4, Q38.2
unnamed: D11.1, D12.1, D13.1, D14.1, D15.1, D16.1, F6.2, VALVE12V1.2
unnamed: D11.2, Q17.2, REMOVE_VALVE1.1
unnamed: D12.2, Q19.2, REMOVE_VALVE1.2
unnamed: D13.2, Q22.2, REMOVE_VALVE1.3
unnamed: D14.2, Q24.2, REMOVE_VALVE1.4
unnamed: D15.2, Q26.2, REMOVE_VALVE1.5
unnamed: D16.2, Q28.2, REMOVE_VALVE1.6
unnamed: D17.2, Q45.4, R86.1
unnamed: D18.2, Q46.4, R87.1
unnamed: D19.2, R53.1
unnamed: D20.2, R55.1
unnamed: D21.1, R80.1
unnamed: D22.1, R81.1
unnamed: LCD_SHORT_OUT1.2, Q33.2
unnamed: MCU_heating_in1.2, U3.2
unnamed: MCU_heating_in1.3, R3.1, U1.4
unnamed: MOTOR1.2, Q36.2
unnamed: Q2.3, U3.4
unnamed: Q3.1, R17.1
unnamed: Q4.1, R18.1
unnamed: Q5.1, R19.1
unnamed: Q6.1, R20.1
unnamed: Q7.1, R21.1
unnamed: Q8.1, R23.1
unnamed: Q9.1, R25.1
unnamed: Q10.1, R26.1
unnamed: Q10.3, Q25.1, R73.2
unnamed: Q11.1, R27.1
unnamed: Q11.3, Q26.1, R78.2
unnamed: Q12.1, R28.1
unnamed: Q12.3, Q27.1, R75.2
unnamed: Q13.1, R30.2
unnamed: Q13.3, Q20.1, R33.2
unnamed: Q14.1, R22.1
unnamed: Q14.3, Q28.1, R79.2
unnamed: Q15.2, R31.2
unnamed: Q16.1, R24.1
unnamed: Q16.3, Q29.1, R77.2
unnamed: Q3.3, Q17.1, R70.2
unnamed: Q4.3, Q18.1, R68.2
unnamed: Q5.3, Q19.1, R72.2
unnamed: Q6.3, Q21.1, R69.2
unnamed: Q7.3, Q22.1, R74.2
unnamed: Q8.3, Q23.1, R71.2
unnamed: Q9.3, Q24.1, R76.2
unnamed: Q30.1, R35.2
unnamed: Q30.3, Q31.1, R37.2
unnamed: Q32.1, R38.2
unnamed: Q32.3, Q34.1, R41.2
unnamed: Q35.1, R44.2
unnamed: Q35.3, Q36.1, R48.1
unnamed: Q37.1, R45.2
unnamed: Q37.3, Q38.1, R46.2
unnamed: R5.2, U3.1
unnamed: R6.1, U3.6
unnamed: R17.2, R56.2, REMOVE_DEMUX1.14
unnamed: R19.2, R57.2, REMOVE_DEMUX1.15
unnamed: R21.2, R59.2, REMOVE_DEMUX1.12
unnamed: R22.2, R65.2, REMOVE_DEMUX1.2
unnamed: R25.2, R61.2, REMOVE_DEMUX1.1
unnamed: R27.2, R63.2, REMOVE_DEMUX1.5
PSU_12V+: D19.1, PSU_12V1.1, Q45.5, Q45.6, Q45.7, Q45.8, Q45.9
PSU_12VGND: 7V-PSU-IN1.2, ADD_DEMUX1.3, ADD_DEMUX1.6, ADD_DEMUX1.7, ADD_DEMUX1.8, BT_D2.2, BT_PWR1.4, BT_PWR1.5, C1.1, C4.2, C5.2, C6.2, EXTRA1.23, EXTRA1.24, HEAT_SENSE1.3, I2C_CP8000.4, I2C_TANK1.4, ICSP1.5, J1.1, J1.2, J2.5, JOYSTICK2R1.1, LCD_SHORT_OUT1.1, LCD_SHORT_OUT1.10, MCU_HEAT_OUT1.4, MCU_heating_in1.4, PANEL_DECODE1.1, PANEL_DECODE1.5, PANEL_DECODE1.6, PANEL_DECODE1.15, PANEL_DECODE1.16, PSU_5V1.2, PSU_12V1.2, PSU_12VOUT1.2, Q1.3, Q3.2, Q4.2, Q5.2, Q6.2, Q7.2, Q8.2, Q9.2, Q10.2, Q11.2, Q12.2, Q13.2, Q14.2, Q15.3, Q16.2, Q17.3, Q18.3, Q19.3, Q20.3, Q21.3, Q22.3, Q23.3, Q24.3, Q25.3, Q26.3, Q27.3, Q28.3, Q29.3, Q30.2, Q31.3, Q32.2, Q33.3, Q34.3, Q35.2, Q36.3, Q37.2, Q38.3, R3.2, R8.2, R34.2, R53.2, R55.2, R80.2, R81.2, R86.2, R87.2, REMOVE_DEMUX1.3, REMOVE_DEMUX1.6, REMOVE_DEMUX1.7, REMOVE_DEMUX1.8, SD_LOGGER1.15, SD_LOGGER1.16, U4.1, U5.8, U5.10, U5.15, UI_PCB1.10, XKC-Y25V1.3, XKC-Y25V1.4, XKC-Y26A-V1.3, XKC-Y26A-V1.4
PSU_V+: C4.1, D18.1, D22.2, F3.1, Q46.1, Q46.2, Q46.3, U4.3
PSU_VIN: 7V-PSU-IN1.1, D20.1, Q46.5, Q46.6, Q46.7, Q46.8, Q46.9
Vin: BT_PWR1.6, F3.2, PSU_5V2.1, PSU_5V2.2

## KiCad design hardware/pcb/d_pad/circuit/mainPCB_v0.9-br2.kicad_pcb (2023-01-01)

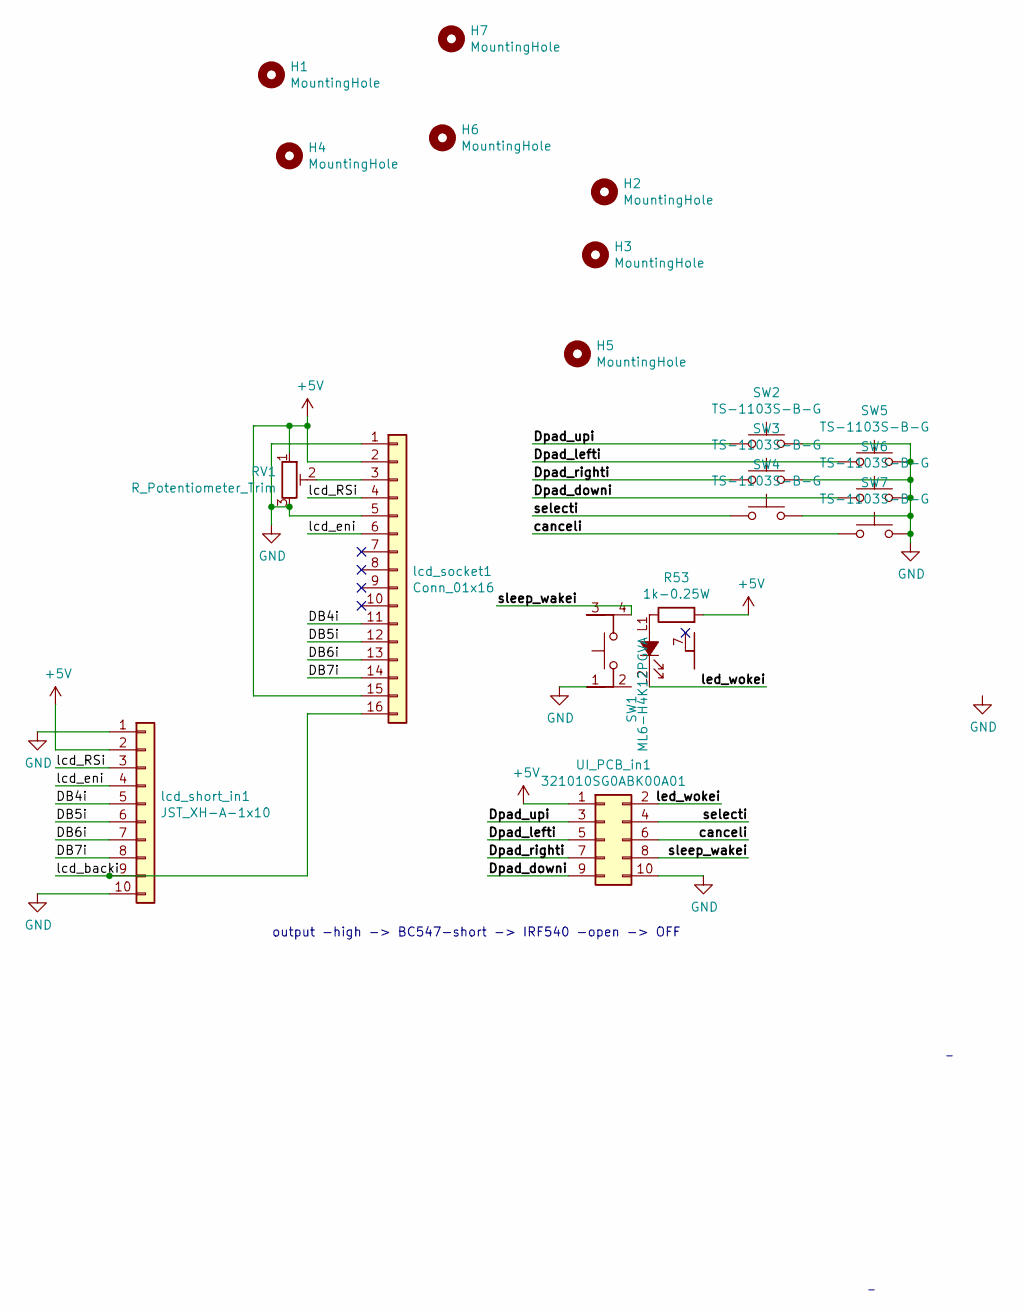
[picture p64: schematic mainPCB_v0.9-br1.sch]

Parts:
H1, H2, H3, H4, H6, H7: MountingHole; MountingHole_3.2mm_M3
H5: MountingHole; MountingHole_4.5mm
R53: 1k-0.25W; R_1206_3216Metric; LCSC C4410
RV1: R_Potentiometer_Trim; VG039NCHXTB102; LCSC C128543
SW1: ML6-H4K12PGVA; ML6-H4; LCSC C225014
SW2, SW3, SW4, SW5, SW6, SW7: TS-1103S-B-G; TS-1103S-X-X; LCSC C480306
UI_PCB_in1: 321010SG0ABK00A01; IDC-Header_2x05_P2.54mm_Vertical; LCSC C49661
lcd_short_in1: JST_XH-A-1x10; JST_XH_B10B-XH-A_1x10_P2.50mm_Vertical; LCSC C144400
lcd_socket1: Conn_01x16; PinHeader_1x16_P2.54mm_Vertical; LCSC C49661

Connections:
+5V: R53.2, RV1.1, UI_PCB_in1.1, lcd_short_in1.2, lcd_socket1.2, lcd_socket1.15
/DB4i: lcd_short_in1.5, lcd_socket1.11
/DB5i: lcd_short_in1.6, lcd_socket1.12
/DB6i: lcd_short_in1.7, lcd_socket1.13
/DB7i: lcd_short_in1.8, lcd_socket1.14
/Dpad_downi: SW6.1, UI_PCB_in1.9
/Dpad_lefti: SW5.1, UI_PCB_in1.5
/Dpad_righti: SW3.1, UI_PCB_in1.7
/Dpad_upi: SW2.1, UI_PCB_in1.3
/canceli: SW7.1, UI_PCB_in1.6
/lcd_RSi: lcd_short_in1.3, lcd_socket1.4
/lcd_backi: lcd_short_in1.9, lcd_socket1.16
/lcd_eni: lcd_short_in1.4, lcd_socket1.6
/led_wokei: SW1.L2 (K), UI_PCB_in1.2
/selecti: SW4.1, UI_PCB_in1.4
/sleep_wakei: SW1.4, UI_PCB_in1.8
GND: RV1.3, SW1.1, SW2.2, SW3.2, SW4.2, SW5.2, SW6.2, SW7.2, UI_PCB_in1.10, lcd_short_in1.1, lcd_short_in1.10, lcd_socket1.1, lcd_socket1.5
unnamed: R53.1, SW1.L1 (A)
unnamed: RV1.2, lcd_socket1.3

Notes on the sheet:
output -high -> BC547-short -> IRF540 -open -> OFF

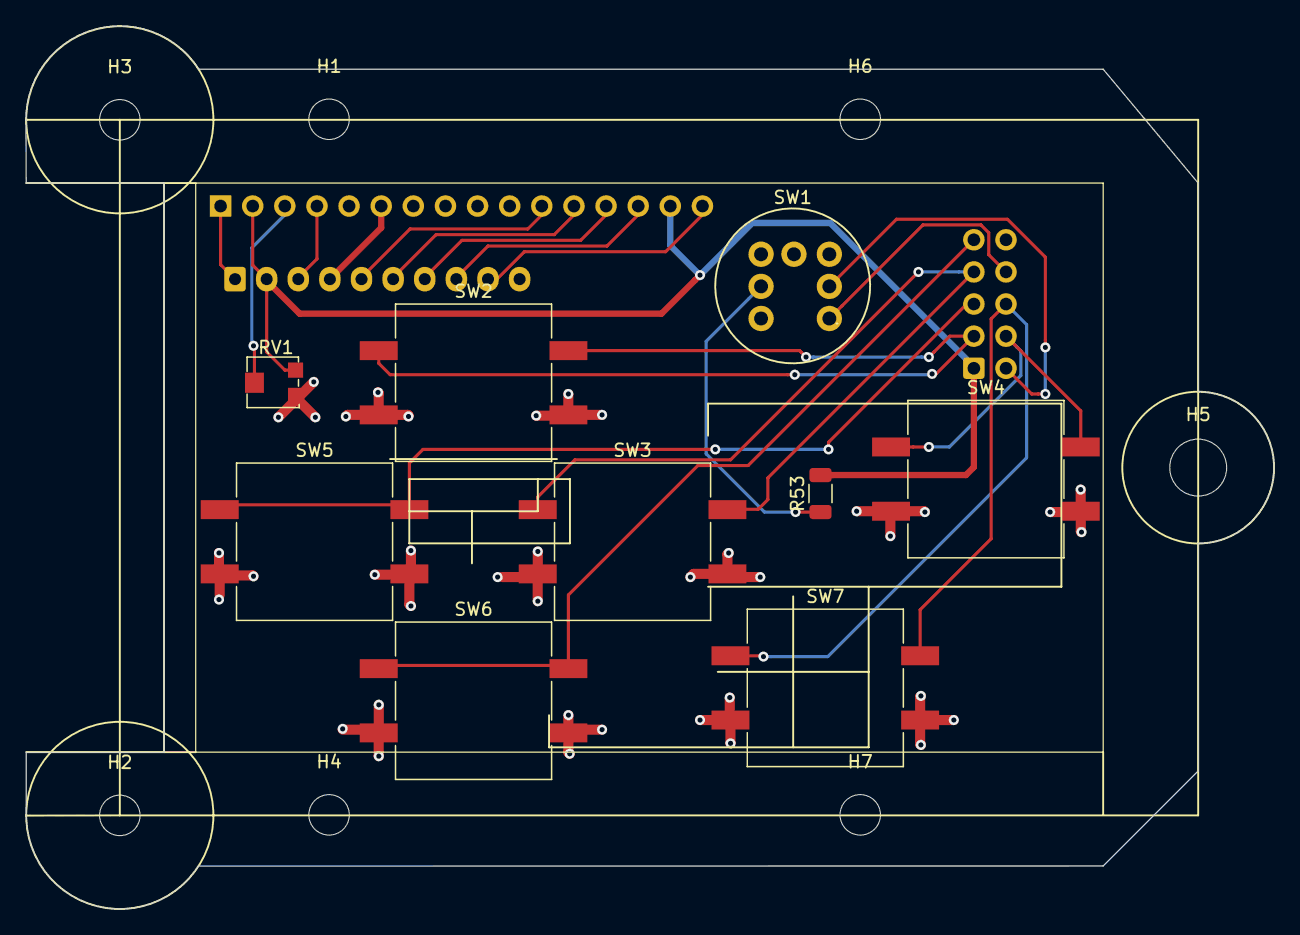
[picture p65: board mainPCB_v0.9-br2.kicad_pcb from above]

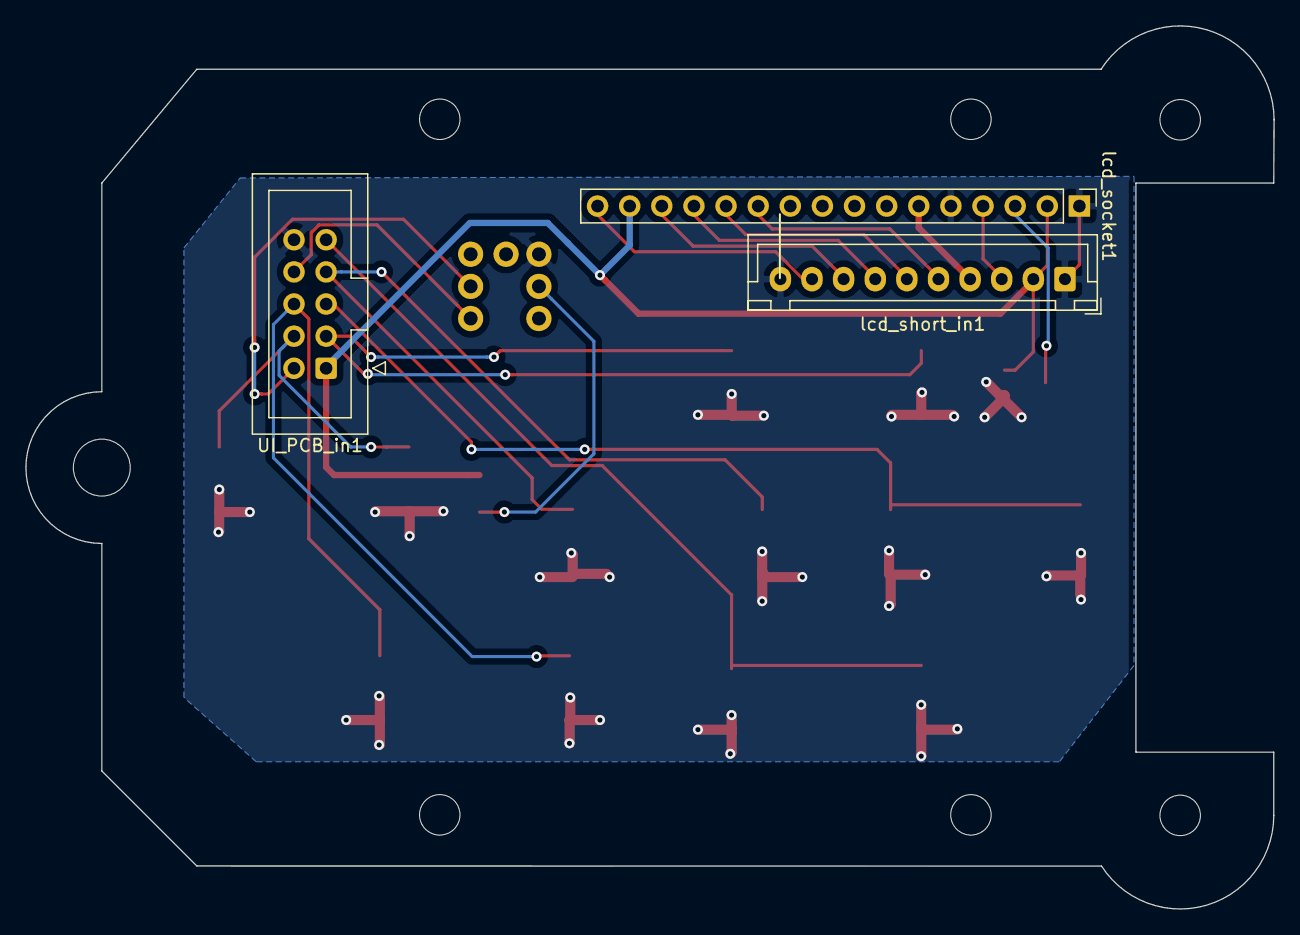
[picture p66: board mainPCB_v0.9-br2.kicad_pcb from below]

Board: 2 copper layers, 98.7 x 69.8 mm, 19 parts (3 on the bottom side), 19 nets.

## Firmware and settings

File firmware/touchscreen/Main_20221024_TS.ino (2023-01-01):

#define model "CP-806"
#define version "1.16.2"
#define PCBver 9
// sense =0 for NO sensor, and =1 for NC sensor
#define OUTsense 1// change this to 1 when use the new flow sensor with the metal band and cable tie
#define INsense 0
/********************************************************
// see dev_log for all historical changes and patches //
********************************************************/
//#define DEBUG //enable/disable serial debug output

#ifdef DEBUG
#define DEBUG_PRINT(x) Serial.print(x)
#define DEBUG_PRINTDEC(x) Serial.print(x, DEC)
#define DEBUG_PRINTbin(x,y) Serial.print(x, y)
#define DEBUG_PRINTbinln(x,y) Serial.println(x, y)
#define DEBUG_PRINTln(x) Serial.println(x)
#else
#define DEBUG_PRINT(x)
#define DEBUG_PRINTDEC(x)
#define DEBUG_PRINTbin(x,y) 
#define DEBUG_PRINTbinln(x,y)
#define DEBUG_PRINTln(x)
#endif

void EditsParameters(int editIndex,int arrayIndex,int * Para,int push);

// button assignment

#if PCBver == 9
  #define A_button 0b10000000
  #define B_button 0b01000000
  #define Up_button 0b00100000
  #define Left_button 0b00010000
  #define Down_button 0b00001000
  #define Right_button 0b00000100
  #define C_button 0b00000010
  #define D_button 0b00000001
  #define A_shift 7
  #define B_shift 6
  #define Up_shift 5
  #define Left_shift 4
  #define Down_shift 3
  #define Right_shift 2
  #define C_shift 1
  #define D_shift 0
#else 
  #define A_button 0b00001000
  #define B_button 0b00000100
  #define Up_button 0b10000000 
  #define Left_button 0b01000000
  #define Down_button 0b00010000
  #define Right_button 0b00100000
  #define C_button 0b00000010
  #define D_button 0b00000001
  #define A_shift 3
  #define B_shift 2
  #define Up_shift 7
  #define Left_shift 6
  #define Down_shift 4
  #define Right_shift 5
  #define C_shift 1
  #define D_shift 0
#endif

// includes library

//#include <ArduinoTrace.h>
#include <OneWire.h>
#include <DallasTemperature.h>

//pin assignment

#define LED_woke 49 //pin led for woke status
#define Dpad_in_pin A0
#define Dpad_refH_pin A1
#define Dpad_refL_pin A2

#define KEYA 22
#define KEYB 23
#define KEYC 24
#define KEYD 25
#define KEYE 
#define KEYF 
#define KEYK 26
#define JOYX A3
#define JOYY A10

#define volume_pin A8
#define buzz_pin A9
#define wake_pin 3
#define remove_s0 9
#define remove_s1 8
#define remove_s2 7
#define add_s0 12
#define add_s1 11
#define add_s2 10
#define SD_MISO 50
#define SD_MOSI 51
#define SD_SCK 52
#define SD_SS 53

#define tanks_full A5
#define tanks_half A6
#define tanks_low A7
#define AC_zero A15

#define soak_pump 39
#define add_pump 40
#define remove_pump 41

#define motor_PWM 5
#define heat_PWM 2

#define drum_high 29
#define drum_empty 28

#define motor_on 31
#define motor_dir 30

#define LEVEL_SAMPLE_SIZE 20

//button
#define buttonPin A0 //buttteon resistor ladder analog Pin
//int buttonVal[6] = {LOW, LOW, LOW, LOW, LOW, LOW}; //button Value
//int buttonPinVal = 0; //button pin analog read
//button debounce and de-sticky
//int buttonPinValPrevious = 0; //value for debounce
//unsigned long buttonTimer = 0; //timer for de-sticky (ms)
//int buttonDelay = 400; //time for de-sticky (ms)
//int buttonPinValMark[6] = {560, 605, 675, 725, 755, 780}; //mark value for button pin
//right, down, left, cancel, up, confirm
byte UIcommend; // debounced byte commend to the system from UI inputs
byte UIinputs; // before debounced
int de_button;
int editing = 0; // default program editing is off
int menu_skipupdate=0;


// touchscreen

#include <MCUFRIEND_kbv.h>
MCUFRIEND_kbv tft;       // hard-wired for UNO shields anyway.
#include <TouchScreen.h>

#define Orientation 1   //PORTRAIT = 0
#define textsize 2
//all pin has to be addigned thru the mcufriend_shield.h
#define YP A14  //must be an analog pin, use "An" notation!, position on breakout board is LCD_CS
#define XM A13  //  must be an analog pin, use "An" notation!, position on breakout board is LCD_RS
#define YM 23   // can be a digital pin, position on breakout board is LCD_D1
#define XP 22   // can be a digital pin, position on breakout board is LCD_D0
#define ROW_ONE 8
#define ROW_TWO 64
#define ROW_THREE 120
#define ROW_FOUR 176

#if (Orientation==0)
  #define TS_LEFT 901  // must be an analog pin, use "An" notation!
  #define TS_RT 128  // must be an analog pin, use "An" notation!
  #define TS_TOP 103   // can be a digital pin
  #define TS_BOT 903   // can be a digital pin
#elif(Orientation==1)
  #define TS_LEFT 103  // must be an analog pin, use "An" notation!
  #define TS_RT 903  // must be an analog pin, use "An" notation!
  #define TS_TOP 128   // can be a digital pin
  #define TS_BOT 901   // can be a digital pin
#endif

TouchScreen ts = TouchScreen(XP, YP, XM, YM, 300);
TSPoint tp;


#define MINPRESSURE 200
#define MAXPRESSURE 1000



/*
 * note for display usig touch screen
 * the old screen has 4 row, so we can have 60 pix each row 
 * however from visual inspection, text size 2 (12ptpx width by 8 px height *2)is sufficient for visibility
 * so at max we can have 15 rows and and 20 column
 * we would like to centre the menaul, most menus is 6 rows long, 
 * thus we could afford to use double row. 
 * given nobody like to look at the edge of the screen from top and bottom is useuse
 * 
 * the layout is yet to be review and readjust as of 20220928
 * 
 */


// Assign human-readable names to some common 16-bit color values:
#define BLACK   0x0000
#define BLUE    0x001F
#define RED     0xF800
#define GREEN   0x03E0
#define CYAN    0x07FF
#define MAGENTA 0xF81F
#define YELLOW  0xFFE0
#define WHITE   0xFFFF

#include "classes.h"
#include "CP800.h"

//LCD
//#include <LiquidCrystal.h>
//#define rs 42
//#define ee 43
//#define d4 44
//#define d5 45
//#define d6 46
//#define d7 47 //LCD Pin
//#define bl 36 
//
//LiquidCrystal lcd(rs, ee, d4, d5, d6, d7);

//display 
char lcdBuff0[21];
char lcdBuff1[21];
char lcdBuff2[21];
char lcdBuff3[21];

//char lcdBuffPrevious0[21];
//char lcdBuffPrevious1[21];
//char lcdBuffPrevious2[21];
//char lcdBuffPrevious3[21];

//menu
//menu structure see attached document
int menuRow = 0;
int menuColumn = 0;
int infopage = 0; //there will be multiple info page as we expand the complexity
const String menuTop[] = { //top tier menu text
  "Info Screen",
  "Start Processing",
  "Stop/Clean Process",
  "Last Processing",
  "Edit Process",
  "Settings"
};
const String menuSetting[] = { //declear settings menu
  "Input Check",
  "Output Check",
};


//edit menu
//int maxcol=3; // the least amount of column index the editing menu will have, change by updating numerofstep
int editIndex = 0;
int editPara[19]; // edipara is a array, mostly will be only using the first entry
int arrayIndex = 0;
bool editmenuEnd=0;
bool saving=0;


//I/O Check
bool outputCheckAction = 0;
//Input/Output Check Mode
bool IOCheckMode = 0;
int IOIndex = 0;

//declear process matrix
String processPara[8][20] = { //6 process + 2 clean process
  {}, {}, {}, {}, {}, {}, {}, {}
};
int processTemp[8] = {0, 0, 0, 0, 0, 0, 0, 0};
uint16_t processTime[8] = {0, 0, 0, 0, 0, 0, 0, 0};
uint8_t processTotalSteps[8] = {0, 0, 0, 0, 0, 0, 0, 0};
bool processParaSet[8] = {0, 0, 0, 0, 0, 0, 0, 0};

//process name
String processName[6] = {"---", "---", "---", "---", "---", "---"};

//processing data
//timer
unsigned long timer = 0; //system timer (mS)
long timeJump = 0; //jump forward time for testing (mS) - not using
#define iniDelay 200 //delay in setup (mS)

//refresh timer for lcd etc.
unsigned long refreshTimerA = 0; //timer for less frequent refresh (ms)
unsigned long refreshTimerB = 0; //timer for frequent refresh (ms)
#define refreshInterval 500 //time for lcd refresh (ms)

//agitation
byte agitationSpeed = 0; //0: ~20RMP 1: ~18RMP 2: ~16RPM
unsigned long agitationTimer = 0; // S - unused
const int agitationTime1 = 10; // S
const int agitationTime2 = 2; // S

//parameter of process
bool processState; //process runing state (0:not running 1:running)
int processNo; //runing process (0-7)
bool steppingmode=0; //default =0 : sensor mode, 1= fixed timer
unsigned long processStartTime = 0; //start time of current process

//parameter of clean process
byte processStateClean; //process runing state for clean process (0: not runing 1: clean 1 process 2: clean 2 process)
byte processCleanCycles;

//parameters for current step
bool stepState = 0; //step state (0: processing of this step is not done 1: processing of this step is done, ready to drain tank)
String stepName[20] = {"----"};
uint8_t stepNo = 0;
uint8_t stepIn[20]; //which port to add chem
uint16_t stepTime[20]; //time for processing (S)
uint8_t stepOut[20]; //which port to dump chem
bool stepPush[20]; //if this step is subject to push/pull 0:no 1:yes
bool flowin=0;
bool flowout=0;
int stepout = 0; // use to record what stepOut[stepNo] is

unsigned int stepTimer1 = 0; // begining of adding chem
unsigned int stepTimer2 = 0; // beigning of process the drum, stopped adding chem
unsigned int stepTimer3 = 0; // begining of removing chem, stpped the drum 
bool stepParaSet=0; //flag of step paratmeter are set, and ready to go

//push/pull
int push = 0; // the value of push/pull selected on the menu (this is loaded into the processing later)
int dummyroll =0; // the number of dummy rolls use in this processing

//error Message
String errorMessage = "";
unsigned long int popuptimer=0; 

#include <EEPROM.h>
int strByteLen = 200; //String Length limit in bytes
int addrShift = 0; //to shift byte for wear leveling

//SD card global
#include <SD.h>
#include <SPI.h>
#include <stdlib.h>

int SD_err =0; // 0: no err, 1: SD.begin error, 2: file load err, 3: step data load err
int program_no = 0; // count the number of program stored in the SD card file
int loadtype=0; // 1 is SD, and 0 is ROM, default from ROM
int validROMprogram[6] = {1,1,1,1,1,1};

//digital Temperature Sensor
#define tempPin 27 //DS18B20 signal bus
OneWire oneWire(tempPin); //Temperature chip i/o
DallasTemperature sensors(&oneWire);
//Temperature Control
float tempCurrent = -10.0;
float tempTarget = 22.0;

//instanstation of object
Led Led(LED_woke);
Buzzer buzz(buzz_pin,volume_pin);
SixWay_valve addChem(add_s0,add_s1,add_s2,add_pump);
SixWay_valve removeChem(remove_s0,remove_s1,remove_s2,remove_pump);
agitationMotor agitationMotor(motor_on, motor_dir, motor_PWM);
bathPump bathPump(soak_pump);
//tankLevel tankLevel;
//soakLevel soakLevel;
digilevel drumHI(drum_high,LEVEL_SAMPLE_SIZE, INsense );
digilevel drumempty(drum_empty,LEVEL_SAMPLE_SIZE, OUTsense);
//analoglevel chemtanks_full();
//analoglevel chemtanks_half();
//analoglevel chemtanks_low();
analoglevel soakLevel(tanks_full,LEVEL_SAMPLE_SIZE);
AC_heater heater(heat_PWM);
//joystick joystick(KEYA,KEYB,KEYC,KEYD, KEYK, JOYX, JOYY);
//Dpad_analog panel_UI(Dpad_in_pin, Dpad_refH_pin, Dpad_refL_pin);
onscreen_UI onscreen_UI(XM, YP, Orientation);

UIcursor user_navi(&UIcommend); 
UImap menu_navi(&UIcommend);

void setup() { //********************************************set up
  
//  pinMode(bl,OUTPUT);
//  digitalWrite(bl,HIGH);
  //button
//  pinMode(buttonPin, INPUT);

  //serial
  Serial.begin(115200);
  //load data struct of processing
  sketchPrograms();
  delay(100); 
  //LCD << redundant
//  lcd.begin(20, 4);
//  lcd.setCursor(0, 0);
//  lcd.print(model);
//  lcd.print(" ");
//  lcd.print(version);

  tft.reset();
  uint16_t ID = tft.readID();
  tft.begin(ID);
  tft.setRotation(Orientation); //set screen orientation: 0=portait ,1=landscape
  tft.fillScreen(BLACK); //show black screen
  tft.setTextSize(textsize); //12 wide by 16 tall
  
  tft.setTextColor(YELLOW, BLACK);
  tft.setCursor(0, ROW_ONE);
  tft.print(model);
  tft.print(" ");
  tft.print(version);
//  lcd.setCursor(0, 1);
//  lcd.print("FND");
  tft.setCursor(0, ROW_TWO);
  tft.print("FND");
  //Initialising Message
//  lcd.setCursor(0, 2);
//  lcd.print("Initialising..."); << redundant
  tft.fillRect(0, ROW_THREE, 240, 56, BLACK);
  tft.setCursor(0, ROW_THREE);
  tft.print("Initialising");
  // touchescreen


 //initiate UI controls
  //joystick.Begin();
  //panel_UI.begin();
  
  UIinputs = onscreen_UI.status_reg;
  user_navi.begin();
  menu_navi.begin();
  //calibreate A0 reading for buttons
  //press any key when booting up
//  if (analogRead(buttonPin) > 400) {
//    calibreateButtonPinMark();
//    buzz.play_Note(500,500);
//  }
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
void loop() { //********************************************loop
 // int statepageEnd=0; // obselete as of 20210 10 28, could be useful again, if there are bug related holding the buttons down
  //checking variables from Serial
  if (Serial.available() > 0) {
    checkVariable ();
  }

  //system timer
  timer = millis() + timeJump;
  
  //keep level sensor updated
  drumHI.queue();
  drumempty.queue();
  soakLevel.queue();
  
  tp = ts.getPoint();
  onscreen_UI.begin();
   bool UIchanged = onscreen_UI.Update(tp) ; //update is 1, so either update will change this to 0,, joystick.Update() & panel_UI.Update() &
   DEBUG_PRINT (UIchanged);
   if (UIchanged==0){
    refresh =2;
   }

  
  
 // bool UIchanged = panel_UI.Update(); // update input buttons, retunr if input are changed
  //byte buttons = panel_UI.getinputs(); // get the actual value of the buttons
  // bool UIchanged = joystick.Update();
  // byte buttons = joystick.status_reg & 0xFC;
  

   byte buttons =  onscreen_UI.status_reg;// & joystick.status_reg;// all default signla are 1 , so A & B wil take either one method or the other
   DEBUG_PRINT(" ");
   DEBUG_PRINT(onscreen_UI.status_reg);
   
  // update as often as input

  // debounce inputs button with a change that last more than two cycle
  int debounce_change = debouncer(int(buttons), &de_button); //return if there is a chang ein debounce signal
  UIcommend = de_button | 1; // enebale  row but not col shift
  DEBUG_PRINT(" ");
  DEBUG_PRINT(UIcommend);
  buttonAction_new(UIcommend, debounce_change);
  if (menu_skipupdate==0){
    user_navi.Update(ispageEnd,min(4,pagerow)); // update user curver row location with page info
    menu_navi.Update(ispageEnd,pagerow); // update system map location with page info
  }
  menu_skipupdate=0; //reset skipupdate for next cycle
  
  int thislayer= menu_navi.layer; //get layer number, each A press create a new layer
  // get the page idenitification based on ohw many layer and which row of each layer when A is pressed
  int pageID=0;
  pageID = (rowstack[0][1]+(thislayer>0))*1 + (rowstack[1][1]+(thislayer>1))*10 + (rowstack[2][1]+(thislayer>2))*100;
  // buttion Action change the system system depending on the current state and the input command
  int A, B, C;
  
  if (UIchanged==0 || refresh !=0){
   refresh -=1;
   lcdWrite1(); //write screen according to previous determined state 
   
  }
//  panel_UI.getvolts(&A, &B, &C);
//  Serial.print(" ");
//  Serial.print(A);
//  Serial.print(" ");
//  Serial.print(B);
//  Serial.print(" ");
//  Serial.print(C);
//  Serial.println(" ");
  DEBUG_PRINT(" ");
  
  //statepageEnd=ispageEnd;  // obselete as of 20210 10 28
  DEBUG_PRINT(" ");
  DEBUG_PRINTbin(UIcommend, BIN);
  DEBUG_PRINT(" ");
  DEBUG_PRINT(ispageEnd);
  DEBUG_PRINT(" ");
  DEBUG_PRINT(rowstack[0][1]);
  DEBUG_PRINT(rowstack[1][1]);
  DEBUG_PRINT(rowstack[2][1]);
  DEBUG_PRINT(rowstack[3][1]);
  DEBUG_PRINT(" ");
  DEBUG_PRINT(menu_navi.row); 
  DEBUG_PRINT(" ");
  DEBUG_PRINT(user_navi.row);
  DEBUG_PRINT(" ");
  DEBUG_PRINT(A);
  DEBUG_PRINT(" ");
  DEBUG_PRINT(B);
  DEBUG_PRINT(" ");
  DEBUG_PRINT(C);
  DEBUG_PRINT(" ");
  DEBUG_PRINT(drumHI.isON());
  DEBUG_PRINT(" ");
  DEBUG_PRINT(drumempty.isOFF());
  DEBUG_PRINT("\n");

  //update every 3S
  if (timer - refreshTimerA >= refreshInterval * 4) { //every 2 S

    //update LED
    LED();

    //soak tank heater disregard of processing state
    readTemp();
   // tempControl();

    if (processState == 1) {
      //update LCD
      lcdWrite1();
    }

    refreshTimerA = timer;
  }

  //update every 0.5S
  if (timer - refreshTimerB >= refreshInterval) {

    if (processState == 1) { //while processing

      //processing
      processing();

      //agitation motor
      agitation();

    }

    if (processStateClean > 0) {
      //clean process
      processClean();
    }

    refreshTimerB = timer;
  }
  //play soundtrack if there is any
  backgroundmusic(trackID, 0);
  //delay
  delay(10);

}


void checkVariable () {

  String incomingStr;
  String outputStr;

  incomingStr = Serial.readString();
  Serial.println("==================");
  Serial.print("Checking " + incomingStr);

  if (incomingStr == "processNo\n") {
    outputStr = String(processNo);
  }
  else {
    outputStr = "No Match";
  }

  Serial.println("= " + outputStr);
  Serial.println("==================");

}


void backgroundmusic(int trackID, int repeat){
  // if the current time is bigger than the previous note start plus note interval
  // note interval = 1000
  if(trackID>0 && trackArray[trackID].track[thisnote]!=-1){
    if((notetime+(NOTE_interval))< millis()){
      //play note
      buzz.play_Note(trackArray[trackID].track[thisnote], (1000/trackArray[trackID].tempo[thisnote]));
      //renew notetime to the next note starting time, 
      notetime=millis(); 
      //increment to the next note in the background music
      thisnote +=1;
    }
    if(trackArray[trackID].track[thisnote]==-1) { 
      // end of the melody
      if (repeat>0){
        thisnote=0;
      }
    }
  }else{
    buzz.no_note();
  }
}
void EditsParameters(int editIndex,int arrayIndex,int * Para,int push){
  /*
   * function to edit a existing process with the changes made by user with the menu
   * editindex indicate which parameter to change according to the parameter lookup table
   * array index indicate the number of entry in the paramter, currently only usefulf ro processName, as it is a char array
   * editpara is the menu buffer address for user to edit 
   * push, if this is one, the editpara is loaded to the variable indicated by the editindex, if 0, load from editindex variable to editpara
   * 
   * Process anem look up table
   *   const char* const paraNames[] = {"Process Name", "Process Duration (s)", "No. of Steps", "Temp (C)",
                                "Step Names", "Inlet Valve", "Step Duration (s)", "Outlet Valve", "Pushable"};
   */

  // static int changed=0; //<<redundant
  
  // if editindex>8, it loops back to 4 for each step , so 9->4, 10->5, 11->6, 12->7, 13->8...so on
  // editindex = 4+stepnum*4+stepind, for n=0,1,2,3,4 
  // stepindex = (editindex-4)%5, 
  // and, stepnum = floor((editindex-4)/5);
  int stepnum,stepindex; // the current step number being edit
  // step number is when we remove the flatten index of the process by the process header 0-3, we cycle back for everything 0,1,2,3,4
  stepnum = max(floor((editIndex-4)/5),0);
  stepindex = max((editIndex-4)%5,0);  // this is found to be reluncdent as of 2022/03/06
  // look up the data that are being edit
  Serial.print("paraindex:");
  Serial.println(editIndex - stepnum*5 + push*10);
  int menuIndex = editIndex  - stepnum*5 + push*10 + 32;
  Serial.print(menuIndex,DEC);
  switch (menuIndex) // if push is 0, pull is editindex, if push is 1, it is 10
  {
    default:{
//      Serial.println("defaykt");
      break;
    }
    case (32+11):{
      int inc = *Para;
      if (inc<0) inc=0;
      ROMProgram[rowstack[1][1]].duration = inc; //when push
 //     Serial.print("saved");
 //     Serial.print(ROMProgram[rowstack[1][1]].duration);
      break;
    }
    case (32+1):{
      *Para = ROMProgram[rowstack[1][1]].duration; //when pull
//      Serial.print("loaded");
//      Serial.print(*Para);
      break;
    }
    case (32+12):{
      int inc = *Para;
      if (inc<0) inc=0;
      ROMProgram[rowstack[1][1]].numberofstep = inc; //when push
      
      if (ROMProgram[rowstack[1][1]].processes == NULL){
        // if the pointer to the steps array is empty, create new array based on the push numberofstep
        ROMProgram[rowstack[1][1]].processes = new processStep[ROMProgram[rowstack[1][1]].numberofstep];
      }else { //if the array is defined delete existing array and update the size with the pushed numberofstep
        delete[] ROMProgram[rowstack[1][1]].processes;
        //recreated array with updated number of step
        ROMProgram[rowstack[1][1]].processes = new processStep[ROMProgram[rowstack[1][1]].numberofstep];
      }
      
//      Serial.print("saved");
//      Serial.print(ROMProgram[rowstack[1][1]].numberofstep);
      break;
    }
    case (32+2):{
      *Para = ROMProgram[rowstack[1][1]].numberofstep; //when pull
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

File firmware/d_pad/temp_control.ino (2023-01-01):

void tempControl() {

  if (IOCheckMode == 1) { //turn off heater in IO Mode
    if (heater.State() == 1) {
      heater.OFF();
    }
    return;
  }

  //Serial.println("tempControl //******");
  float difference = tempCurrent - tempTarget;
  //Serial.println("Difference is : " + String(difference));

  if (soakLevel.isOFF() == 1) { //if ehough soaking water

    //temp control loop
    if (difference < -1) { //need all power heating
      //Serial.println("Heater Full ON");
      if (heater.State() == 0) { //turn on if haven't
        heater.ON();
      }
    } else if (difference <= 0) { //need half power heating
      //Serial.println("Heater 25% ON");
      if (timer % 10000 <= 3000) { //heater ON for 3 S every 10 S

        if (heater.State() == 0) { //ON if haven't
          heater.ON();
        }
      } else {
        if (heater.State() == 1) { //OFF if haven't
          heater.OFF();
        }
      }
    } else if (difference > 0) { //no heating needed
      //Serial.println("Heater OFF");
      if (heater.State() == 1) { //turn off heater if haven't
        heater.OFF();
      }
    }
  } else { //if not enough saoking water
    errorCode(109);

    if (heater.State() == 1) { //turn off heater if haven't
      heater.OFF();
    }
  }

}

void readTemp() {

  //Serial.println("readTemp //*****");
  sensors.requestTemperatures();

  tempCurrent = sensors.getTempCByIndex(0);
  //Serial.println("Temperatur is: " + String(tempCurrent));

}

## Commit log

2022-07-16 Create CP800 Assembly document, videos and Inventory list
2022-10-28 Create CP800 PCBs
2022-10-28 Create CP800 arduino program
2022-10-28 Update CP800 arduino program
2022-12-19 Multiple changes, see description
    Added firmware and software files from sharepoint
    Set up mkdocs documentation
    Converted .docx files to .md
    Licensed source code under 3-clause BSD
    [ClutchHeadModified 220817.stl, D-Pad A Button - Gary Wong.stl, D-Pad B Button - Gary Wong.stl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]
2022-12-19 Add motherboard hardware files
    [mainPCB_v0.92-B_Cu.gbl, mainPCB_v0.92-B_Mask.gbs, mainPCB_v0.92-B_Paste.gbp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]

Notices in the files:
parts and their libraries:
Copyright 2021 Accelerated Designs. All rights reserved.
